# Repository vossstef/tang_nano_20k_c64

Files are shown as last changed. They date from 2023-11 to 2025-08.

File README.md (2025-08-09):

# C64Nano

The C64Nano is a port of some [MiST](https://github.com/mist-devel/mist-board/wiki) and
[MiSTer](https://mister-devel.github.io/MkDocs_MiSTer/) core components for the
[C64](https://en.wikipedia.org/wiki/Commodore_64):

| Board | FPGA | support |Note|
| --- | - | - |-|
| [Tang Nano 20k](https://wiki.sipeed.com/nano20k) | [GW2AR](https://www.gowinsemi.com/en/product/detail/38/)  | HDMI / LCD |Dualshock via MiSTeryShield20k spare header **or** Joy to DIP |
| [Tang Primer 25K](https://wiki.sipeed.com/hardware/en/tang/tang-primer-25k/primer-25k.html) | [GW5A-25](https://www.gowinsemi.com/en/product/detail/60/) | HDMI |no Dualshock, no Retro D9 Joystick, no MIDI |
| [Tang Mega 60k NEO](https://wiki.sipeed.com/hardware/en/tang/tang-mega-60k/mega-60k.html) | [GW5AT-60](https://www.gowinsemi.com/en/product/detail/60/) | HDMI / LCD | twin Dualshock |
| [Tang Mega 138k Pro](https://wiki.sipeed.com/hardware/en/tang/tang-mega-138k/mega-138k-pro.html)|[GW5AST-138](https://www.gowinsemi.com/en/product/detail/60/) | HDMI / LCD |twin Dualshock |
| [Tang Console 60K NEO](https://wiki.sipeed.com/hardware/en/tang/tang-console/mega-console.html)|[GW5AT-60](https://www.gowinsemi.com/en/product/detail/60/) | HDMI / LCD |twin Dualshock, no Retro D9 Joystick|

Be aware that the [VIC20](https://en.wikipedia.org/wiki/VIC-20) ([VIC20Nano](https://github.com/vossstef/VIC20Nano)),
[Atari 2600 VCS](https://en.wikipedia.org/wiki/Atari_2600) ([A2600Nano](https://github.com/vossstef/A2600Nano)), [Apple IIe](https://en.wikipedia.org/wiki/Apple_IIe) ([NanoApple2](https://github.com/vossstef/NanoApple2)) had been ported too in similar manner.  

This project relies on an external µC being connected to the Tang Nano 20K. You can use a [M0S Dock BL616](https://wiki.sipeed.com/hardware/en/maixzero/m0s/m0s.html), [Raspberry Pi Pico (W)](https://www.raspberrypi.com/documentation/microcontrollers/pico-series.html) or [esp32-s2](https://www.espressif.com/en/products/socs/esp32-s2)/[s3](https://www.espressif.com/en/products/socs/esp32-s3) and use the [FPGA companion firmware](http://github.com/harbaum/FPGA-Companion). Basically a µC acts as USB host for USB devices and as an OSD controller using a [SPI communication protocol](https://github.com/harbaum/MiSTeryNano/blob/main/SPI.md).

Onboard BL616 µC  
* If you don't need the WIFI modem on a TN20K then even the onboard BL616 µC (normally used for bitstream programming) can be used. A dedicated FPGA bitstream and FPGA companion firmware is needed in that configuration. The onboard BL616 µC is presently supported for TN20K and Console 60K boards. WIFI modem is supported on Console 60K too. There is an extern powered (see ->) [USB Hub](https://github.com/harbaum/FPGA-Companion/blob/main/console_usbhub_and_power_over_usb-a.png) + USB-A to USB-A cable + USB-A Power Supply Plug needed to supply the board and at the same time provide USB ports for USB Keyboard and e.g. USB Joystick or Mouse.

For the [M0S Dock](https://wiki.sipeed.com/hardware/en/maixzero/m0s/m0s.html) BL616 [µC](https://en.bouffalolab.com) there is a:

* [Optional custom carrier board MiSTeryShield20k](https://github.com/harbaum/MiSTeryNano/tree/main/board/misteryshield20k/README.md)
* [M0S PMOD Adapter](https://github.com/harbaum/MiSTeryNano/blob/main/board/m0s_pmod) for Primer / Mega / Console Boards
* [Optional case](https://github.com/harbaum/MiSTeryNano/blob/main/board/misteryshield20k/housing3D)
* [Dualshock Adapter / Cable](/board/misteryshield20k_ds2_adapter/misteryshield20k_ds2_adapter_cable.md)

and for the Raspberry PiPico (RP2040 µC) there is a:

* [Optional custom carrier board MiSTeryShield20k Raspberry PiPico](/board/misteryshield20k_rpipico/README.md)
* [Dualshock Adapter / Cable](/board/misteryshield20k_ds2_adapter/misteryshield20k_ds2_adapter_cable.md)
* [Optional custom PMOD RP2040-Zero](/board/pizero_pmod/README.md) for Primer / Mega / Console Boards
* [Optional custom PMOD PiPico W](/board/pipico_pmod/README.md) incl. WIFI-modem for Primer / Mega / Console Boards
  
Original C64 core by Peter Wendrich and c1541 by [darfpga](https://github.com/darfpga).  
All HID components and µC firmware by Till Harbaum

Features:

* PAL 800x576p@50Hz or NTSC 800x480p@60Hz HDMI Video and Audio Output
* TFT-LCD module 800x600 [SH500Q01Z](https://dl.sipeed.com/Accessories/LCD/500Q01Z-00%20spec.pdf) + Speaker support
* USB Keyboard
* [USB Joystick](https://en.wikipedia.org/wiki/Joystick) or [USB Gamepad](https://en.wikipedia.org/wiki/Gamepad)
* [USB Mouse](https://en.wikipedia.org/wiki/Computer_mouse) as [c1351](https://en.wikipedia.org/wiki/Commodore_1351) Mouse emulation
* [USB Gamepad](https://en.wikipedia.org/wiki/Gamepad) Stick as [Paddle](https://www.c64-wiki.com/wiki/Paddle) Emulation
* [USB XBOX 360 Controller](https://en.wikipedia.org/wiki/Xbox_360_controller) as Joystick or Paddle
* [legacy D9 Joystick](https://en.wikipedia.org/wiki/Atari_CX40_joystick) (Atari / Commodore digital type)
* Joystick emulation on Keyboard Numpad
* [Dualshock 2 Controller Gamepad](https://en.wikipedia.org/wiki/DualShock) for [MiSTeryShield20k](https://github.com/harbaum/MiSTeryNano/tree/main/board/misteryshield20k/README.md) via spare [pinheader](/board/misteryshield20k_ds2_adapter/misteryshield20k_ds2_adapter_cable.md). Adapter [venice1200](https://github.com/venice1200)
* [Dualshock 2 Gamepad](https://en.wikipedia.org/wiki/DualShock) DPad / left Stick as Joystick
* [Dualshock 2 Gamepad](https://en.wikipedia.org/wiki/DualShock) Sticks as [Paddle](https://www.c64-wiki.com/wiki/Paddle) Emulation (analog mode)
* Emulation of [C64GS Cheetah Annihilator](https://en.wikipedia.org/wiki/Commodore_64_Games_System) Joystick 2nd Trigger Button (Pot X/Y)
* emulated [1541 Diskdrive](https://en.wikipedia.org/wiki/Commodore_1541) on FAT/extFAT microSD card with parallel bus [Speedloader Dolphin DOS 2](https://rr.pokefinder.org/wiki/Dolphin_DOS). [GER manual](https://www.c64-wiki.de/wiki/Dolphin_DOS)
* c1541 DOS ROM selection
* Cartridge ROM (*.CRT) loader
* Direct BASIC program (*.PRG) injection loader
* Tape (*.TAP) image loader as [C1530 Datasette](https://en.wikipedia.org/wiki/Commodore_Datasette)
* Loadable 8K Kernal ROM (*.BIN)
* [VIC-II](https://en.wikipedia.org/wiki/MOS_Technology_VIC-II) revision and [6526](https://en.wikipedia.org/wiki/MOS_Technology_CIA) / 8521 selection
* [SID](https://en.wikipedia.org/wiki/MOS_Technology_6581) revision 6581 or 8580 selectable
* 2nd dual SID Option and loadable Filter curves
* emulated [RAM Expansion Unit (REU)](https://en.wikipedia.org/wiki/Commodore_REU) or [GeoRAM](https://en.wikipedia.org/wiki/GeoRAM)
* On Screen Display (OSD) for configuration and loadable image selection (D64/G64/CRT/PRG/BIN/TAP/FLT)
* Physical MIDI-IN and OUT
* RS232 Serial Interface [VIC-1011](http://www.zimmers.net/cbmpics/xother.html) or [UP9600](https://www.pagetable.com/?p=1656) mode to Tang onboard USB-C serial port or external hw pin.
* Swiftlink-232 [6551](https://en.wikipedia.org/wiki/MOS_Technology_6551) WIFI Modem Interface to FPGA-Companion up to 38400 Baud
* Freezer support (e.g. Action Replay)

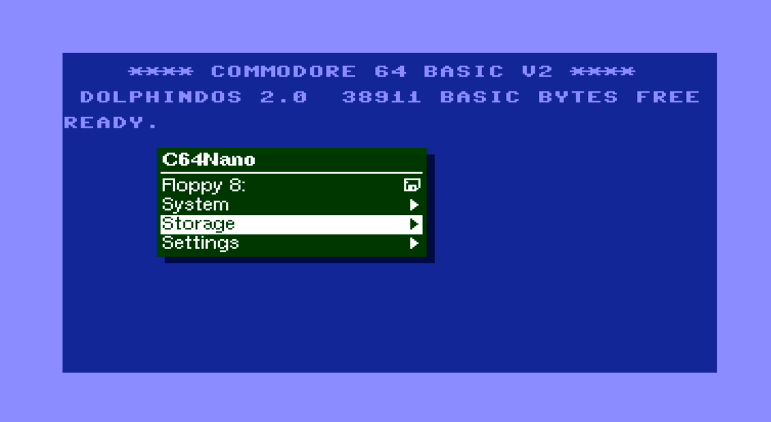
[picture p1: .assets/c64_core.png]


## Installation

The installation of C64 Nano on the Tang Nano 20k board can be done using a Linux PC or a Windows PC
[(Instruction)](INSTALLATION_WINDOWS.md).

## c64 Nano on Tang Primer 25K

See [Tang Primer 25K](TANG_PRIMER_25K.md). PMOD TF-CARD V2 is required !

## c64 Nano on Tang Mega 60k NEO

See [Tang Mega 60K NEO](TANG_MEGA_60K.md)

## c64 Nano on Tang Mega 138k Pro

See [Tang Mega 138K Pro](TANG_MEGA_138Kpro.md)

## c64 Nano on Tang Console 60k NEO

See [Tang Console 60K NEO](TANG_CONSOLE_60K.md)

## c64 Nano with LCD and Speaker

See [Tang Nano LCD](TANG_NANO_20k_LCD.md)

## emulated Diskdrive c1541

Emulated 1541 on a regular FAT/exFAT formatted microSD card including parallel bus Speedloader Dolphin DOS 2.0.
Copy a D64 Disk image to your sdcard and rename it to **disk8.d64** as default boot image.
Add further D64 or G64 images as you like and insert card in TN slot. LED 0 acts as Drive activity indicator.

> [!TIP]
> Disk directory listing: [(or F7 keypress)](https://project64.c64.org/hw/dolphindos.txt)  
> command:  
> LOAD"$",8  
> LIST  
> Load first program from Disk: (or just LOAD if Dolphin Kernal active)  
> LOAD"*",8  
> RUN  

c1541 DOS ROM can be selected from OSD (default Dolphin DOS 2.0, CBM DOS, SpeedDos Plus or JiffyDOS)
In case a program don't load correctly select via OSD the factory default CBM DOS an give it a try.

## Cartridge ROM Loader (.CRT)

Cartridge ROM can be loaded via OSD file selection.
Copy a *.CRT to your sdcard and rename it to **c64crt.crt** as default boot cartridge ROM.
Prevent the cartridge load at boot by OSD CRT selection **No Disk** , **Save settings** and System **Cold Boot**.
> [!TIP]
> **Detach Cartridge** by OSD:
> ```temporary``` **Cartridge unload & Reset** ```permanent``` **No Disk**, **Save settings** and System **Cold Boot**

> [!IMPORTANT]
> Be aware that some Freezer Card CRT might require to use the standard C64 Kernal and the standard C1541 CBM DOS.

## BASIC Program Loader (.PRG)

A BASIC Program *.PRG file can be loaded via OSD file selection.
Copy a .PRG to your sdcard and rename it to **c64prg.prg** as default boot basic program. Prevent the PRG load at boot by OSD PRG selection **No Disk** , **Save settings** and **Reset** or System **Cold Boot**.
> [!TIP]
> Check loaded file by command: **LIST**

> [!IMPORTANT]
> command: **RUN**

## Tape Image Loader (*.TAP)

A [Tape](https://en.wikipedia.org/wiki/Commodore_Datasette) *.TAP file can be loaded via OSD file selection
In order to start a tape download choose C64 CBM Kernal (mandatory as Dolphin DOS doesn't support Tape). Best to save Kernal OSD selection via **Save settings**.
> [!IMPORTANT]
> command: **LOAD**  
> ___ Only if you have [Exbasic Level II](https://www.c64-wiki.de/index.php?title=Exbasic_Level_II&oldid=261004). CRT Basic loaded then use command: 
> **LOAD***  
> Screen will blank!

The file is loaded automatically as soon as TAP file selected via OSD (no need to press PLAY TAPE button) in case ***no** TAP had been previously selected*.
As mentioned screen will blank for several seconds and then display briefly the filename of the to be loaded file. It will blank shortly afterwards again till load completed and take a lot of time...
Copy a *.TAP to your sdcard and rename it to **c64tap.tap** as default tape mountpoint.
For **Tape unload** use OSD TAP selection **No Disk** and **Reset** or System **Cold Boot**
> [!WARNING]
> After board power-up or coldboot a TAP file will **not autoloaded** even if TAP file selection had been saved or c64tap.tap mountpoint available !
> Unblock loader by OSD TAP selection **No Disk** or simply select again the desired TAP file to be loaded after you typed **LOAD**

> [!TIP]
> Check loaded file by command: **LIST**

> [!IMPORTANT]
> command: **RUN**

> [!NOTE]
> The available (muffled) Tape Sound audio can be disabled from OSD.

## Kernal Loader (.BIN)

The build-in Dolphin Kernal is the power-up default C64 Kernal with an excellent C1541 speedloader.
> [!TIP]
> If you are fine with that then there is no need to load another Kernal via OSD and just select OSD Kernal BIN selection **No Disk** and **Save settings**!

In general Kernal ROM files *.BIN can be loaded via OSD selection.
Copy a 8K C64 Kernal ROM .BIN to your sdcard and rename it to **c64kernal.bin** as default boot Kernal.
Prevent Kernal load by OSD Kernal BIN selection **No Disk** and **Save settings** and do a **power-cyle** of the board. In this case the build-in Dolphin Kernal will by default be used after next power cycle.

## SID Filter Curve (.FLT)

Custom Filters curves can optionally be loaded via OSD.
> [!TIP]https://www.telnetbbsguide.com/bbs/software/image-bbs/
> This is in most cases not needed and build-in filters curves are already an optimum.

> [!NOTE]
> Remember to select the 6581 chip, not the 8580.
> Select 'Custom 1' as the filter to activate it. When a custom filter is loaded, there's no difference between custom options Custom 1, 2, and 3. Selecting 'Default' switches back to the built-in filter curve.
https://www.telnetbbsguide.com/bbs/software/image-bbs/
Prevent Filter curve load by OSD Kernal **FLT** selection **No Disk** and **Save settings** and **power-cyle** of the board.

## Core Loader Sequencing

The core will after power cycle/ cold-boot start downloading the images on the sdcard in the following order:

> [!NOTE]
> (1) BIN Kernal, (2) CRT ROM, (3) PRG Basic and finally (4) FLT.

## emulated RAM Expansion Unit REU 1750

For those programs the require a [RAM Expansion Unit (REU)](https://en.wikipedia.org/wiki/Commodore_REU) it can be activated by OSD on demand.

Playing [Sonic the Hedgehog V1.2](https://csdb.dk/release/?id=212523)
Enable REU, and load the PRG.  
Playing around with [GEOS](https://en.wikipedia.org/wiki/GEOS_(8-bit_operating_system))
Enable REU, select c1541 CBM DOS ROM and load the PRG.

## Push Button / DIP Switch utilization

* S1 swap the Joystick Ports if OSD **Swap Joys** is set to Off mode.

* S2 open OSD

> [!CAUTION]
> A FLASH programm attempt without keeping the board in reset may lead to corruption of the C1541 DOS images stored in FLASH requiring re-programming.
> Nano 20k S2 keep pressed during power-up for FLASH programming of FPGA bitstream  

## OSD

invoke by F12 keypress

* Reset
* Cold Reset + memory scrubbing
* Audio Volume + / -
* Scanlines effect %
* Widescreen activation
* HID device selection for Joystick Port 1 and Port 2
* REU activation
* c1541 Drive disk image selection
* c1541 Disk write protetcion
* c1541 Reset
* c1541 DOS ROM selection
* MIDI configuration
* PAL / NTSC Video mode
* VIC-II revision, 6526 / 8521 and SID 6561/8580 selection
* SID Filter selection
* geoRAM activation
* Loader (CRT/PRG/BIN/TAP/FLT) file selection
* Joystick Port Swap
* Cartridge unload

## Gamecontrol support

<u>legacy single D9 Digital Joystick.</u>  
OSD: **Retro D9**
Atari ST type of Joystick 2nd button supported using a MiSTeryNano shield.  
Don't configure e.g. [ArcadeR](https://retroradionics.com) for C64 mode rather than normal digital 2nd button mode (2nd trigger button connect signal to ground)

<u>USB Joystick(s)</u>.  
OSD: **USB #1 Joy** or **USB #2 Joy**
Also [RII Mini Keyboard i8](http://www.riitek.com/product/220.html) left Multimedia Keys are active if **USB #1 Joy** selected.

<u>Dualshock 2 Gamepad Stick or Dpad as Joystick.</u>.  
OSD: **DS #1 Joy** or **DS #2 Joy**
At the moment Dpad only for original Pad. Some clone devices support at the same time Dpad and left stick simultaniously. ```circle and cross``` Buttons as Trigger:

> [!IMPORTANT]
> In a [MiSTeryShield20k](https://github.com/harbaum/MiSTeryNano/tree/main/board/misteryshield20k) configuration Dualshock is supported via the internal ``spare J8`` pinheader.
> See [MiSTeryShield20k DS2 Adapter / Cable](/board/misteryshield20k_ds2_adapter/misteryshield20k_ds2_adapter_cable.md) for further information. Thx [venice1200](https://github.com/venice1200) !

> [!NOTE]
> TN20k: You have to select OSD **DS2 #2 Joy** or **DS #2 Paddle** for a ``MiSTeryShield20k`` configuration.
> TN20k: You have to select OSD **DS2 #1 Joy** or **DS #1 Paddle** if you use the ``Sipeed Joy to DIP`` adapter.
> Single DS interface active at the same time!

<u>Keyboard Numpad.</u>  
OSD: **Numpad**

|Numpad| |Numpad|
|-|-|-|
|0  Trigger|8  Up|.  Trigger 2|
|4  Left|-|6  Right|
|-|2  Down|-|

<u>Mouse.</u>  
OSD: **Mouse**
USB Mouse as c1351 Mouse emulation.

<u>Dualshock 2 Gamepad</u> as Paddle  
OSD: **DS #1 Paddle** or **DS #2 Paddle**
Dualshock left Stick in analog mode as VC-1312 Paddle emulation.
ANALOG Paddle mode will be indicated by DS 2 red light indicator.
> [!NOTE]
> TN20k:
> single Dualshock support only
> 4 Paddles mapped to a single Gamepad (X/Y) and both Sticks.
> **square** , **cross**, **circle** and **triangle** used as 4 Trigger buttons
> ``Joyport 1:``  **DS2 #1 Paddle**
> ``Joyport 2:``  **DS2 #1 Paddle**
> or<br>
> ``Joyport 1:``  **DS2 #2 Paddle**
> ``Joyport 2:``  **DS2 #2 Paddle**

<u>USB Paddle</u>.  
OSD: **USB #1 Padd** or **USB #2 Padd**
Left Stick in X / Y analog mode as VC-1312 Paddle emulation.
Button **cross / square** as Trigger

## Keyboard

 ![Layout](\.assets/keymap.gif)
 PAGE UP (Tape Play) Key or the Tang S1 Button swap the Joystick Ports if OSD **Swap Joys** is set to Off mode.

 F2,F4,F6,F8,Left/Up keys automatically activate Shift key.  
 F9 - arrow-up key.  
 F10 - = key.  
 F11 (RESTORE) Key as ``FREEZE``. Typically used by Freezer Cards like Action Replay, Snappy Rom etc.  
 F12 OSD  
 Alt,Tab - C= key.  

## LED UI

| LED | function    | TN20K | TP25K |TM60K|TM138K Pro|Console60K|
| --- |           - | -     | -     | -    |-  |-|
| 0 | c1541 activity| x     | x     | x    |x  |x|
| 1 | D64 selected  | x     | x     | x    |x  |-|
| 2 | CRT seleced   | x     | -     |   -  |x  |-|
| 3 | PRG selected  | x     | -     |   -  |x  |-|
| 4 |Kernal selected| x     | -     |   -  |x  |-|
| 5 | TAP selected  | x     | -     |   -  |x  |-|

Solid **<font color="red">red</font>** of the c1541 led after power-up indicates a missing DOS in Flash

## Multicolor RGB LED

* **<font color="green">green</font>**&ensp;&thinsp;&ensp;&thinsp;&ensp;&thinsp;all fine and ready to go
* **<font color="red">red</font>**&ensp;&thinsp;&ensp;&thinsp;&ensp;&thinsp;&ensp;&thinsp;&ensp;&thinsp;something wrong with SDcard / default boot image
* **<font color="blue">blue</font>**&ensp;&thinsp;&ensp;&thinsp;&ensp;&thinsp;&ensp;&thinsp;µC firmware detected valid FPGA core
* **<font color="yellow">yellow</font>**&ensp;&thinsp;&ensp;&thinsp;&ensp;&thinsp;FPGA core can't detect valid firmware
* **white**&ensp;&thinsp;&ensp;&thinsp;&ensp;&thinsp;-

## MIDI-IN and OUT

<s>Type of MIDI interface can be selected from OSD. There is support for Sequential Inc., Passport/Sentech, DATEL/SIEL/JMS/C-LAB and Namesoft. You can use a [MiSTeryNano shield](https://github.com/harbaum/MiSTeryNano/tree/main/board/misteryshield20k/README.md) to interface to a Keyboard.</s>

## RS232 Serial Interface Swiftlink-232 <-> WIFI Modem

Have a look: [Wiki WIFI Modem](https://github.com/harbaum/FPGA-Companion/wiki/AT-Wi%E2%80%90Fi-modem)  

Most Terminal programs need the Kernal serial routines therefore select via OSD the CBM Kernal rather than default DolphinDOS.  
In addition select OSD System RS232 mode ``Swiftlink DE``. Also possible ACIA [6551](https://en.wikipedia.org/wiki/MOS_Technology_6551) addresses are: $DE00 (default), $DF00 or $D700.  

> [!NOTE]
> Don't forget to active the ``PETSCII`` character input mode if you are sending commands to the modem !

For a PETSCII or ASCII/ANSI BBS you can use [ccgms](https://github.com/mist64/ccgmsterm).  
Press ``F8`` and select modem ``Swiftlink DE`` and Baudrate of ``38400``.  
You can press ``Shift F8`` to toggle in between the different character [modes](https://github.com/mist64/ccgmsterm/blob/main/Documentation.md).  
Connect to you WIFI AP and have a try: ``ATD`` [bbs.retrocampus.com:6510](https://bbs.retrocampus.com) or just have a look at [telnetbbsguide](https://www.telnetbbsguide.com/bbs/software/image-bbs) and choose as you like.  

For a more exotic Turbo56k protocol BBS use [retroterm](https://github.com/retrocomputacion/retroterm).  

Note: Enabling persitent the Swiftlink-232 ACIA 6551 component at $FE00 will block other things like Multicard CRT ROMS. Adress $D700 doesn't block other HW.

## RS232 Serial Interface VIC-1011/UP9600 <-> USB-C / external HW pins

The Tang onboard USB-C serial port can be used for communication with the C64 Userport Serial port in [VIC-1011](http://www.zimmers.net/cbmpics/xother.html) or [UP9600](https://www.pagetable.com/?p=1656) mode. Terminal programs need the Kernal serial routines therefore select via OSD the CBM Kernal rather than default DolphinDOS. For a first start use UP9600 mode and a Terminal program like [ccgms](https://github.com/mist64/ccgmsterm) and on the PC side [Putty](https://www.putty.org) with 2400 Baud.

OSD selection allows to change in between TANG USB-C port or external HW pin interface.

| Board      |RX (I) FPGA |TX (O) FPGA|Note|
|  -         |   -    |   -  | -   |
| TN20k      |75      | 76   | |
| TP25k      |K5      | L5   | J4-6  J4-5, share M0S Dock PMOD|
| TM60k NEO  |AB20    | AA19 | J24-6 J24-5, share M0S Dock PMOD |
| TM138k Pro |H15     | H14  | J24-6 J24-5, share M0S Dock PMOD |

Remember that in + out to be crossed to connect to external device. Level are 3V3 tolerant.

## Powering

Prototype circuit with Keyboard can be powered by Tang USB-C connector from PC or a Power Supply Adapter.

## Synthesis

Source code can be synthesized, fitted and programmed with GOWIN IDE Windows or Linux.

Alternatively use the command line build script **gw_sh.exe / gw_sh.sh** [build_tn20k.tcl](build_tn20k.tcl) , [build_tp25k.tcl](build_tp25k.tcl) or [build_tm138k.tcl](build_tm138k.tcl)

## HW circuit considerations

**Pinmap TN20k Interfaces**
 Sipeed M0S Dock, digital Joystick D9 and DualShock Gamepad connection.
 ![wiring](\.assets/wiring_spi_irq.png)

## Pinmap D-SUB 9 Joystick Interface

* Joystick interface is 3.3V tolerant. Joystick 5V supply pin has to be left floating !

![pinmap](\.assets/vic20-Joystick.png)

|Joystick pin|IO   |Tang Nano pin| FPGA pin |Joystick Function|
|----------- |-----| ---         | -------- |-----            |
| 1          |2    | J6 10       | 25       | UP              |
| 2          |1    | J6 9        | 28       | DOWN            |
| 3          |4    | J6 12       | 29       | LEFT            |
| 4          |3    | J5 11       | 26       | RIGHT           |
| 5          |-    | -           | -        | POT Y/ TRIGGER 3|
| 6          |0    | J5 8        | 27       | TRIGGER         |
| 7          |-    | n.c         | n.c      | 5V              |
| 8          |-    | J5 20       | -        | GND             |
| 9          |-    | -           | 30       | TRIGGER 2       |

## Pinmap Dualshock 2 Controller Interface

<img src="./.assets/controller-pinout.jpg" alt="image" width="30%" height="auto">

| DS pin | Tang Nano pin | FPGA pin | DS Function |
| ----------- | ---   | --------  | ----- |
| 1 | J5 18 | 71 MISO | JOYDAT  |
| 2 | J5 19 | 53 MOSI  | JOYCMD |
| 3 | n.c. | - | 7V5 |
| 4 | J5 15 | - | GND |
| 5 | J5 16| - | 3V3 |
| 6 | J5 17 | 72 CS | JOYATN|
| 7 | J5 20 | 52 MCLK | JOYCLK |
| 8 | n.c. | - | JOYIRQ |
| 9 | n.c. | - | JOYACK |

## Getting started

In order to use this Design the following things are needed:

[Sipeed M0S Dock](https://wiki.sipeed.com/hardware/en/maixzero/m0s/m0s.html) or Raspberry Pi Pico RP2040 or ESP32-S2/S3  
[Sipeed Tang Nano 20k](https://wiki.sipeed.com/nano20k)  
or [Sipeed Tang Primer 25k](https://wiki.sipeed.com/hardware/en/tang/tang-primer-25k/primer-25k.html)  
and [PMOD DVI](https://wiki.sipeed.com/hardware/en/tang/tang-PMOD/FPGA_PMOD.html#PMOD_DVI)  
and [PMOD TF-CARD V2](https://wiki.sipeed.com/hardware/en/tang/tang-PMOD/FPGA_PMOD.html#PMOD_TF-CARD)  
and [PMOD SDRAM](https://wiki.sipeed.com/hardware/en/tang/tang-PMOD/FPGA_PMOD.html#TANG_SDRAM)  
and [M0S PMOD adapter](https://github.com/harbaum/MiSTeryNano/tree/main/board/m0s_pmod/README.md)  
or ad hoc wiring + soldering.
or [Sipeed Tang Mega 138k Pro](https://wiki.sipeed.com/hardware/en/tang/tang-mega-138k/mega-138k-pro.html)  
and [PMOD SDRAM](https://wiki.sipeed.com/hardware/en/tang/tang-PMOD/FPGA_PMOD.html#TANG_SDRAM)  
and [PMOD DS2x2](https://wiki.sipeed.com/hardware/en/tang/tang-PMOD/FPGA_PMOD.html#PMOD_DS2x2)  
and [M0S PMOD adapter](https://github.com/harbaum/MiSTeryNano/tree/main/board/m0s_pmod/README.md)  
or [Tang Mega 60K NEO](https://wiki.sipeed.com/hardware/en/tang/tang-mega-60k/mega-60k.html)  
and [PMOD SDRAM](https://wiki.sipeed.com/hardware/en/tang/tang-PMOD/FPGA_PMOD.html#TANG_SDRAM)  
and [PMOD DS2x2](https://wiki.sipeed.com/hardware/en/tang/tang-PMOD/FPGA_PMOD.html#PMOD_DS2x2)  
and [M0S PMOD adapter](https://github.com/harbaum/MiSTeryNano/tree/main/board/m0s_pmod/README.md)  
or [Tang Console 60K NEO](https://wiki.sipeed.com/hardware/en/tang/tang-console/mega-console.html)  
and [PMOD DS2x2](https://wiki.sipeed.com/hardware/en/tang/tang-PMOD/FPGA_PMOD.html#PMOD_DS2x2)  
and [Sipeed M0S Dock](https://wiki.sipeed.com/hardware/en/maixzero/m0s/m0s.html)
and [M0S PMOD adapter](https://github.com/harbaum/MiSTeryNano/tree/main/board/m0s_pmod/README.md)  
or a [PMOD RP2040-Zero](/board/pizero_pmod/README.md)  

microSD or microSDHC card FAT32 formatted  
TFT Monitor with HDMI Input and Speaker

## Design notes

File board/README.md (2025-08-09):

# MiSTeryShield20k boards

The MiSTeryNano can be used with off-the-shelf components and
some breadboard setup.

To simplify this this project provides additional
hardware:

Standalone Dock Solution for a BL616 µC M0S DOCK (WIFI):  
[MiSTeryShield20k](https://github.com/harbaum/MiSTeryNano/tree/main/board/misteryshield20k/README.md)

Standalone Dock Solution for a RP2040 µC Raspberry PiPico (WIFI):  
[MiSTeryShield20k RPiPico](/board/misteryshield20k_rpipico/README.md)

Dualshock DS2 Adapter / Cable  
To be to be used with any Dock  
[MiSTeryShield20k DS2 Adapter / Cable](misteryshield20k_ds2_adapter\misteryshield20k_ds2_adapter_cable.md)

[PIZero_PMOD](/board/pizero_pmod/README.md)  
PMOD based on a [RP2040-Zero](https://www.waveshare.com/wiki/RP2040-Zero)  
To be used in conjuction with Primer20k, Primer25k, Mega60k NEO, Mega138k NEO, Mega138kPro

[PIPico_PMOD](/board/pipico_pmod/README.md)  
PMOD based on a [Raspberry Pi Pico W](https://www.raspberrypi.com/documentation/microcontrollers/pico-series.html)  
To be used in conjuction with Primer20k, Primer25k, Mega60k NEO, Mega138k NEO, Mega138kPro

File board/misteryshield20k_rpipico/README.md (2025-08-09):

# MiSTeryShield20k RPiPico USB board

Features:

* Headers to plug the Tang Nano 20K
* Headers to plug the [Raspberry Pi Pico (W)](https://www.raspberrypi.com/products/raspberry-pi-pico)
* Atari / Commodore style joystick interface
  * Supports up to two buttons
  * Including 5V supply and 5V level shifters
  * Works with DB9 joystcks and mice
  * MIDI
    * MIDI OUT with driver chip to protect Tang Nano 20K
    * MIDI IN with optocoupler to protect Tang Nano 20K
* 4 x USB-A Interface
* Spare header for FPGA IO / [Dualshock 2 Adapter cable](/board/misteryshield20k_ds2_adapter/misteryshield20k_ds2_adapter_cable.md) (**no DS2 connector onboard**)
* Debug header for Pico UART and e.g. FPGA UART
* 3 x PiPico Status LED
* 3D STEP model to ease case development
* [CERN-OHL-S](https://cern-ohl.web.cern.ch/home) license

PCBA production files for [JLCPCB](https://jlcpcb.com) are availble [here](Output/production)  
(Fully assembled boards can orderd based on BOM partlist, excluding the TN20k and PiPico connector)  

The great PCB Layout work using [KiCad](https://www.kicad.org) had been done by [cantclosevi](https://github.com/cantclosevi). Thx Michal !

**Version history**
| Version  | Issue|  Change to earlier version|rework|
|---|-|---|-|
|0|engineering sample|DS2 connector rotated|mount DS2 bottom|
|1|DS2 rotation fixed|mechanical positioning|-|
|2|DS2 removed and positioning fixed|MIDI IN pin 4+5 reversed|[Instruction](rework/REWORK_HW2.MD)|
|3| none known |MIDI IN fix|-|

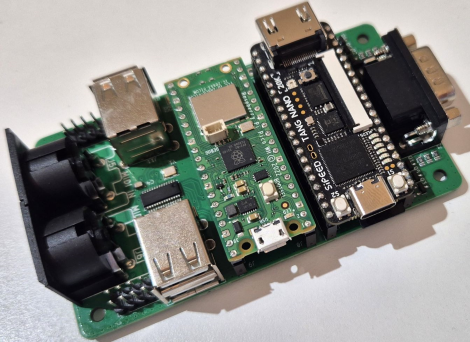
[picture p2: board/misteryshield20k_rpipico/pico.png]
RRPiPico
  
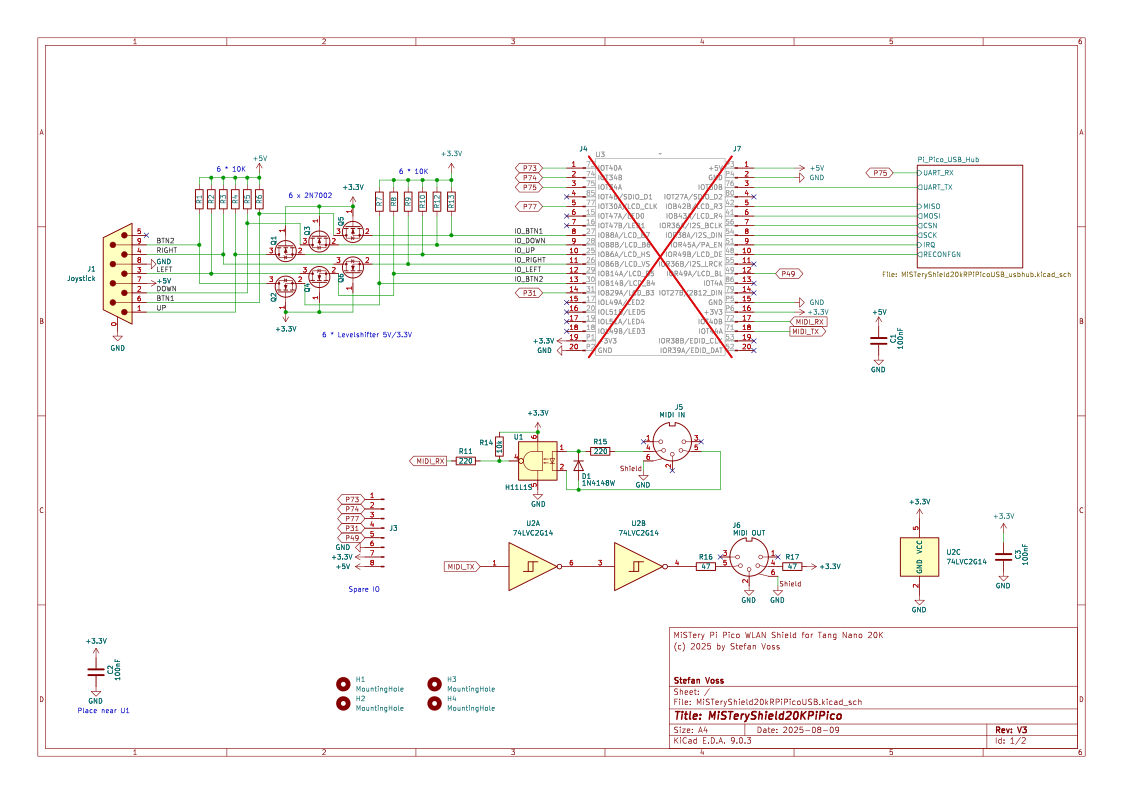
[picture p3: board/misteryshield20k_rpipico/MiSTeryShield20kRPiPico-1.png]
  
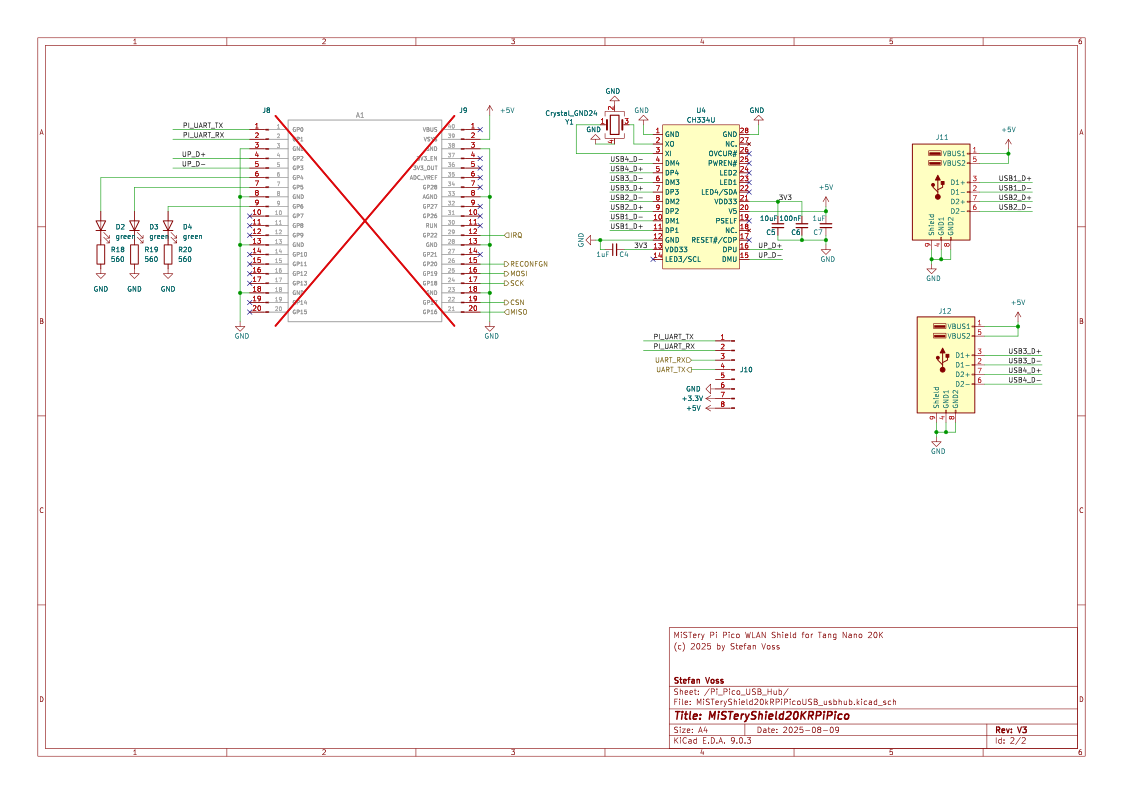
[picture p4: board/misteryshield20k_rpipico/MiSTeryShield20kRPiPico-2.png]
  
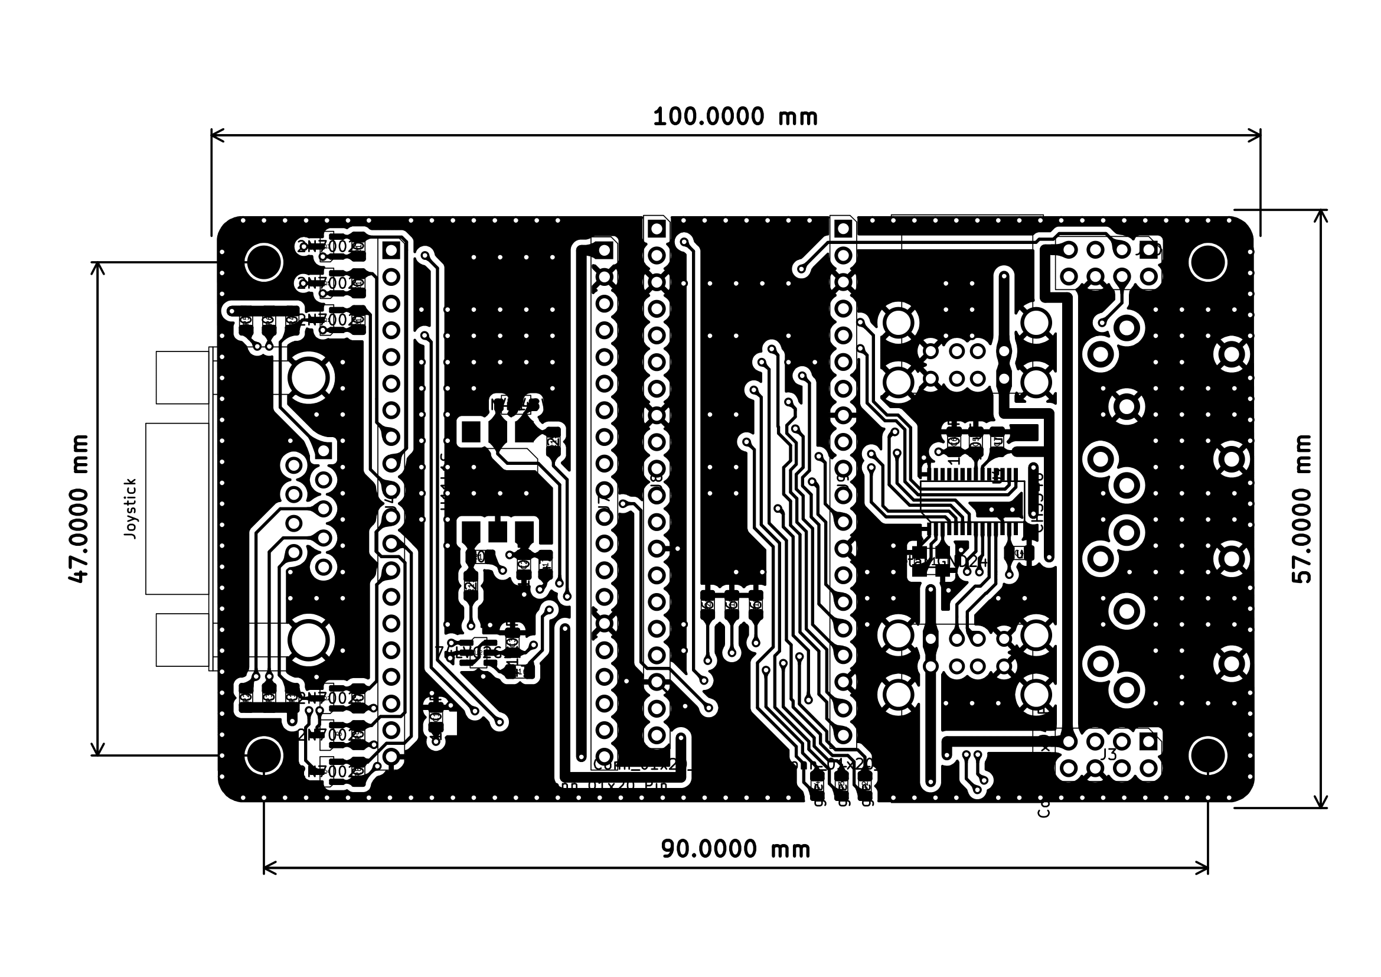
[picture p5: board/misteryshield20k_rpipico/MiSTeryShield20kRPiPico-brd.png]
  

# Pin usage

| Pin  | Signal | Description |
|---|---|---|
| GP0  | UART_TX| Serial debug output |
| GP1  | UART_RX| Serial debug input |
| GP2  | USB D+ | USB PIO host D+ |
| GP3  | USB D- | USB PIO host D- |
| GP4  | LED 1  | indicator mice |
| GP5  | LED 2  | indicator keyboard |
| GP6  | LED 3  | indicator joystick |
| GP16 | MISO | SPI data from FPGA |
| GP17 | CSn | SPI chip select to FPGA|
| GP18 | SCK | SPI clock to FPGA |
| GP19 | MOSI | SPI data to FPGA |
| GP20 |spare | spare |
| GP22 | IRQn | SPI interrupt from FPGA|

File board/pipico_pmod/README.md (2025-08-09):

# PMOD PiPico W

Features:
* PMOD carrier for a [Raspberry Pi Pico W](https://www.raspberrypi.com/documentation/microcontrollers/pico-series.html)
* USB-C to e.g. USB-C HUB or HID
* Debug header for Pico UART
* PMOD spare signals on Testpoints
* Status LED's
* [CERN-OHL-S](https://cern-ohl.web.cern.ch/home) license

PCBA production files for [JLCPCB](https://jlcpcb.com) are availble [here](production).  
(Fully assembled boards can orderd based on BOM partlist, excluding the RP2040)  

> [!IMPORTANT]
> Pin headers are already assembled  
> Take the RP2040 variant without pin headers !

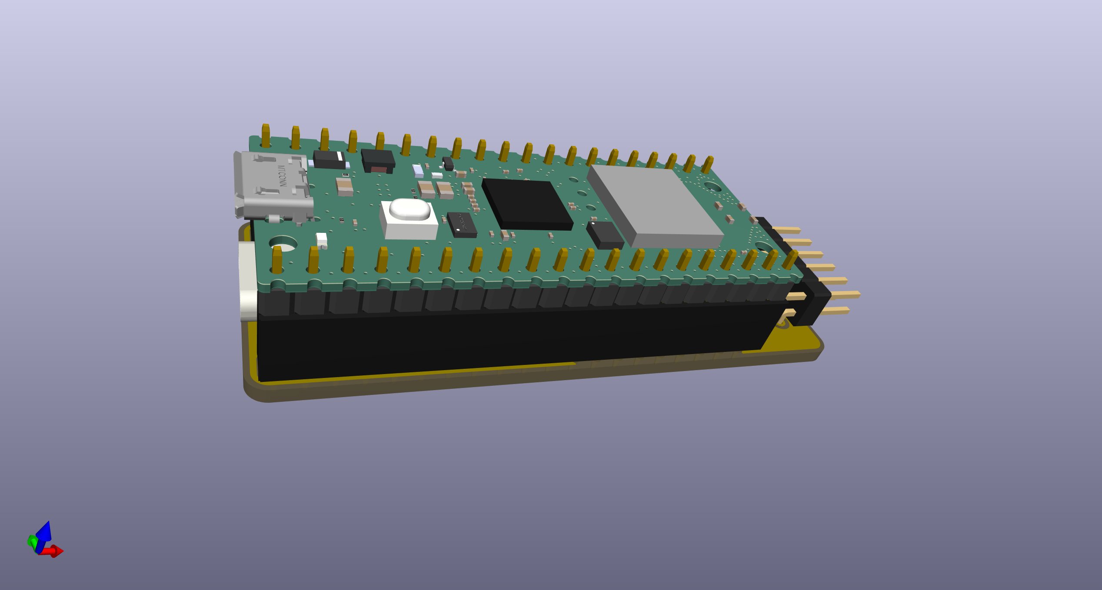
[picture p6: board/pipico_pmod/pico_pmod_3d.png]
  
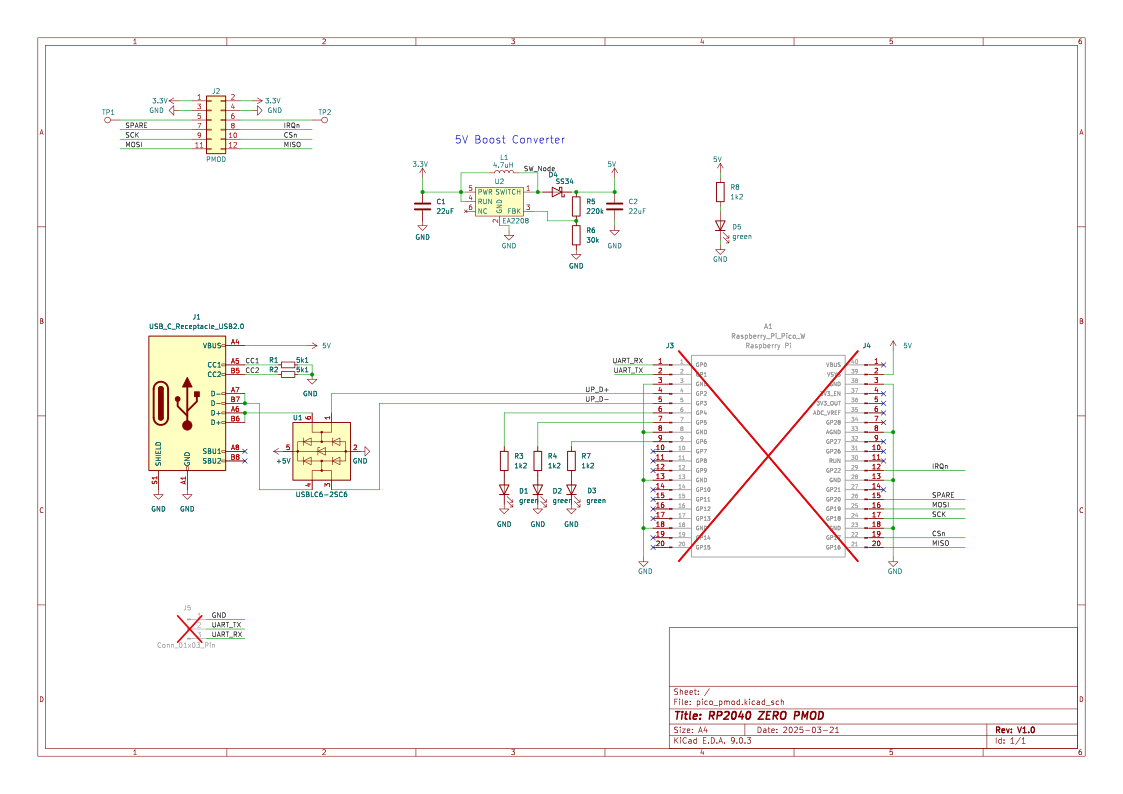
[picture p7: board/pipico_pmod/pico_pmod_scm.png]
  
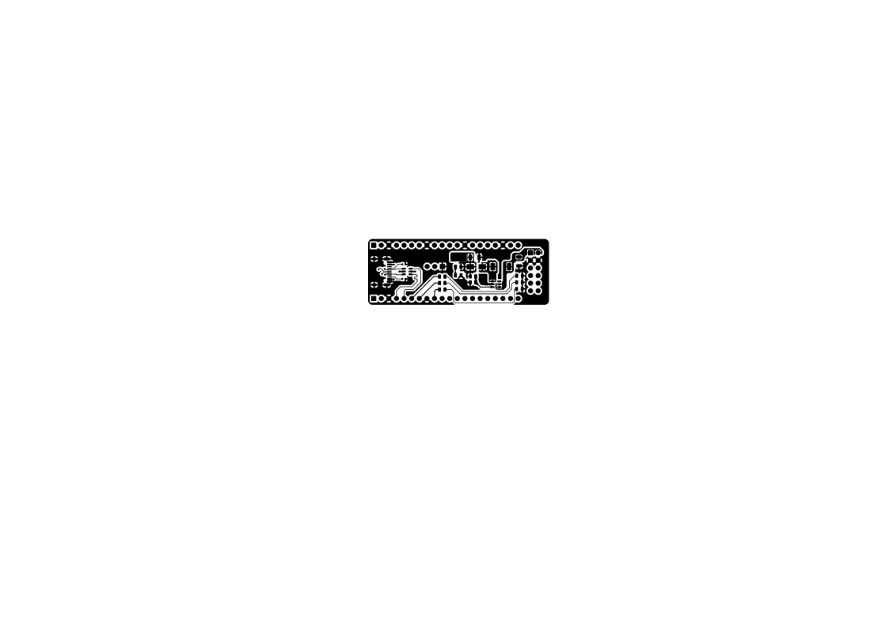
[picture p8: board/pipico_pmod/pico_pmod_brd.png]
  

| Pin | Signal | Description |
|---|---|---|
| GP0  | UART_TX  | Serial debug output |
| GP1  | UART_RX  | Serial debug input |
| GP2  | USB D+ | USB PIO host D+ |
| GP3  | USB D- | USB PIO host D- |
| GP4  | LED 1 | indicator mouse |
| GP5  | LED 2 | indicator keyboard |
| GP6  | LED 3 | indicator joystick |
| GP16 | MISO | SPI data from FPGA |
| GP17 | CSn | SPI chip select to FPGA |
| GP18 | SCK | SPI clock to FPGA |
| GP19 | MOSI | SPI data to FPGA |
| GP22 | IRQn | SPI interrupt from FPGA |

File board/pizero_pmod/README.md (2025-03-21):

# PMOD PI-Zero

Features:
* PMOD carrier for a [RP2040-ZERO](https://www.waveshare.com/wiki/RP2040-Zero)
* USB-C to a USB-C HUB
* Debug header for Pico UART
* PMOD spare signals on Testpoints
* [CERN-OHL-S](https://cern-ohl.web.cern.ch/home) license

PCBA production files for [JLCPCB](https://jlcpcb.com) are availble [here](production).  
(Fully assembled boards can orderd based on BOM partlist, excluding the RP2040-Zero)  

> [!IMPORTANT]
> Pin headers are already assembled  
> Take the RP2040-Zero variant without pin headers !

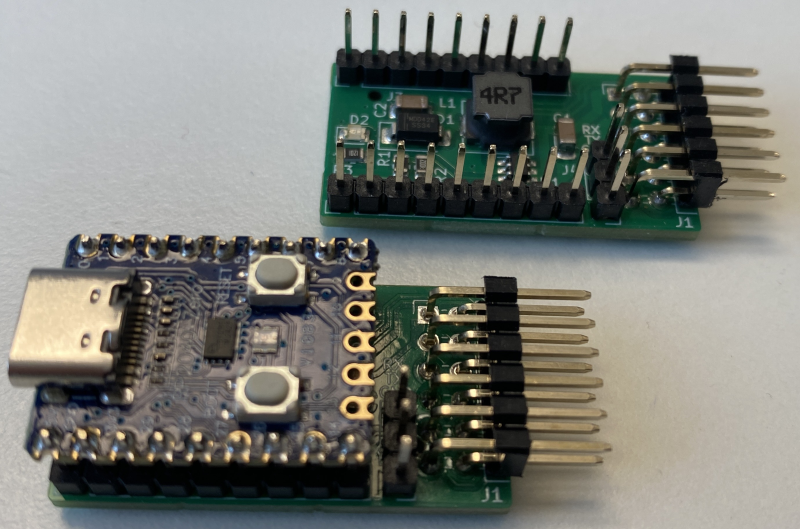
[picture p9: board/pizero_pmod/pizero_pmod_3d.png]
  
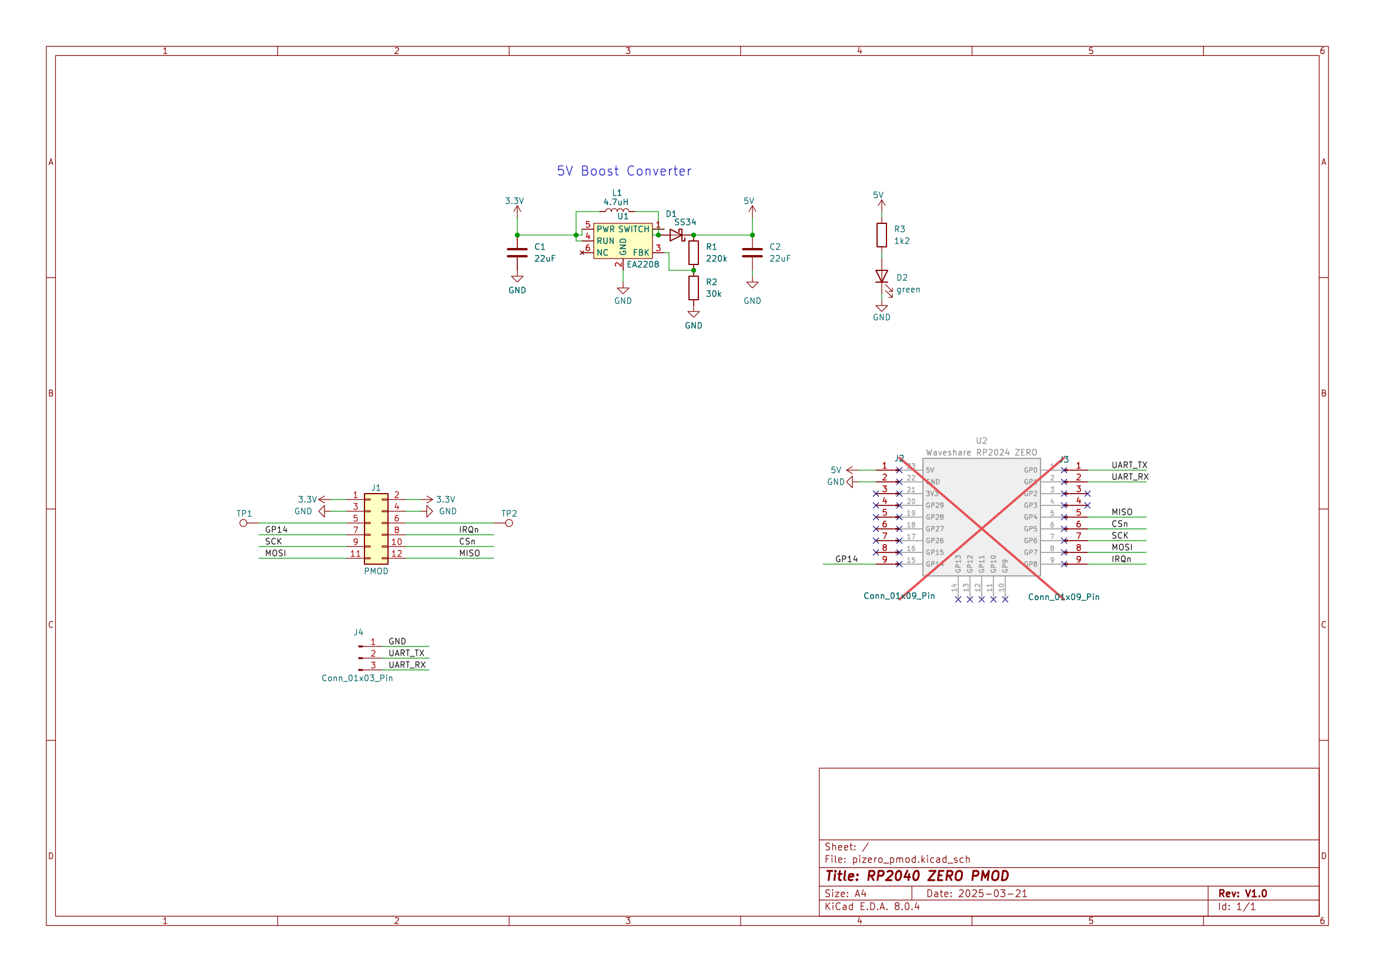
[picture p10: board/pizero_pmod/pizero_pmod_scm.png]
  
PNG  

| Pin | Signal | Description |
|-----|---|---|
| GP0 | UART_TX  | Serial debug output |
| GP1 | UART_RX  | Serial debug input  |
| GP4 | MISO | SPI data from FPGA  |
| GP5 | CSn | SPI chip select to FPGA |
| GP6 | SCK | SPI clock to FPGA |
| GP7 | MOSI | SPI data to FPGA |
| GP8 | IRQn | SPI interrupt from FPGA |
| GP14| spare | spare |

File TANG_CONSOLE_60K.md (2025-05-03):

# C64 Nano on Tang Console 60K NEO

C64 Nano can be used in the [Tang Console 60K NEO](https://wiki.sipeed.com/hardware/en/tang/tang-console/mega-console.html).

Besides the significantly bigger FPGA over the Tang Nano 20K, the Tang Mega 60K adds several more features of
which some can be used in the area of retro computing as well. 

The Tang Console comes with DDR3-SDRAM as well as a slot for the [Tang
SDRAM](https://wiki.sipeed.com/hardware/en/tang/tang-PMOD/FPGA_PMOD.html#TANG_SDRAM). Using
this board allows to use the same SDR-SDRAM memory access
methods.  

The [M0S Dock BL616](https://wiki.sipeed.com/hardware/en/maixzero/m0s/m0s.html) required to control the C64 Nano is to be mounted in the
**lower right PMOD** connector with the help of the [M0S PMOD Adapter](https://github.com/harbaum/MiSTeryNano/blob/main/board/m0s_pmod).

Alternatively a [PMOD RP2040-Zero](/board/pizero_pmod/README.md) can be plugged right away into the **lower right PMOD** connector.

An optional Plastation Dualshock 2 PMOD may by inserted in the second PMOD
closer to the HDMI connector. 

Both Audio Amplifier and the LCD Interface for a 5" TFT-LCD module 800x480 Type [SH500Q01Z](https://dl.sipeed.com/Accessories/LCD/500Q01Z-00%20spec.pdf) (Ilitek ILI6122)
is in additionto HDMI actiavted.  

The firmware for the M0S Dock / PiPico is the [same version as for the Tang
Nano 20K and all other boards](https://github.com/harbaum/FPGA-Companion).

The whole setup will look like this:

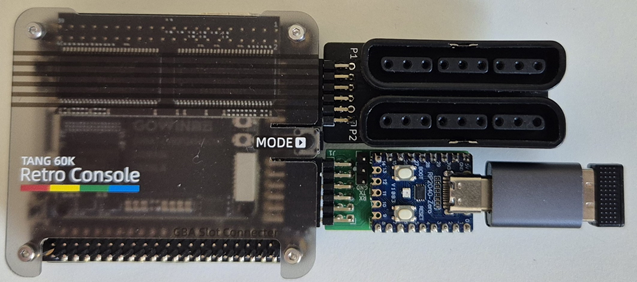
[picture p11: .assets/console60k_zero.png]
C64Nano on Console 60K NEO RP2040-Zero


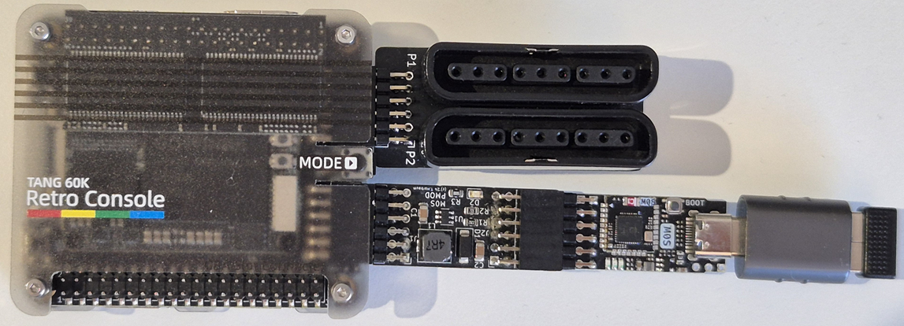
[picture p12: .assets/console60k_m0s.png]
C64Nano on Console 60K NEO M0S Dock


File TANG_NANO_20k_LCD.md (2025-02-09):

# C64Nano with LCD Output

Video output is adapted for a 5" TFT-LCD module 800x480 Type [SH500Q01Z](https://dl.sipeed.com/Accessories/LCD/500Q01Z-00%20spec.pdf) (Ilitek ILI6122)

Sipeed sells a 5 inch LCD for the Tang Nano 20k. This LCD has a resultion
of 800x480 pixels and attaches directly to the Tang Nano 20k without using the
HDMI connector. This is supported by all cores. The Tang 20k, 60k and 138k Pro additionally comes with a built-in I2S DAC and audio amplifier which comes
in handy in this setup to add sound output.

> [!NOTE]
> TN20k: No Dualshock, no D9 retro Joystick, no external RS232 support

For actual board setup also have a look at the [VIC20][def] pages.

## Adhoc setup of a TN20k, LCD, Speaker and M0S

**Pinmap TN20k Interfaces LCD Output**
M0S Dock, LCD, Speaker

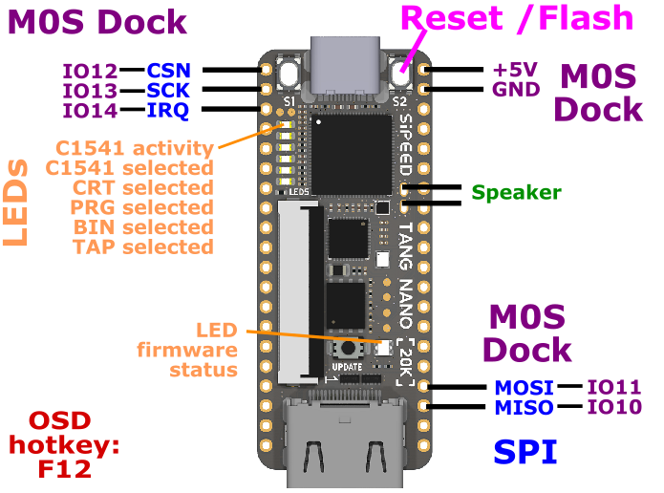
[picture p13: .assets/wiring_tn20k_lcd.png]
wiring


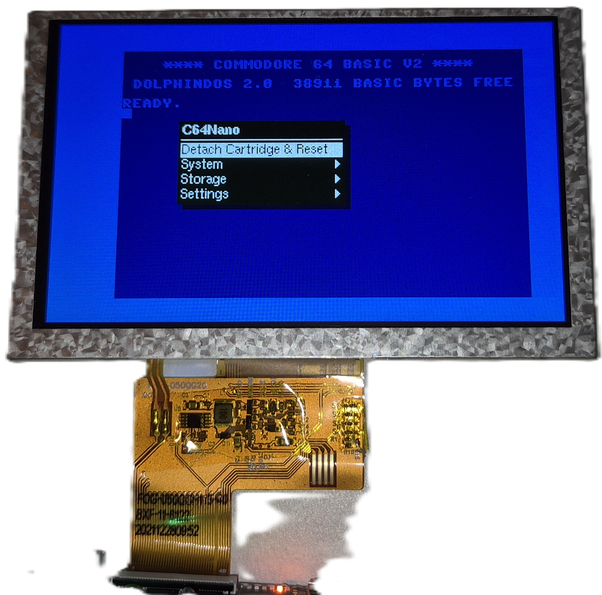
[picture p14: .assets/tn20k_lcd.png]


## Adhoc setup of a TM60k, LCD, Speaker and M0S

> [!IMPORTANT]
> To enable the LCD Interface the tiny jumper J17 (near Button Key1 ) need to be plugged to position 1 + 2.

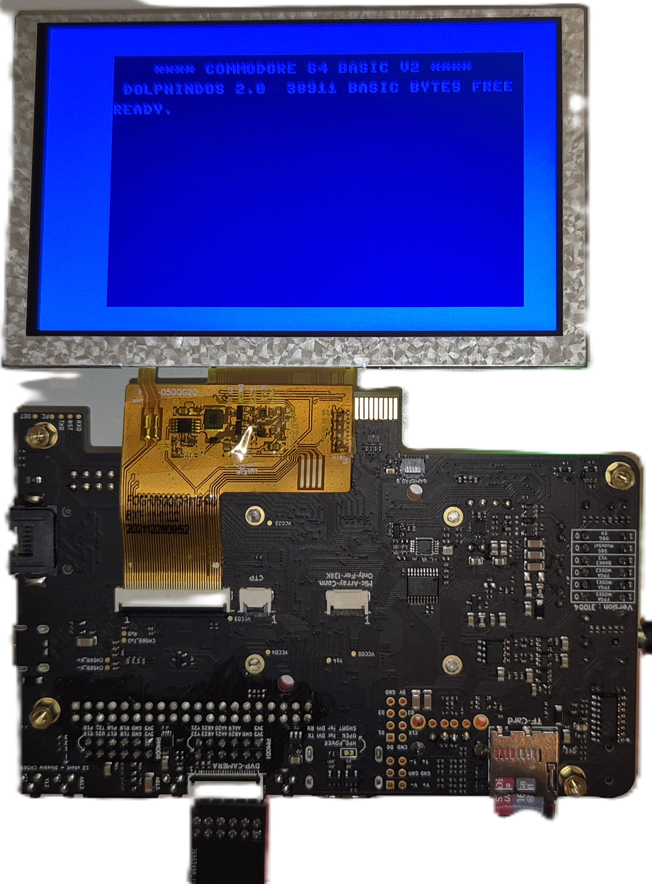
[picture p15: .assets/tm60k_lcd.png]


[def]: https://github.com/vossstef/VIC20Nano/blob/main/TANG_LCD.md

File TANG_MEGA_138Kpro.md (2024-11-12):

# C64 Nano on Tang Mega 138K Pro

C64 Nano can be used in the [Tang Mega 138K Pro](https://wiki.sipeed.com/hardware/en/tang/tang-mega-138k/mega-138k-pro.html).

The Tang Mega 138K Pro is bigger than the other bords supported my
MiSTeryNano. Unlike the Tang Nano 20K which is actually slightly
inferior to the original [MiST](https://github.com/mist-devel/mist-board/wiki), the Tang Mega 138K is even slightly
more powerful than the MiST's successor [MiSTer](https://mister-devel.github.io/MkDocs_MiSTer/). So while the
MiSTeryNano core does run on the Tang Mega 138K it only utilizes its
FPGA to 14%.

Besides the significantly bigger FPGA over the Tang Nano 20K and also
the Tang Primer 25K, the Tang Mega 138K adds several more features of
which some can be used in the area of retro computing as well. 

Although the Tang Mega 138K Pro comes with a significant ammount of
DDR3-SDRAM, it also comes with a slot for the [Tang
SDRAM](https://wiki.sipeed.com/hardware/en/tang/tang-PMOD/FPGA_PMOD.html#TANG_SDRAM). Using this board allows to use the same SDR-SDRAM memory access
methods. DDR3 on the other hand is not supported by regular retro
implementations like the MiSTeryNano.

Plug the optional Dualshock [DS2x2](https://wiki.sipeed.com/hardware/en/tang/tang-PMOD/FPGA_PMOD.html#PMOD_DS2x2) Interface into the **left PMOD** slot.<br>

The M0S required to control the C64 Nano is to be mounted in the
**middle PMOD** with the help of the [M0S PMOD adapter](board/m0s_pmod).

The **right PMOD** slot is allocated for a digital retro Joystick interface.
There is no D9 digital Joystick interface PMOD Adapter known and adhoc wiring needed.
> [!WARNING]
> Joystick interface is 3.3V tolerant and therefore the Joystick 5V supply pin has to be left floating when no level shifters are in use!<br>

|Bus|D9 Signal |D9 pin|PMOD  |FPGA pin |
| - |--- |---| ---- | --- |
| 0 | Button 0 | 6 |  12  | B21 |
| 1 | Down | 2 |  11  | C21 |
| 2 | Up | 1 |  10  | A20 |
| 3 | Right | 4 | 9  | B20 |
| 4 | Left | 3 | 8  | A19 |
| 5 |Button 1 X| 9 | 7  | B19 |
| - |POT Y | 5 | 6  | n.c. |
| - | GND | - | 3  | GND |
| - | +5V |!!! n.c.| | n.c. |

The whole setup will look like this:

MiSTeryNano on TM138K Pro

The firmware for the M0S Dock is the [same version as for the Tang
Nano 20K](firmware/misterynano_fw/).

On the software side the setup is very simuilar to the original Tang Nano 20K based solution. The core needs to be built specifically
for the different FPGA of the Tang Primer using either the [TCL script with the GoWin command line interface](build_tm138kpro.tcl) or the
[project file for the graphical GoWin IDE](tang_mega_138kpro_c64.gprj). The resulting bitstream is flashed to the TM138K as usual.

Since the Tang Mega 138K Pro needs a bigger portion of the available flash
memory space, the DOS ROMs need to be flashed to a different memory location
on the TM.

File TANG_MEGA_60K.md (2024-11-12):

# C64 Nano on Tang Mega 60K NEO

C64 Nano can be used in the [Tang Mega 60K NEO](https://wiki.sipeed.com/hardware/en/tang/tang-mega-60k/mega-60k.html).

Besides the significantly bigger FPGA over the Tang Nano 20K, the Tang Mega 60K adds several more features of
which some can be used in the area of retro computing as well. 

Although the Tang Mega 60K comes with a significant ammount of
DDR3-SDRAM, it also comes with a slot for the [Tang
SDRAM](https://wiki.sipeed.com/hardware/en/tang/tang-PMOD/FPGA_PMOD.html#TANG_SDRAM). Using this board allows to use the same SDR-SDRAM memory access methods.<br> 

The M0S required to control the C64 Nano is to be mounted in the
**right PMOD** close to the HDMI connector with the help of the [M0S PMOD adapter](board/m0s_pmod).

Plug the optional Dualshock [DS2x2](https://wiki.sipeed.com/hardware/en/tang/tang-PMOD/FPGA_PMOD.html#PMOD_DS2x2) Interface into the **edge PMOD** slot.<br>

The **SDRAM 1** slot is allocated for a digital retro Joystick interface.  
A 40 pole 2.54mm pinheader need to be soldered into the Meag 60k NEO.
An 40 pole receptable to be used connecting the 7 signals to the D9 connector.
> [!WARNING]
> Joystick interface is 3.3V tolerant and therefore the Joystick 5V supply pin has to be left floating when no level shifters are in use!<br>

|Bus|Signal | D9 |40-pol| Name |FPGA pin |
| - |--- |---| ---- |---| --- |
| 0 | Button 0 | 6 |  36  |SDRAM1_A10|  U17 |
| 1 | Down | 2 |  35  |SDRAM1_BA1|  U18 |
| 2 | Up | 1 |  10  |SDRAM1_D14|  V17 |
| 3 | Right | 4 | 9  |SDRAM1_D15|  W17 |
| 4 | Left | 3 |  32  |SDRAM1_RAS|  Y18 |
| 5 |Button 1 X| 9 |  31  |SDRAM1_CAS|  Y19 |
| - |POT Y | 5 |  - | |  n.c. |
| - | GND | - |  12  |GND |  GND |
| - | +5V |!!! n.c.|11  | |  n.c. |

The whole setup will look like this:

MiSTeryNano on TM60K NEO

The firmware for the M0S Dock is the [same version as for the Tang
Nano 20K](firmware/misterynano_fw/).

On the software side the setup is very simuilar to the original Tang Nano 20K based solution. The core needs to be built specifically
for the different FPGA of the Tang Primer using either the [TCL script with the GoWin command line interface](build_tm60k.tcl) or the
[project file for the graphical GoWin IDE](tang_mega_60k_c64.gprj). The resulting bitstream is flashed to the TM60K as usual needing latest Gowin Programmer GUI 1.9.10.03 or newer.

**HW modification**  
[Tang SDRAM Module](https://wiki.sipeed.com/hardware/en/tang/tang-PMOD/FPGA_PMOD.html#TANG_SDRAM) V1.2 modification to fit on the TM60k NEO dock.<br>
The capacitors are a bit too lange and touching the 60k FPGA plug-module.  
Use duct tape to cover the capacitors avoiding shortcuts or unsolder three that are blocking.  
There is a also newer Version 1.3 of the TANG_SDRAM available (90° angle) that likely fit. 
parts

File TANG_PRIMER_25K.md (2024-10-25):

# C64 Nano on Tang Primer 25K

C64 Nano can be used in the [Tang Primer 25K](https://wiki.sipeed.com/hardware/en/tang/tang-primer-25k/primer-25k.html).<br> This offers a 10%
bigger FPGA than the [Tang Nano 20K](https://wiki.sipeed.com/hardware/en/tang/tang-nano-20k/nano-20k.html)
the MiSTeryNano was initially developed for.<br> Unlike the TN20K, the
TP25k's FPGA does not come with an internal SDRAM. Nor does the board
come with HDMI or an SD card slot.

Some SDRAM can be added in the form of the [Tang SDRAM](https://wiki.sipeed.com/hardware/en/tang/tang-PMOD/FPGA_PMOD.html#TANG_SDRAM), HDMI can be added via the [PMOD DVI](https://wiki.sipeed.com/hardware/en/tang/tang-PMOD/FPGA_PMOD.html#PMOD_DVI) and the SD card is installed using the [PMOD TF-CARD V2](https://wiki.sipeed.com/hardware/en/tang/tang-PMOD/FPGA_PMOD.html#PMOD_TF-CARD).<br> All three add-ons need to carefully be mounted with the SDRAM's "THIS SIDE FACES OUTWARD" pointing to the boards edge. The HDMI needs to be mounted to the leftmost PMOD slot andf the SD card to the rightmost.

The M0S required to control the MiSTeryNano is to be mounted in the middle PMOD with the help of the [M0S PMOD adapter](https://github.com/harbaum/MiSTeryNano/tree/main/board/m0s_pmod/README.md).

The whole setup will look like this:<br>
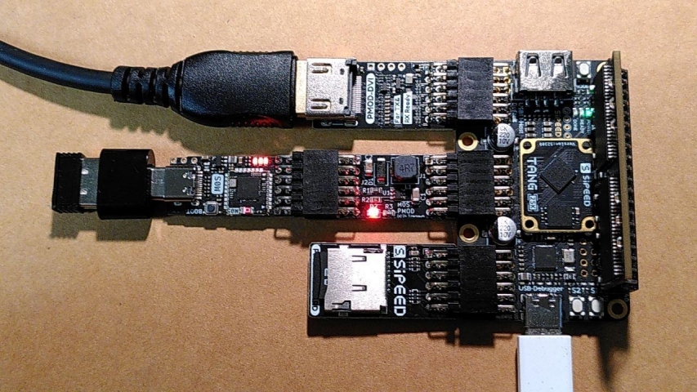
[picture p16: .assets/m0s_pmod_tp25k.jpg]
m0s pmod on TP25K


If you don't have a **M0S PMOD adapter** at hand then adhoc wiring is feasible needing a soldering iron.<br>
The needed +5V for the M0S Dock can be taken from Pin 1 of the USB-A connector by a short soldered wire<br> 8 single pins are needed to plug into the PMOD apart from the cable that comes along with the M0S Dock package.<br>

| | M0S Dock | Primer-25k / PMOD | |
|---|---|---|---|
| GND  | GND | GND -> 3 | GND |
| GND  | GND | GND -> 4 | GND |
| PWR  | +5V | USB-A pin 1 !!! | +5V Supply for M0S |
| - | +3V3 | n.c | don't connect ! |
| CSN  | GPIO12 | E11 -> 9 | SPI select, active low |
| SCK  | GPIO13 | E10 -> 10 | SPI clock, idle low |
| MOSI | GPIO11 | A11 -> 11 | SPI data from MCU to FPGA |
| MISO | GPIO10 | A10 <- 12 | SPI data from FPGA to MCU |
| IRQ  | GPIO14 | L11 <- 8 | Interrupt from FPGA to MCU, active low |

c64 Nano on TP25K

On the software side the setup is very simuilar to the original Tang Nano 20K based solution. The core needs to be built specifically
for the different FPGA of the Tang Primer using either the [TCL script with the GoWin command line interface](build_tp25k.tcl) or the
[project file for the graphical GoWin IDE](tang_primer_25k_c64.gprj). The resulting bitstream is flashed to the TP25K as usual. So are the c1541 DOS ROMs which are flashed exactly like they are on the Tang Nano 20K. And also the firmware for the M0S Dock is the [same version as for
the Tang Nano 20K](https://github.com/harbaum/MiSTeryNano/tree/main/firmware/misterynano_fw/). Latest binary can be found in the [release](https://github.com/harbaum/MiSTeryNano/releases) section.

The resulting setup has no spare connectors and thus no MIDI, DB9 retro joystick port, DualShock, Paddle is available.

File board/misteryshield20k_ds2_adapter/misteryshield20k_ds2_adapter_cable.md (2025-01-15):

# MisteryShield20k DS2 Adapter / Cable

This site shows how to build and connect an Adapter or an Adapter cable to the **Spare Pin Header J8**  
of the [MiSTery Nano Midi Shield by Till Harbaum](https://github.com/harbaum/MiSTeryNano/blob/main/board/misteryshield20k/README.md) to use a Playstation Dualshock 2 (DS2) Controller.

## Building your own Adapter
Use the [Gerber](.assets/mistery_ds2_breakout_gerber.zip) Files from the [KiCad](.assets/mistery_ds2_breakout_kicad.zip) MiSTery Shield DS2 Adapter Project 
and get some PCBs.  
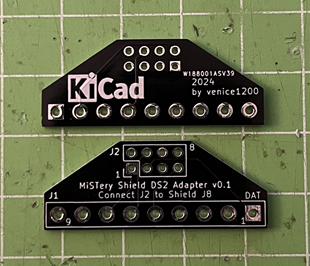
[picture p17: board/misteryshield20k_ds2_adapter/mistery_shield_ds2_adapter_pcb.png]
MiStery Shield DS2 PCB
  

You need a PS2 Connector and a 4x2 Pin Connector for the PCB.  
The final result could end up looking like this:  
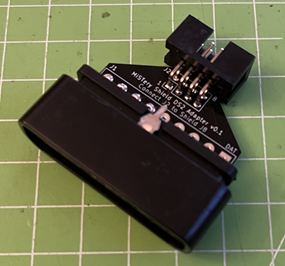
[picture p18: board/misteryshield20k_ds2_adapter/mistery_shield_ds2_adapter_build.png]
MiStery Shield DS2 build
  
  
**OR**
  
Use the **female** end of an DS2 Controller extension cable and cut it 25-30 centimeters behind the connector.  
Remove **carefully** the main isolation and **more carefully** the isolation of the cables.  
Be **very carefully** not to break/cut the thin wires.  

Here https://store.curiousinventor.com/guides/PS2/ you can see a variant of the cable colors from an open DS2 Controller cable.  
**Attention, you colours can be different.** Use a Multimeter for measure or beep the correct wires.  

If you have some spare female DS2 connectors you can solder direcly some small wires to the pins.

Crimp and/or solder some female dupont terminals to the needed wires.  
Use the provided pinouts and the connection table (see below) for correct position of the terminals within the terminal housing.  

See here https://www.instructables.com/Fitting-Dupont-Connectors/  
or here https://www.youtube.com/watch?v=fcP0P6OLJqA for instructions  
how to use Dupont terminals.

Finally double check your Adapter wires to make sure all pins, ***especially the voltage pins***, are at the correct position.

Your adapter could end up looking like this:  
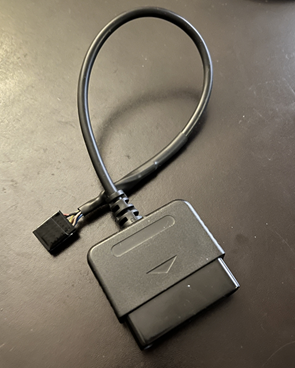
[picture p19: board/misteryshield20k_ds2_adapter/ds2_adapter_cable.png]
ds2_adaptercable


If your Adapter cable is finished, make sure you connect it in the correct orientation.  
See the MiSTery Shield Board Layout (see below) for the correct position of **J8-Pin 1**, which should match **Pin 1** of your cable.  

Activate the DS2 Controller using **DS2 #1 Joy or DS2 #2 Joy** in the Menu and have fun 😃 

## Pinouts and Connection Table
### Pinout of the Playstation Pad Connector
ds2_pinmap
  
### Pinout of the MiSTery Shield Pin Header J8
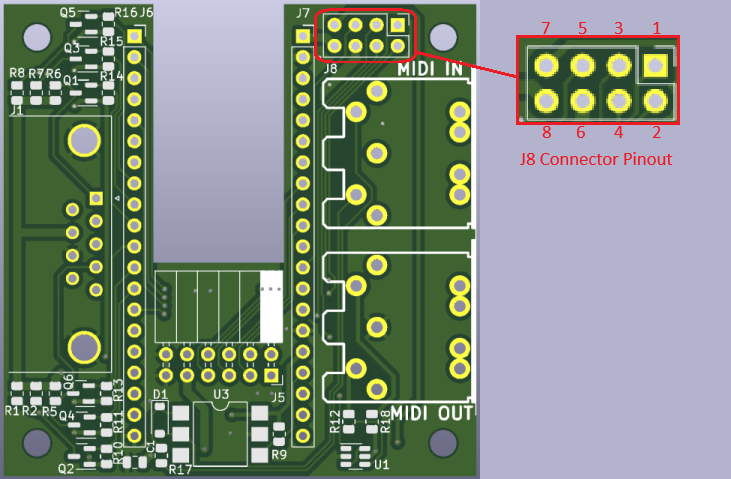
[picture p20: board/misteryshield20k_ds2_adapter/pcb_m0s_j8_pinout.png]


### Connection Table
|DS2 Connector Pin|DS2 Signal Name|DS2 Function|MiSTery Shield J8 Pin|
|:---:|:---:|:---:|:---:|
|1|DAT|Pad Data|3|
|2|CMD|Pad Command|2|
|3|7.6v|Rumble Voltage|nc|
|4|GND|Ground|6|
|5|VCC|3.3v|7|
|6|ATN|Attention|4|
|7|CLK|Clock|1|
|8|IRQ|not in use|nc|
|9|ACK|Acknowledge|nc|

nc = not connected

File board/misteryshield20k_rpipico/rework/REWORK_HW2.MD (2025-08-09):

# Rework Instructions to fix Version 2 boards

Scratch and cut on the PCBs bottom side under **J5**  
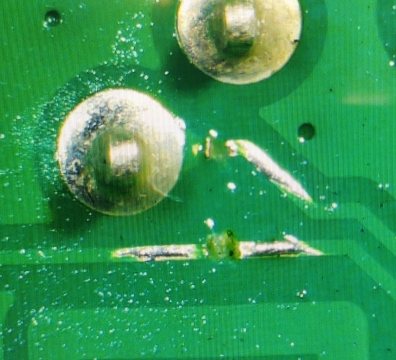
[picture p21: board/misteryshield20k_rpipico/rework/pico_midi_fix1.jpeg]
  

Cross connect using enameled wire  
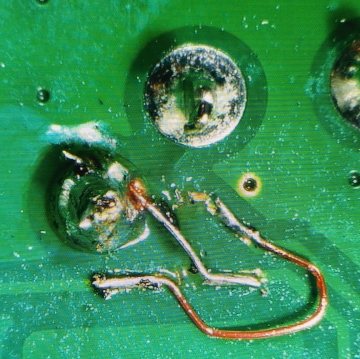
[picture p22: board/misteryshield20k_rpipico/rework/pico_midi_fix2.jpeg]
  

Optional add some protective layer  
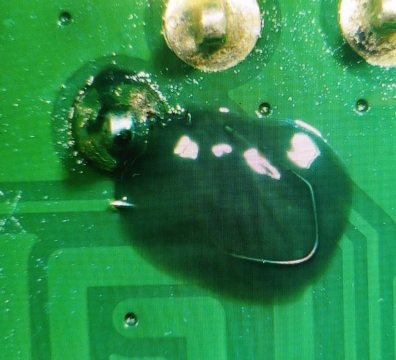
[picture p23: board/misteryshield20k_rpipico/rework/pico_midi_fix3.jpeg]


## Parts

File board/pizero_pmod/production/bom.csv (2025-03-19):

Reference | Value | Comment | LCSC Part # | Qty
C1,C2 | 22uF | 1206 | C12891 | 2
D1 | SS34 | SMA | C8678 | 1
D2 | green | 0805 | C2297 | 1
J1 | PMOD | 2x06, P2.54mm | C60565 | 1
J2,J3 | Conn_01x09_Pin | 1x09, P2.54mm | C2932701 | 2
J4 | Conn_01x03_Pin | 1x03, P2.54mm | C2932698 | 1
L1 | 4.7uH | SMD 6.3x6.3 mm | C142106 | 1
R1 | 220k | 0805 | C17556 | 1
R2 | 30k | 0805 | C17621 | 1
R3 | 1k2 | 0805 | C17379 | 1
U1 | EA2208 | SOT-23-6 | C22462489 | 1

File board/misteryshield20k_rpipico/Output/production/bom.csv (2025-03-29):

Designator | Footprint | Quantity | Value | LCSC Part #
C1, C2, C3, C6 | 0805 | 4 | 100nF | C49678
C4, C7 | 0805 | 2 | 1uF | C28323
C5 | 0805 | 1 | 10uF | C15850
D1 | D_SOD-123 | 1 | 1N4148W | C81598
D2, D3, D4 | 0805 | 3 | green | C2297
J1 | DSUB-9_Male_Horizontal_P2.77x2.84mm_EdgePinOffset7.70mm_Housed_MountingHolesOffset9.12mm | 1 | Joystick | C141880
J10, J3 | PinHeader_2x04_P2.54mm_Vertical | 2 | Conn_02x04_Pin | C7501275
J11, J12 | USB_A_Wuerth_61400826021_Horizontal_Stacked | 2 | USB_A_Stacked | C456021
J4, J7, J8, J9 | PinSocket_1x20_P2.54mm_Vertical | 4 | Conn_01x20_Pin | C18078139
J5 | DIN-5_180degree | 1 | MIDI IN | C2939346
J6 | DIN-5_180degree | 1 | MIDI OUT | C2939346
Q1, Q2, Q3, Q4, Q5, Q6 | SOT-23 | 6 | 2N7002 | C8545
R1, R10, R12, R13, R14, R2, R3, R4, R5, R6, R7, R8, R9 | 0805 | 13 | 10k | C17414
R11, R15 | 0805 | 2 | 220 | C17557
R16, R17 | 0805 | 2 | 47 | C17714
R18, R19, R20 | 0805 | 3 | 560 | C28636
U1 | SMDIP-6_W9.53mm | 1 | H11L1S | C78589
U2 | SOT-23-6 | 1 | 74LVC2G14 | C5375976
U4 | SSOP-28_3.9x9.9mm_P0.635mm | 1 | CH334U | C5187524
Y1 | Crystal_SMD_3225-4Pin_3.2x2.5mm | 1 | Crystal_GND24 | C9002

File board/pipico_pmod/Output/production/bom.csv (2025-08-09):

Designator | Footprint | Quantity | Value | LCSC Part #
C1, C2 | 1206 | 2 | 22uF | C12891
D1, D2, D3, D5 | 0805 | 4 | green | C2297
D4 | D_SMA | 1 | SS34 | C8678
J1 | USB_C_Receptacle_HRO_TYPE-C-31-M-12 | 1 | USB_C_Receptacle_USB2.0 | C165948
J2 | PinHeader_2x06_P2.54mm_Horizontal | 1 | PMOD | C60565
J3, J4 | PinSocket_1x20_P2.54mm_Vertical | 2 | Conn_01x20_Pin | C18078139
L1 | L_6.3x6.3_H3 | 1 | 4.7uH | C142106
R1, R2 | 0402 | 2 | 5k1 | C25905
R3, R4, R7, R8 | 0805 | 4 | 1k2 | C17379
R5 | 0805 | 1 | 220k | C17556
R6 | 0805 | 1 | 30k | C17621
U1 | SOT-23-6 | 1 | USBLC6-2SC6 | C2827654
U2 | SOT-23-6 | 1 | EA2208 | C22462489

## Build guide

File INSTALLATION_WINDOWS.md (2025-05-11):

# Installation using a Windows PC

This document explains how to install all the necessary files on the
Tang Nano 20K and the M0S Dock in order to use it as a C64 Nano
device.

This has been tested on Windows 11. It should work on older versions too.

Software needed:

  - [Gowin V1.9.11.01](https://www.gowinsemi.com/en/support/home/) **to synthesize the core**
  - [Gowin V1.9.11.02](https://www.gowinsemi.com/en/support/home/) **to program the flash of the TANG FPGA**
  - [BouffaloLabDevCube](https://dev.bouffalolab.com/download) **to flash the BL616**
  - [Latest release](https://github.com/vossstef/tang_nano_20k_c64/releases/latest) of C64Nano **FPGA** bitstream
  - [Latest release](http://github.com/harbaum/FPGA-Companion) of FPGA-Companion **BL616 µC firmware** (if not otherwise stated in the release note)
  - [Latest release](https://dl.sipeed.com/shareURL/TANG/Debugger/onboard/BL616) of the TANG onboard µC bl616 programmer firmware

In order to use the SD card for disks:

  - C64 disk images in .D64 or .G64 format
  - Cartridge images in .CRT format
  - BASIC Program files in .PRG format
  - Tape images in .TAP format
  - C64 Kernal files (8K) in .BIN format
  - SID Filter curve in .FLT format

# Flashing the Tang Nano 20k

First download the Gowin IDE. The Education version is sufficient and
won't need a licence.

Install the IDE on your system (follow the installation instructions
from Gowin).  After the Installation you should have it as an shortcut
on your desktop or in your start menu.

 - Press the ```S2``` button on the Tang Nano 20K and keep it pressed
 - Connect the Tang Nano 20k to the USB on your computer. You should hear the connecting sound of Windows.
 - Release the ```S2``` button

> [!CAUTION]
A FLASH programm attempt without keeping the board in reset may lead to corruption of the C1541 DOS images stored in FLASH requiring re-programming.

 - Start Gowin. **You should see the following screen**

Explanation: The C64Nano core makes use of the flash memory of the
Tang Nano 20k to store c1541 DOS ROMs. This may interfere with the FPGA
flash process. Pressing the ```S2``` during power up will prevent the
Tang Nano 20k from booting into the C64Nano core and will make sure
the flash ROM can be updated.

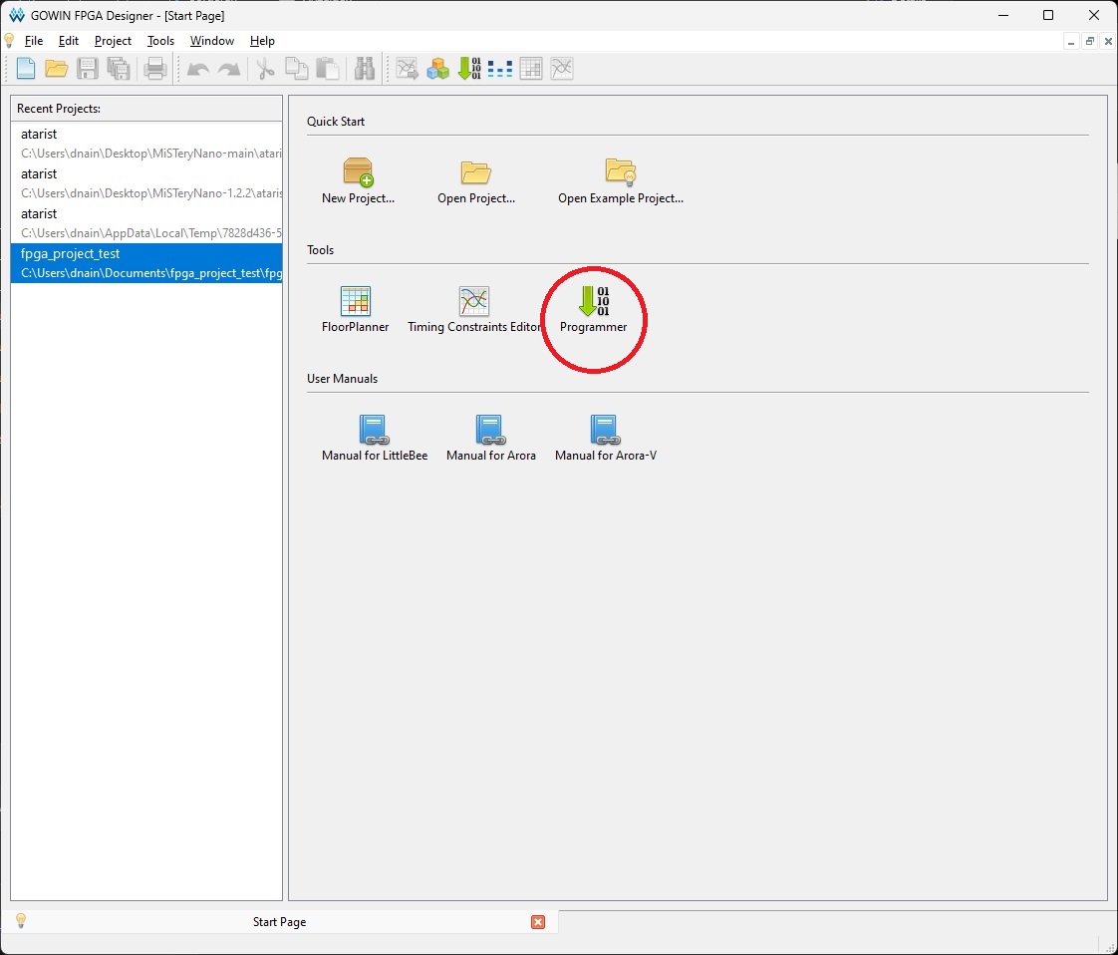
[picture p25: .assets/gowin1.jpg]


Now press on the “programmer” marked red on the picture above. **You
should see following screen:**



-   Press save on the dialog
-   From there you can add a device for programming by pressing on the little
    icon with the green plus
-   At least three files have to be flashed:
    - The core itself: ```tang_nano_20k_c64.fs```
    - Two c1541 DOS ROMs
-   Than you can choose from the drop downs the parameter you see on the
    pictures.

**Important**:

  - ```tang_nano_20k_c64.fs``` is written to address 0x000000
  - ```reserved for Atari ST ROM``` address 0x100000
  - ```c1541 DOS Dolphin 2``` is written to address 0x200000
  - ```c1541 DOS CBM``` is written to address 0x20C000

Optionally two additional DOS ROMs may be flashed to the alternate
addresses:

  - ```c1541 DOS Speeddos Plus``` is written to address 0x214000
  - ```c1541 DOS Jiffy``` is written to address 0x21C000

These DOS for the c1541 emulation can later be selected from the on-screen-display (OSD).
  - For the FS file please choose the ```tang_nano_20k_c64.fs``` you just downloaded
  - User Code and IDCODE can be ignored
  - Mark each of your configs and press the little icon with the green play
    button. You should see a progress bar and then:

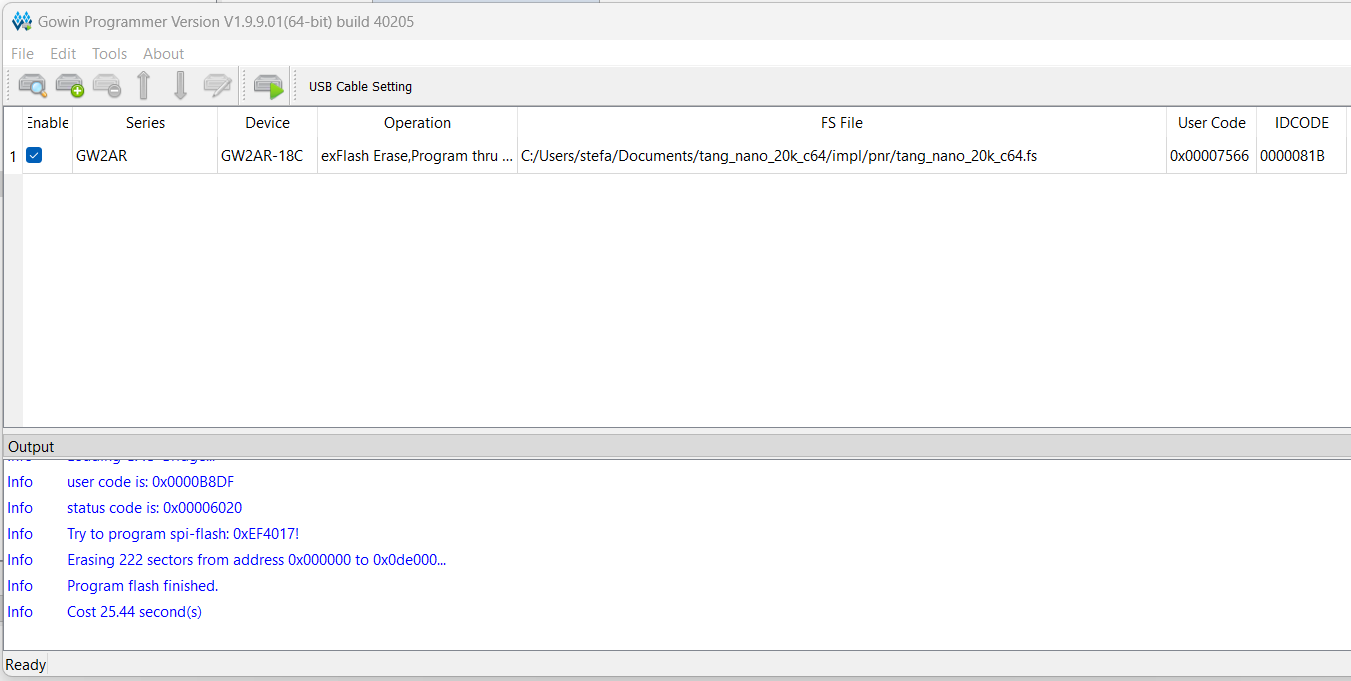
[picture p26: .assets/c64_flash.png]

**At a glance the memory layout of the SPI Flash:**

| | | | | | | |
| -| -| -| -| -| -|-|
| Type | TN20k | TP25k | TM60k |TM138k |Console60k| |
| FPGA bitstream | 0x000000 | 0x000000 | 0x000000 | 0x000000 |0x000000 |ROM size|
| reserved for Atari ST ROM | 0x100000 | 0x100000 | 0x500000 | 0x900000 |0x500000 | - |
| c1541 Dolphin DOS 2 | 0x200000 | 0x200000 | 0x700000 | 0xA00000 |0x700000 |32k|
| c1541 CBM DOS 2.6 | 0x20C000 | 0x20C000 | 0x70C000 | 0xA0C000 |0x70C000 |16k|
| c1541 Speed DOS Plus | 0x214000 | 0x214000 | 0x714000 | 0xA14000 |0x714000 |16k|
| c1541 Jiffy DOS | 0x21C000 | 0x21C000 | 0x71C000 | 0xA1C000 |0x71C000 |16k|

**shell / command line Programming alternative**

Windows shell and Gowin Programmer<br>
```programmer_cli  -r 36 --fsFile tang_nano_20k_c64.fs --spiaddr 0x000000 --cable-index 1 --d GW2AR-18C```<br>
```programmer_cli  -r 36 --fsFile tang_nano_20k_c64_25k.fs --spiaddr 0x000000 --cable-index 1 --d GW5A-25A```<br>
```programmer_cli  -r 36 --fsFile tang_nano_20k_c64_60k.fs --spiaddr 0x000000 --cable-index 1 --d GW5AT-60B```<br>
```programmer_cli  -r 36 --fsFile tang_nano_20k_c64_138k.fs --spiaddr 0x000000 --cable-index 1 --d GW5AST-138B```<br>

```programmer_cli -r 38 --mcuFile 2dosa_c.bin --spiaddr 0x200000 --cable-index 1 --d GW2AR-18C```<br>
```programmer_cli -r 38 --mcuFile 2dosa_c.bin --spiaddr 0x200000 --cable-index 1 --d GW5A-25A```<br>
```programmer_cli -r 38 --mcuFile 2dosa_c.bin --spiaddr 0x700000 --cable-index 1 --d GW5AT-60B```<br>
```programmer_cli -r 38 --mcuFile 2dosa_c.bin --spiaddr 0xA00000 --cable-index 1 --d GW5AST-138B```<br><br>
Linux shell and [openFPGAloader](https://github.com/trabucayre/openFPGALoader).<br>
[Please read here if you run into trouble when using openFPGAloader under Linux](https://wiki.sipeed.com/hardware/en/tang/Tang-Nano-Doc/flash-in-linux.html).<br>
```openFPGALoader -b tangnano20k --external-flash -o 0x200000  2dosa_c.bin```<br>
```openFPGALoader -b tangnano20k -f tang_nano_20k_c64.fs```<br>
<br>
```openFPGALoader -b tangprimer25k --external-flash -o 0x200000  2dosa_c.bin```<br>
```openFPGALoader -b tangmega138k --external-flash -o 0xA00000  2dosa_c.bin```<br>

**c1541 DOS ROM binaries** <br>
The needed DOS files you will find on the Internet.<br>
```Dolphin DOS 2```<br>
You will [find](https://e4aws.silverdr.com/projects/dolphindos2/) 2dosa_c.bin<br>
Program at offset 0x200000<br>
![](https://github.com/vossstef/tang_nano_20k_c64/blob/main/.assets/dolphin.png)

```CBM DOS```<br>
You will [find](https://sourceforge.net/p/vice-emu/code/HEAD/tree/trunk/vice/data/DRIVES/dos1541-325302-01%2B901229-05.bin) dos1541-325302-01+901229-05.bin<br>
Program at offset 0x20C000<br>

```Speed DOS Plus```<br>
You will [find](https://rr.pokefinder.org/wiki/Speed_DOS#Binaries) or [here](https://csdb.dk/release/?id=21767&show=summary) C1541.ROM<br>
Program at offset 0x214000<br>

```Jiffy DOS```<br>
You will get a 16k [JiffyDos](https://www.go4retro.com/products/jiffydos/) JiffyDOS_C1541.bin file.<br>
Program at offset 0x21C000<br>

**That´s it for the Tang Nano 20k**

## Flashing the BL616 µC

For the BL616 you have to extract and start the BuffaloLabDevCube. 

**If you use the internal BL616 present on the Tang Nano 20K you loose
your possibility to flash the Tang over the USB connection.** It is thus
strongly recommended to use an external BL616 (e.g. a M0S Dock).

However, when using the internal BL616 you will be able to flash the
[original firmware](https://github.com/harbaum/MiSTeryNano/blob/main/bl616/friend_20k)
to the internal BL616 again to restore the flasher functionality of
the Tang Nano 20K. Using an external M0S is nevertheless recommended.

-   Press the ```BOOT``` button on your M0S Dock before you plug the USB connection
    on your PC. You should hear the hardware detecting sound.
-   Start the BuffaloLabDevCube from the directory where you decompressed it it
    ask you what chip should be used. Select BL616/BL618 and press “finish”

![](https://github.com/vossstef/tang_nano_20k_c64/blob/main/.assets/buffstart.png)

- You'll now see the program screen. On the right it should auto detect your
  device with a COM port. If not take a look in the device manager to check for
  the correct device detection.
- On the top click on MCU and browse to the firmware image file named
  ```misterynano_fw_bl616.bin``` (contains a unified firmware both for all cores)
- Choose “Open Uart” and than press “Create & Download”. The firmware should now be
  flashed

![](https://github.com/vossstef/tang_nano_20k_c64/blob/main/.assets/bufffinish.png)

## Prepare the SD card

Format the SD card in FAT32. Copy your D64 / G64 / CRT / PRG / BIN / FLT files files on
it. You can organize your files in subdirectories. These files can later
be selected using the on-screen-display (OSD).
Default Mountpoints:  
Copy a *.D64 Disk image to your sdcard and rename it to disk8.d64 as default c1541 boot image.  
Copy a *.CRT ROM image to your sdcard and rename it to c64crt.crt as default Cartridge boot image.  
Copy a *.PRG BASIC file to your sdcard and rename it to c64prg.prg as default Program boot image.  
Copy a *.TAP Type image to your sdcard and rename it to c64tap.tap as default tape boot image. 
Copy a 8k Byte C64 Kernal ROM file *.BIN to your sdcard and rename it to c64kernal.bin as default Kernal boot image.<br>
Copy a *.FLT sid filter curve to your sdcard and rename it to c64flt.flt as default filter boot image.<br>

That´s it for now. Have fun using the C64Nano

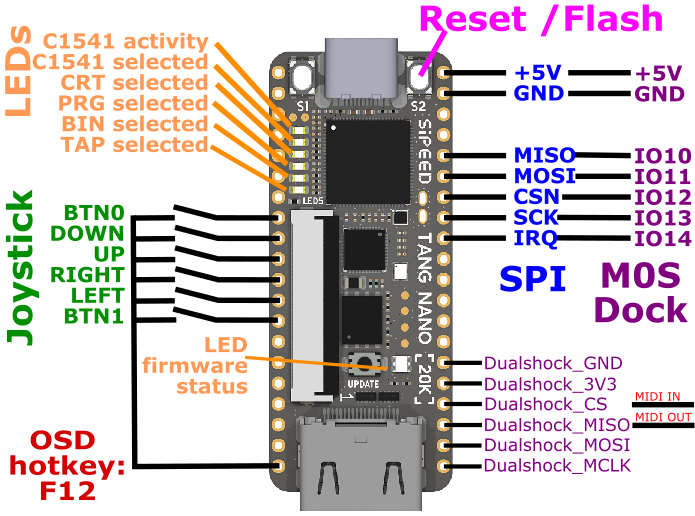
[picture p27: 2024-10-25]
.assets/wiring_spi_irq.png

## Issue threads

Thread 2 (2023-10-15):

GPIO normalization

misterjbam, 2023-10-15:
Good morning

Would it be possible to standardize the GPIO port?
For the joystick port of this core, is it possible to replace it to use the same location and controller as the NESTANG, PACMAN, GALAGA, ... cores?
And for the keyboard, would it be possible to standardize it with the core developer Atari ST?
If all cores are standardized at the GPIO level, it will be simpler for users.

Thanks to all the developers

misterjbam, 2023-10-15:
the developer of the core atai ST wants to do without GPIO and run everything via USB (keyboard, mouse, controller)
Do you think it would be possible to implement on the C64 core?

vossstef, 2023-10-15:
Hi, if i am not totally mistaken there are already serveral projects that are using FPGA IO pins with low speed USB 1.1 devices (keyboard, mouse, joystick) even without the dedicated USB tranceivers like USB3317 or MAX3421E. Interfacing needs would collapse just into USB connector, resistors and maybe fpga input protection. See e.g. github.com/nand2mario/usb_hid_host/tree/main
At the moment i am concentrating more on burning tasks like proper HDMI output and porting memory from bram to dram rather thoughts of moving away from good old PS2 KB and beloved legendary competition pro digital joystick... but time will come also for that. However if such GPIO 'normalization' would become available would be of course interested to utilize it.

vossstef, 2023-10-18:
> As an intermediate step I am currently programming a M0S Dock (also made by Sipeed) to act as a USB/PS2 bridge to give the MiSTeryNano access to a USB keyboard and a USB mouse. The same solution should work for your C64 core as well.
>
> In the long term I am planning to do this with the BL616 already present on the Tang Nano 20k.

I see and thanks for notification.
Guess we would we need something like a 4 port USB2.0 hub to connect keyboard, mouse and two gamepads or alternately  two joysticks isn't it ? Looks to me like excellent scalable and flexible soluation rather than growing amount of diff pair needs per HMI input device at FPGA.

harbaum, 2023-10-19:
These mini USB hubs fit nicely: https://a.aliexpress.com/_EIidgjH

Also my primary interest for this are small cheap wireless keyboard and touchpad combos to give the Atari ST a keyboard and a mouse. These integrate both devices and thus only one small USB dongle is needed. Together with the necessary USB-C/USB-A adapter this is still very small.

harbaum, 2023-11-08:
Did you try one of those 5 inch 800*480 LCDs they sell for the TN20k? These cope nicely with 50hz and 31.5kHz signals and can e.g. display all the Atari ST video modes.

I am sure they'd work with your core as well. But as the lcd uses many of the IOs only few are left for peripherals and allowing for at least spi or PS2 together with the lcd would probably require yet another relocation of pins.

Btw: these devices: https://www.notjust4nerds.de/Riitek-Rii-i8-Mini-DE-Funk-USB-Dongle-Tastatur-QWERTZ-Maus-Kombo-beleuchtet-kabellos

work nicely with the Tang Nano. They work as mouse and keyboard and I consider mapping those top left buttons to joystick.

vossstef, 2023-11-09:
I did make use of the Sipeed SH500Q01Z LCD-TFT with CoG TCON Ilitek ILI6122  https://api.dl.sipeed.com/shareURL/Accessories/LCD in the VC20 project https://github.com/vossstef/tang_nano_9k_vic20_lcd  and it is working rather fine.  Just a bit scared to break the flexfoil when plugging and unplugg it from TN too often.  This Sipeed LCD does not have any touch sensor. TN20k seem to be rather limited in available IO when it comes to parallel LCD (or old VGA) interfacing. Maybe the Tang Primer 20k + full blown Dock would be a better choice as far more IO's available.

Closed 2023-11-04.

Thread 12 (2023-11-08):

Use flash ROM for ROM and cartridges

harbaum, 2023-11-08:
The Tang Nano 20k comes with a 64MBit/8Mbytes SPI flash. The first 700+ kBytes are used to store the FPGA bitstream. But the remaining 7MB are unused and can be accessed by the FPGA at runtime.

This can either be used directly and with DSPI mode at 100MHz a random read speed of <250ns can be achieved. This should be sufficient for the C64. Especially multiple ROM carts could be stored there. The flash may also be used to initialize some of the SDRAM at startup such that the SDRAM can also be used to store Rom data but with a shorter access time.

vossstef, 2023-11-08:
thanks for the very good idea and will remember when i managed a bigger refactoring to be more compatible to Mister and the more urgent missing OSD function.

harbaum, 2023-11-11:
The MISTer osd is somewhat outdated. I am currently implementing a slightly more modern osd for misterynano. Perhaps you'd like to cooperate ....

harbaum, 2023-11-11:
First tests with the new OSD:

https://m.youtube.com/shorts/zsHYcolqtpc

Next will be the floppy disk image selector for that. The idea is that the BL616 deals with the SD cards file system and let's you select a disk image file. And whenever the core wants to read a sector from floppy then the BL616 translates the original sector address into a sector address within the SD cards own file system. So the FPGA would still read sectors from the floppy disk image by itself, but the sector numbers would be translated by the BL616 which has plenty of ram and plenty of CPU power to deal with the SD cards file system.

vossstef, 2023-11-20:
> The MISTer osd is somewhat outdated. I am currently implementing a slightly more modern osd for misterynano. Perhaps you'd like to cooperate ...
>
> Is there a way to send a PM through GitHub?

github PM had been some while ago removed. I send today a PM.

Closed 2024-02-12.

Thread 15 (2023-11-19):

Cooperation on retro core infrastructure

harbaum, 2023-11-19:
I'd like to suggest that we cooperate a little bit on the infrastructure side. With infrastructure, I relate to everything but the (retro) core itself. IMHO a unified nice framework using the hardware present on the Tang Nano 20k to provide various generic services to the core would be nice.

My suggestion would be to add common services like USB mouse, keyboard, the various joystick interfaces, HDMI, the SDRAM, the flash ROM etc etc and to make sure that the next core developer can also simply re-use these. Somewhat like the MiST and MiSTer frameworks do, but for now more Tang Nano specific.

The difference to MiSTer is, that there is not full Linux in the background and the difference to the MiST is that the MCU on the TN20k is way more powerful. The minor differences are that the e.g. the SD card is connected to the FPGA and not to the MCU which makes interaction between SD card, MCU and core a little different.

rog77, 2023-11-19:
@nand2mario has done good work with the TN20k, and also seems to.have contacts with sipeed - if the three of you had a unified project, sipeed it a lot more likely to release the firmware for modification, or maybe even offer and updated version by default if it didn't interfere with ordinary operations.

zf3, 2023-11-19:
It would be great to collaborate. I haven’t actually asked sipeed about their stance on sharing the firmware. They do have an open source firmware for their bl702-based debugger dongle.

nand2mario, 2023-11-20:
Sounds good. One thing is they mentioned they plan to add the ability to switch among multiple .fs images to the firmware, stored in the flash of BL616. That may be useful to core developers. Presumably they should be open to concrete proposals on how things should work technically.

nand2mario, 2023-11-20:
Also I'm wondering if usb_hid_host would be useful to this project.

https://github.com/nand2mario/usb_hid_host

vossstef, 2023-11-20:
sorry didn't found time yet to reply yet to Till's original note. I think indeed a very good idea to define a Tang specific infrastructure with OSD and the usual needed stuff as outlined above what all teh different cores need.

harbaum, 2023-11-20:
The usb_hid_host is really cool and makes much sense if one needs a simple USB HID interface. IMHO it comes with a few disadvantages like the fact that it uses up FPGA resources while the same functionality can be had in the BL616 bascially for free (at least with respect to FPGA resources). But having it as some kind of option selectable by a core developer sure makes sense.

With the MiSteryNano/Atari ST core I am pretty close to the capabilities of the FPGA and it's currently over 90% used. At the same time there's still stuff i'd like to add (harddisk support, MIDI support and if possible a 16MHz 68000 with caches for Mega-STE compatibility). So I'd like to keep the FPGA side as simple as possible and move as much of the infrastructure into the BL616 MCU as possible. Also one day someone will hopefully port the Amiga/Minimig core which will likely also be a very tight fit especially if AGA support is included.

On the other hand the BL616 side isn't very convenient to develop for. The bouffalo SDK still has a bunch of quirks, especially in the USB part and the initial reaction to some of my bug reports bascally was "we don't support open source projects and we don't support sipeed boards". But this seem to have gotten a little better lately.

I wonder how they want to allow the BL616 to choose between different cores. Is there a way to tell the FPGA from which part of the SPI flash to load its bitstream? Or where do they want the different cores to be stored?

I will document what I've done with the BL616 so far. I am basically re-doing many of the things I did for the MiST over ten years ago. But as the BL616 is way faster and has more ram and flash, things can be implemented significantly neater.

vossstef, 2023-11-20:
I full agree with Till.
Recentry tried and old OSD with ZCPU and figured out that FPGA entirely filled up as i plugged it it and found out 'no way'... As anyway µC there it should be somhow used to allow many more retro core types. I am only worried that there is presently no way back due to lack of sipeed original µC firmware. The Litex project makes use (for to me unknown reasons) of the extra onboard PLL via special UART (SPI) configuration mode and by replacing with own firmware this feature would be gone...

harbaum, 2023-11-20:
I hope the firmware availability issue will be resolved. And for now it's more convenient to work with the external BL616/M0S Dock, anyway.

I am not sure it's possible to switch between USB host and USB target in the same firmware on the fly. So it may not be possible to directly integrate both firmware types. A simple solution would be to poll the "UPDATE" button in a custom firmware and once its pressed, the BL616 resets itself and goes into the FPGA download mode.

This would mean that both firmware's are compiled into one binary and some magic marker early in the boot stage determines whether the uploader code is run or whether the retro firmware code is being run. But I have not managed to leave any message over a device reset. It seems the bootloader e.g. erases all memory. Maybe there's some hw register which can be used to leave a message that'll survive reset.

It would be cool if it was possible to detect whether the board is powered from USB as that means it's plugged into a PC and thus is supposed to run the uploader firmware. But IMHO that's not possible with the hardware as it is.

Actually, I don't understand the purpose of the seperate PLL at all. At least while it's controlled by the BL616 it doesn't allow the FPGA core to trigger any PLL configuration by itself.

harbaum, 2023-11-20:
I just moved a very rudimentary SD card/FAT/disk image handling out of the core into the MCU which caused FPGA utilization to drop from >90% to 78%. And this was just very basic stuff. Now in the MCU I have full FAT/exFAT sd card handling with long filenames, subdirectory support and various other goodies.

This is the same with USB. You can do simple things like single HID targets inside the FPGA. But doing this in the MCU will save FPGA space and will give you more features. E.g. USB joysticks typically need a hid descriptor parser, otherwise only very few joysticks will work properly. This cannot be done inside the FPGA.

rog77, 2023-11-20:
> I have full FAT/exFAT sd card handling with long filenames, subdirectory support and various other goodies.
>
> This is the same with USB.

Is there any way to present a USB storage device to the FPGA, say, as an spi device with the MCU selecting a particular partition via OSD menu, or presenting a subdirectory as a partition to the emulated device? As you say, bitstreams could be on USB storage, but so could ROMs/disk images/user files.

harbaum, 2023-11-21:
> Is there any way to present a USB storage device to the FPGA
Sure. That way files stored on USB media could be used by the core just like it currently does with the SD card. Since the USB is available to the MCU without the help of the FPGA it could even reconfigure the FPGAs from a bitstream stored in USB media.

harbaum, 2023-11-21:
See a little documentation on how I currently use the SPI connection between MCU and FPGA: https://github.com/harbaum/MiSTeryNano/blob/main/bl616/misterynano_fw/SPI.md

Some of this currently still is very Atari ST specific. E.g. key events are sent as Atari ST key matrix positions. But this can be extended to support PS2 codes again or even C64 key positions removing and key code translation from the core.

vossstef, 2023-11-21:
thx ! Need  still some time to integrate as ongoing refactoring...

rog77, 2023-11-21:
> > Is there any way to present a USB storage device to the FPGA
>
> Sure. That way files stored on USB media could be used by the core just like it currently does with the SD card. Since the USB is available to the MCU without the help of the FPGA it could even reconfigure the FPGAs from a bitstream stored in USB media.

Interesting read, thanks. I like how you have the different keymap idea covered too.

The thought occurs that if one is likely to have a second BL616 connected to the board anyway, couldn't this act as a USB device, such that a computer connected to it could access files whilst an emulated core is running? I lthink this might be more useful for cases where the core is used to produce something and the user doesn't want to physical usb/sd to access created files.

On the other hand, I wonder how many write cycles the bl616 flash is good for in practice, as nand2mario says there is space for bitstreams on there (and rememberinghow you said the ram is too small to hold them), and presumably they could be copied from SD card without needing extra hardware?

vossstef, 2023-12-31:
> Let me have a chat with sipeed and find out if they are open to either share the firmware binary, or as discussed here provide a mechanism for loading custom binary after MCU boot.

any news  ?

harbaum, 2023-12-31:
They sort of agreed that I release the flasher part as a binary-only library. I have prepared for this, but this is not finished yet as other parts are more interesting to implement ...

Closed 2024-01-02.

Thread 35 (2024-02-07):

Feature request: Datel MIDI cart

harbaum, 2024-02-07:
I have a carrier board for the Tang Nano with MIDI IN and OUT. Unfortunately this collides with the Dual shock connector of the C64 core.

I still would like to see an option to use the MIDI ports in the C64 core. This has been done for the MiST C64 core as it seems:

https://github.com/mist-devel/c64/issues/1

The use case? I think it would be quite funny to couple two Tang Nano via MIDI, run Atari ST + Cubase on one of them and C64 + Cynthcart on the other one. The C64 with it's SID would then be used by the Atari ST as a MIDI synthesizer.

Admittedly a rather odd setup and probably not the most common use case ... but nevertheless tempting ...

I might give that a try myself. But maybe you actually derive your code from the MiST core.

vossstef, 2024-02-08:
will add the already existing MIDI function so no issue.
Need to fix someother topics first.

harbaum, 2024-02-08:
No need to hurry ... This is really just for a little personal entertainment ...

Thanks!

vossstef, 2024-02-09:
I added midi to following branch:
https://github.com/vossstef/tang_nano_20k_c64/tree/c1541dos_2_flash

Can't test as i don't have the interface pcba and knowledge of Synthesizer's.
Be able to play a Korg M1 would be nice but reality...

The design still has a weird behavior in locking the video signals that i have to fix

vossstef, 2024-02-12:
released

Closed 2024-02-12.

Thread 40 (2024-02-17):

Black screen - no blue prompt and no loading

camplusplus, 2024-02-17:
I flashed it with Linux and Windows afterwards but no blue commodore prompt displays on boot as in your screenshots.

Also cannot load any disk image.

Only f12 menu works.

Tried [v0.1.7](https://github.com/vossstef/tang_nano_20k_c64/releases/tag/v0.1.7) and [v0.1.6](https://github.com/vossstef/tang_nano_20k_c64/releases/tag/v0.1.6)

vossstef, 2024-02-17:
The fpga design can only live together with a M0 Dock with programmed misterynano firmware for the bl616 µC.
To me it looks that the design is kept in reset by missing bl616 response on SPI interface.
The large multi color LED on the TN need to be illuminated in green.
In addition need one of the other LEDs need to be illuminated in red indicating that the m0S dock detected.
pls. checking wiring and correctly programmed µC fw.
0.1.7 requires the fw that i adhoc compiled and attached in the release package.

camplusplus, 2024-02-17:
Large multi color LED on the TN is Green
One smaller led is amber on TN.

3 red are on M0S dock.
I will check connection but keyboard works

camplusplus, 2024-02-17:
On boot i have next leds counting from 0 from usb:

0: quickly flashes
3: solid light M0S Dock detect

camplusplus, 2024-02-17:
I will try with older pairs of firmware

camplusplus, 2024-02-17:
Also same luck with v0.1.5
I flashed both M0S and TN with files from release.

Menu works fine, file browser working but black screen.

harbaum, 2024-02-17:
Did you start with a fresh SD card? Not that you have some old saved settings on card which prevent the C64 from booting.

camplusplus, 2024-02-17:
Button mechanically works also tried with fresh SD card Formatted in fat16.

I'm suspecting IRQ fin form M0S

camplusplus, 2024-02-17:
Formatted SD card to FAT16

Reset button mechanically clicks.

IRQ pin is 3.24 V

camplusplus, 2024-02-17:
Same issue with Mistery Tang, which was working before.
I'm trying to erase flash completely

harbaum, 2024-02-17:
MiSTeryNano would even boot without any M0S connected and no SD card inserted at all.

But you need a TOS ROM in flash. Otherwise it won't boot.

If it worked before and now doesn't I'd check if the reset button is working even if it clicks. There's not much more that may prevent both cores from booting while e.g. the menu works.

camplusplus, 2024-02-17:
I added TOS-es for MiSTeryNano.
Reset button working in MiSTeryNano.

Same situation in MiSTeryNano: Menu working but black screen.

harbaum, 2024-02-17:
How do you know that reset is working if you don't see anything?

camplusplus, 2024-02-17:
Monitor reconnects

harbaum, 2024-02-17:
What vertical frequency does your monitor report in MiSTeryNano? If it's 50Hz then the machine actually executed some part of the TOS operating system.

camplusplus, 2024-02-17:
it's was 50Hz

harbaum, 2024-02-17:
I am running out of ideas. My current guess would be that the embedded SDRAM of the FPGA has failed ...

camplusplus, 2024-02-17:
I would say also that I have defective board

Closed 2024-02-17.

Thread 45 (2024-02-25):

Primer 25k SDcard write core stall

vossstef, 2024-02-25:
hw control signal for sdcard might be missing

harbaum, 2024-02-26:
Write protect on a micro SD card? How does that work?

vossstef, 2024-02-26:
sorry my mistake. Just observed that core stalls when i press "save configuration".
Just figured out that a .ini had been written.
Need to debug further

vossstef, 2024-02-26:
no bug.

Closed 2024-02-26.

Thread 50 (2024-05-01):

improvements crt prg bin loader

vossstef, 2024-05-01:
further improve:
stability of crt, prg and bin loader
stability of sequenced autoload after power-up

Closed 2024-05-03.

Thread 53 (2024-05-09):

Trying to flash BL616 on Linux

vanfanel, 2024-05-09:
Hi,

I have started to try this C64 on my tang nano 20k + dock, which has M0S Dock onboard:

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

I have no problem with flashing the core with this command:
openFPGALoader -f tang_nano_20k_c64.fs
It boots!

However, I am missing many options on the OSD, like CRT loading etc.

Looking at the documentation here:  https://github.com/vossstef/tang_nano_20k_c64/blob/main/INSTALLATION_WINDOWS.md
I can see the BL616 on the M0S Dock has to be updated too.
For that, you point to a program called BuffaloLabDevCube which seems to be Windows software. I don't have a Windows machine, and will never use that OS.
Is there a way to do that on GNU/Linux?

Thanks!

harbaum, 2024-05-09:
https://github.com/harbaum/MiSTeryNano/blob/main/INSTALLATION_LINUX.md

But as I said in the other thread: Please ask the vendor of your board for help first. He has initially flashed it and he knows how to update it. He's making the money and he's the one to get you started and tell you how to use the board. We have never seen nor used your board.

vanfanel, 2024-05-09:
> https://github.com/harbaum/MiSTeryNano/blob/main/INSTALLATION_LINUX.md
>
> But as I said in the other thread: Please ask the vendor of your board for help first. He has initially flashed it and he knows how to update it. He's making the money and he's the one to get you started and tell you how to use the board. We have never seen nor used your board.

That's what I needed. Thanks, Till. Sorry to bother you.

vossstef, 2024-05-09:
Be aware that at this moment in time C64 and VIC20 core enhanced BL616 firmware has be loaded including many new CBM core features like the lately added loaders. I think that the latest FW i complied and added under releases will support all three cores.

harbaum, 2024-05-09:
Indeed. Everything will hopefully get a little more stable over the time. But currently there may be versions that may not support all cores fully at the same time.

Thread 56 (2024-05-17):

Video and audio problems

vanfanel, 2024-05-17:
Hi @vossstef!

I could finally test the latest core version on the Tang Nano 20k after flashing the BL616 with the latest firmware, I'm having A LOT of fun with it!

However, I've noticed some video & audio problems:

-If `Settings->Screen` is set to `Wide`, there is no HDMI audio. `Wide` is needed for correct aspect ratio on modern 16:9 monitors.

-If `Settings->Screen` is set to `Wide`, screen is not centered: it's displaced towards the left side of the screen.

-SID audio doesn't match the real C64 or the MiSTer core.
For example, try Tim Follin's Ghouls'N Ghosts tittle screen music: in both 6581 and 8580 modes, with or without DIGIFIX, it doesn't sound correct (it sounds correct on the MiSTer core).
This is how it sounds on real hardware and on the C64 MiSTer core:  https://www.youtube.com/watch?v=wz36JWHTk-A
Note this music is perhaps the definitive C64 audio test: only the C64 MiSTer core and real C64 passes this hard test :)
Are filters supposed to be implemented? Maybe it's simply filters being missing at this point?

vossstef, 2024-05-17:
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

Hi,
so far i didn't focus too mich on 16:9 but will have over time a Look at it.
Concerning the Mister SID i hat a lot of Compiler  Problems and therefore picked the Mega65 SID variant. Didn't know those mentioned game as reference but checked some rather New Demos that sounded about correct to my ears. Also the dual sid in Primer25k looked to me correct. Good news is that i found a lot of linting errors in the Mister sid and got it fixed and running with the Gowin IDE. Will check with that your game for Sound  differences and maybe swap.

vanfanel, 2024-05-17:
@vossstef The fact that you got the MiSTer SID working on the Gowin IDE is fantastic!

If you test Ghouls'n Ghosts, please use original 6581 SID, since the game was designed with that SID variant in mind (all Tim Follin soundtracks are meant to be played on a 6581 since that's what Tim had at home back in the day, apparently).

vossstef, 2024-05-22:
@vanfanel may i ask you a question...
Is in a MISTer FPGA core the SID Filter Option valid for 6561 or both 6561 and 8580 ?

vanfanel, 2024-05-23:
@vossstef Good question.
In MiSTEr C64 core, SID Filter option is only available for 6581, but not for 8580.
As soon as 8580 SID is selected, SID Filter option becomes greyed out.
I have recorded a video so you can see it better.

https://github.com/vossstef/tang_nano_20k_c64/assets/837585/8826f7b2-fe06-4218-8849-284b405ab3e9

vossstef, 2024-05-23:
@vanfanel
i created a new branch for testing and dropped the tang_nano_20k_c64.fs file and the needed misterynano_fw_bl616.bin
You will find all here: https://github.com/vossstef/tang_nano_20k_c64/tree/55-tape-sound-and-userport-uart-option

please check Cartridge and SID and give feedback. Big Thanks for help !

Changes:
SID from MISTer (incl. Filter Options)
Cartridge fixed (MISTer)
RS232 UART
Tape Sound
I was not able to detect sound changes while playing around with the SID Filters. Maybe you have more luck.

vanfanel, 2024-05-24:
I am so grateful for this! Perfect SID means a lot to me, this chip had a truly magical sound...

vossstef, 2024-06-11:
Hi @vanfanel , i created a proposal for a new release with new features:
New features:
- 2nd SID option (Stereo) also for TN20k
- SID Filter options : Follin, Galway, Average, Strong, Extreme
not yet working: Turbo-232 serial Interface preparations

Bugfixes:
- digital Joystick DB9 fixed
- DualShock Paddle Emulation fixed
pls. flash new misterynano fw and new fpga bitstream in branch
https://github.com/vossstef/tang_nano_20k_c64/tree/63-porting-of-latest-redip-sid-pipelining-mode-for-tn20k-dual-sid-usecase
pls report any issues and many thanks for checking . thx !

vanfanel, 2024-06-11:
@vossstef I have flashed the latest .fs and .bin, but there's some problem with the bl616 fw bin.
I am flashing exactly this file:
https://github.com/vossstef/tang_nano_20k_c64/raw/63-porting-of-latest-redip-sid-pipelining-mode-for-tn20k-dual-sid-usecase/misterynano_fw_bl616.bin
...But it's missing all SID options. Maybe you uploaded the wrong file? An old version maybe?

vossstef, 2024-06-12:
@vanfanel just added again the firmware and fw.ini
Would be glad if you could check SID sound.
SID Filter settings like 'exteme' i checked with Ghosts_Goblins and there is a difference now. Not sure was my previous MISTer port behaving like that. Do you know?
Found some dual SID $D420 music and that seem to work.
Hope to hear from you soon. a big thx already !

vanfanel, 2024-06-12:
@vossstef With this new .bin, I could finally test the new SID options.

The only filter setting that sounds correct to me is "Follin".
Extreme sounds too raw. I believe "Follin" is the default, right?

The reference game is Ghouls'n Ghosts, not Goblins, because Ghoulsn'n Ghosts music is by Tim Follin and does very sophisticated use of filters.

vossstef, 2024-06-12:
@vanfanel the default filter in reDIP-SID is 'average'.
Please store those setting in OSD.

Do you think that the new Design is suitable and good enough in terms of SID sound ? I Don't need now an answer. If you tell me let's say in 2 days is also fine. Still need to fix something related to serial RS232 Interface. thx

vanfanel, 2024-06-13:
@vossstef I have been testing both SID implementations all morning now (by going back and forth between stable .fs and this branch's test .fs) and I like the sound in the MiSTer version better, specially for Tim Follin games.
Thankfully, things are quiet on my workplace, so I have time for these delicate tests.
I brought my hi-quality headphones with me, to do the tests as they deserve.

I will be doing more tests with demos and other games, and will try to provide a definitive answer in some days.
I think this question needs to be carefully considered.

I have also opened a thread on the MiSTer forum to request opinions:
https://misterfpga.org/viewtopic.php?p=87479#p87479

...But for now, I would say the MiSTer version sounds better to me, more akin to real C64, also in Ghosts'n Goblins.

vossstef, 2024-06-13:
Thanks for your effort !

Did you use the 'average' setting for your comparisson test?
I can't tell at the moment which coefficients are implemented.  maybe i nedd to dig a bit in MISTer. Will let you know if i Figuren out

vanfanel, 2024-06-13:
@vossstef Yes, but the "average" sounds pretty off compared to the MiSTer implementation.

I have also asked Sorgelig, the MiSTer creator, and he answered that the MiSTer implementation is more accurate, which confirms what I hear when doing these comparisions...

vossstef, 2024-06-13:
@vanfanel looks that i need to rework the code significantly respectively need to make use of the latest redip-sid varaint. I only got a version running that is about similar age that Mister sid. Lokks that Mister added some more tweaks that i am missing now. Anyway i learned a lot and will release an intermediate step just to fix DB9 Joystick and Paddle for now.

vanfanel, 2024-06-16:
> @vanfanel i got the dual SID based on well knows MIST'er core finally done and just created the release. Pls. let me know if there are problems.

Ok, I will test as soon as I can! Thanks!
I am currently traveling, so I will start testing on wensday as soon as I am back at home :)

vanfanel, 2024-06-18:
> @vanfanel i got the dual SID based on well knows MIST'er core finally done and just created the release. Pls. let me know if there are problems.

Ok! I've been testing the latest stable version, and 1-SID chip (both 6581 and 8580 models) sound perfect to me with games and demos.
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
vossstef, 2024-06-25:
I check the effects of the SID filters with a program called PSID64 1.0 Roland Hermans.
For the very first time i was able to check the differences in between all the different filters settings and also the loadable filter (It works ! ) that i stored in the branch (custom.flt and Alankila6581R3_3984_1.flt)

ojaksch, 2024-06-26:
Um, I'm begging for pardon but can't see any difference with the new "release". Everything is still working (fine) as long as I use jiffydos in the 1541. Am I missing something?
Did only some quick tests, a demo (d64) here, a game (d64 and crt) there...

vossstef, 2024-06-26:
the 1.3.0 release was buggy for sure. In the bitstream and firmware i  stored temporary directly in the main brach there should be at least the Bugs related to the new FLT filter load be gone( the 6th drive). About TAP load i feel unsure as not tested. i tested default dolphin c64 kernal and c1541 dolphin DOS and that was fine loadimg d64 images. jffy i didnt test so far.

vossstef, 2024-07-09:
@vanfanel and @ojaksch i did a 1.3.1 release.
Most important is that the TAP autoload is removed and README enhanced with lot of hopefully helpful information.
I checked D64, PRG, TAP, FLT, BIN and combinations and hopefully it is working better now. Buildin Dolphin Kernal is working fine as usual. Speeddos and jiffy didn't test yet.

May i propose that you start testing but initially set all loaders to 'no Disk' and enable one after another or better more and more.

vanfanel, 2024-07-10:
@vossstef I tried this 1.3.1 release today, and I did what you said:
CRT loading is broken. Try MultiLoad games, they don't work (simple SingleLoad CRTs work, but that's all that works).

vossstef, 2024-07-10:
@vanfanel sorry!
i forgot to test multiload crt....

TAP after CRT load is not working for exbasic II but that is the only Bug i found.
will habe this evening a look

vossstef, 2024-07-10:
@vanfanel ,
i just updated in the 1.3.1 release the tang_nano_20k_c64.fs file.
CRT multiload is working now.

vanfanel, 2024-07-10:
@vossstef Ah, yes, yes, thanks! :)
CRT (single and multiload) works fine.
D64 works fine.
TAP works fine.
PRG does not work correctly (it never did, so it has not broken now, try to load this for reference: https://csdb.dk/release/?id=138582)

May I suggest a couple of things?
-Can you add a key to eject the inserted media? For example, MiSTer uses BACKSPACE.
-Please move joystick-on-keyboard keys to ARROW KEYS + LEFT CTRL?

vossstef, 2024-07-10:
thanks
will check agin prg

vossstef, 2024-07-10:
Hi @vanfanel ,
i am using exactly the  bladerunner PRG you listed above to check the dual SID function.
It is working like a charm over here.
I use in addition Singularity https://csdb.dk/release/?id=135891&show=notes
Also  working like a charm over here.

Can you pls check with after PRG load with LIST +CR what is there ? Then do RUN + CR

BUT i realized in case if you set for the c1541 'no disk' and do OSD cold boot or Power cycle the c1541 sdcard loader get stuck and will not load any PRG.
propose till i figure out how to fix alway leave the D64 properly set as boot8.d64 or other D64. It will anyway not harm.
Can you pls. let me know ? Thx !

vanfanel, 2024-07-10:
@vossstef I confirm that I can use LIST and RUN with a PRG, but only if a .D64 is inserted. So yes, I am seeing the same bug :)

vossstef, 2024-07-11:
@vanfanel
i found the Bug and will release still today. PRG loader will then also work without mounted D64.

vanfanel, 2024-07-11:
> @vanfanel i found the Bug and will release still today. PRG loader will then also work without mounted D64.

Awesome! Great! I Will test ASAP

vossstef, 2024-07-11:
@vanfanel
release 1.3.2. out and thumbs up !

vanfanel, 2024-07-11:
@vossstef With release 1.3.2, all bugs with storage seem to be solved! Congratulations on such a good version!

Loading PRGs without a D64 inserted works perfectly now.

vossstef, 2024-07-12:
@vanfanel just let me know if you find something...

ojaksch, 2024-07-12:
I'm late to the party because of a sudden flu, but will start testing next week when beginning holidays.

vossstef, 2024-07-12:
@ojaksch take care of your health and enjoy holiday!
Let me know if you find bugs. After all this SID filter load release took endless time and caused lot of problems

Closed 2024-05-24.

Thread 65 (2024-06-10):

DB9 joystick directions swaped

HaraldSimon, 2024-06-10:
I have a MisteryNano 20k board with DB9 joystick connector.
The DB9 joystick works fine with MiSTery core on several games.

With this C64 core flashed, the directions of the joystick are swaped:
Left is right and reverse.
Up is down and reverse.
Fire button works.

I searched the files and modified the file "tang_nano_20k_c64_top.cst" after the command "// generic IO pins to use for e.g. db9 joystick"
pin 28 <> pin 25
pin 26 <> pin 29

The file looks now this way:
..
// generic IO pins to use for e.g. db9 joystick
IO_LOC "io[0]" 27;
IO_PORT "io[0]" PULL_MODE=UP IO_TYPE=LVCMOS33;
IO_LOC "io[1]" 25;
IO_PORT "io[1]" PULL_MODE=UP IO_TYPE=LVCMOS33;
IO_LOC "io[2]" 28;
IO_PORT "io[2]" PULL_MODE=UP IO_TYPE=LVCMOS33;
IO_LOC "io[3]" 29;
IO_PORT "io[3]" PULL_MODE=UP IO_TYPE=LVCMOS33;
IO_LOC "io[4]" 26;
IO_PORT "io[4]" PULL_MODE=UP IO_TYPE=LVCMOS33;
..
After flashing the modified version, the DB9 joystick works as expected.

vossstef, 2024-06-11:
bug confirmed with MiSTeryNano shield as Joystick Adapter.
Will be fixed in next release.

vossstef, 2024-06-11:
@HaraldSimon pls. flash new misterynano fw and new fpga bitstream in branch https://github.com/vossstef/tang_nano_20k_c64/tree/63-porting-of-latest-redip-sid-pipelining-mode-for-tn20k-dual-sid-usecase
pls report any issues. thx !

HaraldSimon, 2024-06-12:
I flashed the new core, DB9 joystick works now "out of the box" in correct manner.
Thanks.

Closed 2024-06-13.

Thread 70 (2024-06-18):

USB Joystick behaving strangely

BennehBoy, 2024-06-18:
Hi,

I figure this is probably an upstream issue with the BL616 code, or potentially a strange USB hub interaction. If I connect up an 8 pin D joystick via a D to USB adapter then game input when the joystick is at rest has down and right continually selected.  Any actual input overrides this.  I also have a HUB in this equation so it may also be introducing an issue but the combination works fine with other projects.

This joystick/adapter combination works fine on linux/windows/rpi but I'm unable to test it with the HUB circuit with the tang.

The adapter I'm using is homebrew -> https://github.com/BennehBoy/ZipstickUSB

VID/PID : 040b:6533

I've not encountered issues with it previously.

A generic USB SNES gamepad works without issue.

VID/PID : 0810:e501

harbaum, 2024-06-18:
I'd assume this is some misinterpretation of signed vs. unsigned axis reports sent by this joystick. I thought I had sorted this a long time ago ... may need another look ...

BennehBoy, 2024-06-19:
I noticed that the firmware for the BL616 included in the nanomig core has a larger file size and a newer datestamp so also tried that - although everything seems to function fine, the joystick issue is still there.  Is the nanomig 616 firmware specific to that core?

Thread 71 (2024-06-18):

Unloading .CRT doesn't work

vanfanel, 2024-06-18:
CRT files work perfectly well with the core, but once loaded, they can't be unloaded unless the system is physically power-cycled.
Unloading a CRT and then resetting doesn't work either.

vossstef, 2024-06-18:
Hi @vanfanel, i wrote some hints how to operate in the readme.

To unload a CRT ROM you have first to set in  'STORAGE' , 'CRT ROM ' the setting 'No Disk' and then perform a 'ColdBoot' from the 'SYSTEM' Menue.

vanfanel, 2024-06-18:
@vossstef Ah! I understand now. Sorry to open this as an issue, based on my own ignorance.
And many thanks for the explanation!

Closed 2024-06-18.

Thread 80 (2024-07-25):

MISS keys triggering delete

SanguineBrah, 2024-07-25:
I'm not sure if this is an issue with FPGA companion or the core, so apologies if I am posting in the wrong place.

In my testing, any key marked as MISS in the C64 keymap table seems to be interpreted as MATRIX(0,0) by the core, which is the delete key.

However, this is not the case with the modifier keys, which just (correctly) do nothing if they are marked MISS.

vossstef, 2024-07-27:
Hi @SanguineBrah ,
i updated the firmware and swapped in the release section of c64 and vic20 core.

Pls have a try and report.
Thx for feedback to improve the core !

SanguineBrah, 2024-07-27:
Thanks. I've tested the new firmware on the release page and a lot of keys now trigger a left shift event, including HOME, END, PGUP, PGDN, BREAK, NUMLOCK, SCRLOCK, TAB and PRINTSCR. The restore key (F11) also triggers a left shift at the same time as successfully triggering a restore event.

For testing, I am using [Anykey](https://github.com/T-Pau/Anykey).

vossstef, 2024-07-27:
i implemented left shift as workaround!

is that fulfilling your needs?

left shift didn' produced  unwated  Charakters on the screen

vossstef, 2024-07-27:
i implemented left shift as workaround!

is that fulfilling your needs?

left shift didn' produced  unwated  Charakters on the screen

SanguineBrah, 2024-07-27:
I don't think shift+restore does anything so it should be okay as a workaround, thanks.

vossstef, 2024-07-27:
@SanguineBrah ,
i agree.
Restore is bare NMI trigger if i recall right. Didn't' tested all those 'freezer' CRT yet....

harbaum, 2024-07-29:
Indeed, the MISS code is sent to the core as 0 and if 0 actually is a valid code then this triggers something.

This is something I'll address in the new FPGA Companion firmware asap ....

Closed 2024-07-27.

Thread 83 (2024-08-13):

Feature suggestion: serial over spare I/O

SanguineBrah, 2024-08-13:
The RS-232 over USB works well, but I have found that its usefulness is limited because it requires a host device on the other end, which means it is only good for a null modem link with a PC.

If it is possible to put this out on spare I/O pins instead, we could connect it through a MAX3232 for a standard serial port, wire up an FTDI adapter module for USB connection or wire a header for an [ESP-01 wifi module](https://www.microchip.ua/wireless/esp01.pdf) for onboard wireless telnet using the [zimodem firmware](https://github.com/bozimmerman/Zimodem).

harbaum, 2024-08-13:
For telnet there's actually a way nicer solution. The latest firmware runs on the pi pico-w and the esp32 as well and these have wifi built-in.

This is not released yet, but I am using these with the Atari st core to redirect rs232 via wifi so I can dial via Internet into BBS' that way. This gives quite a retro networking experience.

vossstef, 2024-09-10:
@SanguineBrah i added an option for hw uart pin interface .
Do you want to test it ?

SanguineBrah, 2024-09-10:
> @SanguineBrah i added an option for hw uart pin interface . Do you want to test it ?

That's great! I'll take a look at it tomorrow.

SanguineBrah, 2024-09-11:
I have done some testing using CCGMS with the RX & TX wired up to a Wemos D1 Mini with wifi modem firmware. Everything works as expected. I am able to reach up to 2400 baud without dropping any characters in either UP9600 or Vicmodem modes - to reliably go faster, we would probably need flow control, which would use up two more spare I/O pins (it is arguable whether that would be worth it). I was not able to get the Swiftlink modes to send any data but I am not familiar with that device so I may be missing something there.

vossstef, 2024-09-11:
> Yes, I tested on 20k as I don't own any of the others. I haven't seen any side effects or stability issues so I think it should be okay to merge if the other models are also working the same way as this.

ok then will merge and create a draft release for easier use. Still need to consult @harbaum  to agree pinmap for TN25k/TM138k PMOD. share.

harbaum, 2024-09-11:
The pin sharing sounds fine to me. I should have broken out the unused pin on the pmod adapter ...

vossstef, 2024-09-11:
@SanguineBrah i created a pre-release and dropped the bitstreams
readme is also updated

Closed 2024-09-11.

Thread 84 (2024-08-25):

Volume control scale

SanguineBrah, 2024-08-25:
It sounds to me like the volume control does not scale correctly. 33% to 66% sounds like a small increase but 66% to 100% sounds a lot louder. I wonder if perhaps it has been scaled linearly, where it should be logarithmic.

harbaum, 2024-08-27:
It probably is linear as the Atari ST core also uses linear scaling. This was never meant to be the main volume control. Your display hopefully has its own volume control. The volume control inside the core was mainly meant to bring the audio volume into some sane range the display nicely copes with. One of my cheap screens e.g. has quite distorted audio if the volume of the input signal is too high although this is a pure digital thing and even full volume is transmitted lossless (e.g. no clipping) and should replay just fine. But it doesn't unless i set the core to not use the full digital signal range.

harbaum, 2024-08-27:
It's not even linear. It's actually 1/4 (33%), 1/2 (66%) or 1 (100%) as sound scaling then is just some bit shifting. See:

https://github.com/harbaum/MiSTeryNano/blob/58f5a73f55c89a65a9a11aea7cc5ac41028b68dc/src/misterynano.sv#L488

So we might better name the levels 25%, 50% and 100% ...

SanguineBrah, 2024-08-27:
I've built a portable machine using this core, and it was a bit awkward to find a suitable low profile pot to mount near the amplifier board inside the lid, so I've been relying on the software control so far:

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

It's not a big deal really, The existing options are usable enough, I just thought they could do with a tweak to bring them more in line with perceived loudness.

SanguineBrah, 2024-08-27:
> So we might better name the levels 25%, 50% and 100% ...

Actually, this description does sound a lot closer to what I am hearing - a big jump between 50-100 and a small difference between 25-50.

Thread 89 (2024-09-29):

Issue with games that use paddle inputs as extra buttons

SanguineBrah, 2024-09-29:
I tried out [Gates of the Ancient](https://drmortalwombat.itch.io/gates-of-the-ancient) today and found that it is currently unplayable with this core when using a DE9 joystick (in this case, the ArcadeR plugged into harbaum's midi shield).

This is because it uses pins 5 and 9, which are paddle inputs, as extra buttons. On the Nano, the extra button reports as permanently depressed, which activates the cockpit menu and means you can't steer the ship.

I also found out that there are [a few other commercial games](https://retrocomputing.stackexchange.com/questions/2499/which-c64-games-support-two-buttons) which used the paddle inputs in this way.

vossstef, 2024-09-29:
will look into that over the next weeks

vossstef, 2024-10-04:
Hi @SanguineBrah,
could you please test your game with my latest release ?
I checked with a diagnostic tool the 2nd and 3rd button but are not sure is the function properly for a game implemented.
thanks!

SanguineBrah, 2024-10-04:
In Gates of the Ancient, the behaviour is the same. I tested further using [Game Controller Tester](https://commodore.software/downloads/download/148-c64-testers/11748-game-controller-tester-v1-0), which shows that all POT values are at zero and the 2nd (64GS) button is permanently activated on both ports. Pressing the 2nd button on my joystick doesn't change the reading. By opening my joystick and putting it into Atari mode, it grounds the pin instead of putting 5v on it - in this case, when I press the button, the tester shows the 2nd button being released and the POT reading jumps to 255.

I tested on my real C64 to compare the behaviour (joystick back in C64 mode). Using the Tester program on the real machine, all POT values show as 255 and the 2nd button is not activated on either port. When I press the 2nd fire on my ArcadeR joystick, one POT drops to 2 and the 2nd fire button shows as activated in the tester. I also tested this joystick on Gates of the Ancient and the 2nd fire button is working correctly there on the real machine.

vossstef, 2024-10-04:
@SanguineBrah thanks for Feedback!

will also use this test sw to figure out and check in moment detail.

in which mode do you use the ArcadeR? i saw that there are pcba solder bridge fitting options for different computers.

the misteryshield and my core is only compatible to atari st 2 Button Joystick types meaning that a closing  switch in between d9 pin 9 and GND is expected. C64 Mode (pin9 and +5v) or atari 2600 vcs will not work.

SanguineBrah, 2024-10-04:
I've tested it in both. It looks like the Atari mode (connecting to GND) responds but the behaviour is inverted - i.e. POTs all default to 0 (2nd button active) then show as 255 (2nd inactive) when pressed.

I have also tested using a classic Atari 2600 joystick with only one button and the 2nd button shows in the tested as being permanently active (POTs at 0).

vossstef, 2024-10-04:
@SanguineBrah
i found the bug and it was inversion of the analog data.
Fixed now in a new release **v1.5.1**
As mentioned for Tang D9 port use the Atari ST mode http://wiki.icomp.de/wiki/DE-9_Joystick of ArcadeR

SanguineBrah, 2024-10-04:
@vossstef Thanks, v1.5.1 seems to be working great! Everything looks good in the tester with my joystick and Gates of the Ancient is playing correctly just like it plays on my C64.

Closed 2024-10-04.

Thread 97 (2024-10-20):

Video mode switching PAL/NTSC cause OSD to stall

vossstef, 2024-10-20:
power-cycle Tang Board to recover till soltion available.

Closed 2024-10-25.

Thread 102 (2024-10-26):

everything is a bit slower/lagging in V1.6.2

sgrockfort, 2024-10-26:
Hello, just noticed a bug in 1.6.2 .... everything is a bit slower/lagging... Sound and movement are lagging.... This happens in PAL & NTSC mode... I tried it with "Boulder Dash 1".. Problem did not appear in v.1.6.1

Thanks
Michael

vossstef, 2024-10-28:
Hi @sgrockfort, i created a 1.6.3 pre-release to fix the lag issue...
pls. have a try...

sgrockfort, 2024-10-29:
@vossstef  , perfect thank you... I can try it today evening...

sgrockfort, 2024-10-29:
hi @vossstef  , just tested the 1.6.3 ... Switching between pal & ntsc works fine.... gaming in PAL mode also works good.. I am not 100% sure!!!  but in PAL mode, it feels a very tiny bit faster as usual - also it seems that the game speed in PAL and NTSC is equal... Usual NTSC always a bit faster.....  But it's ok imho.

Also I noticed that in NTSC mode the sound seems to be broken.... The sound is interupted every 1-2 seconds by a very soft click sound... This sound is even noticable directly in the C64 start screen... In PAL mode the sound is fine...

I made my tests with standard settings - no filter files or something like that.
For game-test I used Boulder-Dash 1 once more :-)

vossstef, 2024-10-29:
@sgrockfort Thanks!
I tested a lot in PAL mode but obviously too little in ntsc...  Those sound issue i didn't detected. Will have again a look and let you know.

vossstef, 2024-10-29:
Hi @sgrockfort ,
i was also able to detect the noise but not the speed topic.
i synthesized again with IDE 1.9.10.03 and a buildscript. Checked with one Game and the clicking noise in NTSC seeme to be gone.
Stored the file as pre-release v1.6.4
Maybe could you also check... big thx !

sgrockfort, 2024-10-30:
Hi @vossstef  , no problem.. I'll check it later.. Thanks for fixing...

sgrockfort, 2024-10-30:
@vossstef , good evening, I flashed the v.1.6.4, but in NTSC mode I still have the sound issue.. I attached a short audio record how it sounds..  I flashed it twice, just to ensure that I didn't made a mistake..

[Neue Aufnahme.zip](https://github.com/user-attachments/files/17577592/Neue.Aufnahme.zip)

vossstef, 2024-10-30:
@sgrockfort thx for feedback. A  nightmare...
FPGA is entirely full and i assume a malfunction due to that. Will try to exclude certain function e.g. MIDI to free some resources and try clock constrains... Will try to fix.

sgrockfort, 2024-10-31:
@vossstef  , just let me know if I can help with testing.. Completley no problem, I just need some time sometimes ;-)

vossstef, 2024-11-01:
@sgrockfort
created now a v1.65 pre-release....

From early tests it looks better but let's see..

sgrockfort, 2024-11-01:
p.s. also tried with other sound chip settings.

vossstef, 2024-11-01:
@sgrockfort thanks !
i tested a single tn20k board and also a tp25k using different games (also Boulder Dash) and sound was always fine both in PAL and NTSC mode. Tested also G64 disk, RS232 with terminal , MultiCRT and freezer all was ok.

Will flash an another tn20k to figure out those sound noise topic...

sgrockfort, 2024-11-01:
@vossstef  , hmm, maybe it's something specific to my setup... I just also noticed that this click sound also appears when the volume is completley muted.. Also noticed that the gamesound gets very quiet ini the rhythm of the click.... I think what I hear is the result of switch off the sound off/on in this rhythm... It only appears in NTSC mode - that's why I thought its something about my screen. But with 1.6.1 it's okay.

But if you cannot reproduce it, it's maybe really something related to my setup and as for me no need to change anything.. In general I only use pal :)

sgrockfort, 2024-11-02:
@vossstef  , I can confirm that this problem is related to my screen.. I switch my screen to my old 1080p screen and there is no sound issue in NTSC anymore... I still cannot understand why it not happen with v.1.6.1 but anyway... Maybe it's something with upscaling ?! (new Screen is 4k)

Thank you for helping and sorry for the confusion.

sgrockfort, 2024-11-02:
@vossstef  ,  just an addional info - I found out that with v1.6.1 the screen-resolution in NTSC is 800x480@60Hz and with 1.6.5 it is 800x480@58Hz (if my screen shows the values correctly) .... Maybe my screen is just a bit sensitive about it and not tolerant about it...

vossstef, 2024-11-02:
@sgrockfort i found a solution now and still testing the correction. Looks that the DCS clock management is causing the trouble. new fix is simple not needing that.😀

vossstef, 2024-11-02:
@sgrockfort , i created a v.1.6.6. based on the working 1.6.1

sgrockfort, 2024-11-02:
Hello @vossstef  , I'm sorry but in my environment the NTSC-sound is still broken. It seems to be a very specific behavoir related not to all screens.. As for me, no need to change it. But if you want/like to continue work on it, I can continue testing. Completley no problem... :-)

vossstef, 2024-11-02:
I checked many games and including Boulderdash and SID sound reference Ghost'n & Goblins in NTSC and PAL mode using HDMI to USB converter and not too old Dell 4K monitor without any noise problems. G64 Disks are now working, RS232 is fine and MultiCRT ROMs, freezer CRT, Kernal, CRT and PRG load after power-up is working.
Maybe your noice issue is specific to your setup.

I found malfunction if the OSD XML file is missing on the sdcard.

sgrockfort, 2024-11-03:
@vossstef  , yes, I also think so.. It is something about my specific screen.. As I said, with my old/other screen I haven't any problems also.. I think this screen don't come clear with the 58Hz..

Thanks once more for all you work. I really like your project.. If you need a tester for other future problems - no problem :-)

Michael

vossstef, 2024-11-03:
@sgrockfort ,
all fine and thanks for all the effort in testing and news that your other screen works fine !

Closed 2024-12-01.

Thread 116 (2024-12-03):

Adding support for more USB keyboards, possible?

vanfanel, 2024-12-03:
Hi there,

I've been happily using this absolutely fantastic C64 core for some time now, and recently tried a mechanical 8bitdo keyboard with it. It didn't work. Same with another mechanical QNIX keyboard I have.

However, my old trusty (but not so pleasant to use) Logitech keyboard+mouse combo works perfectly well with it!

This is how GNU/Linux's `lsusb` sees the working keyboard:
`Bus 001 Device 005: ID 046d:c534 Logitech, Inc. Nano Receiver`

And this is how it sees the non-working 8bitdo mechanical keyboard:
`Bus 001 Device 006: ID 2dc8:5201 8BitDo 8BitDo Retro Keyboard Receiver`

So, I guess this depends on the FPGA Companion (bl616) firmware, right?
Where in that firmware should I add new keyboard identifiers? Can that firmware be rebuilt on GNU/Linux easily? I hope so! :)

vossstef, 2024-12-03:
Hi @vanfanel ,
great to hear from you again and i am very happy that you are still using the core !
Let's ask @harbaum what could be a blocking factor for this specific Keyboard to see is there a fix possible in the FW.

camplusplus, 2025-03-08:
I also have USB keyboard (with joystick) issue, reported to https://github.com/harbaum/FPGA-Companion/issues/15

camplusplus, 2025-08-25:
I found solution by converting usb to ps2 with esp32 and using ps2 to usb convertor.

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

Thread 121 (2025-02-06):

Unable to load Magic Formel

geniac, 2025-02-06:
There seems to be an issue with the Magic Formel cartdridge.
No matter which version ist being used, the system boots with the cartdrige "inserted" but the Magic Formel menu does not show up.

Info and Download link:

http://rr.c64.org/wiki/Magic_Formel

It works in Vice, but i had no luck with the tang

Greetings

Lars

vossstef, 2025-02-06:
Hi @geniac, to me it look that Magic Formel cartridge is presently not supported from the C64 MiSTer core on that this project is based on.

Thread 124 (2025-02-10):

Can't update the C64 core on Tang Nano 20K flash anymore. Can you lend a hand, please?

vanfanel, 2025-02-10:
Hello there @vossstef

I have been updating my TangNano 20K to the latest C64 core via the USB-C cable for a year or more.
I was trying to update to the 1.8.0 release today, and I am getting errors I had never seen before:

```
manuel@debian:~/C64$ sudo openFPGALoader -f tang_nano_20k_c64.fs
empty
write to flash
No cable or board specified: using direct ft2232 interface
Jtag frequency : requested 6.00MHz   -> real 6.00MHz
Parse file Parse tang_nano_20k_c64.fs:
Done
DONE
after program flash: displayReadReg 00004421
        CRC Error
        Memory Erase
        Non-JTAG configuration is active
        Security Final
Erase SRAM DONE
Jtag probe limited to %d MHz6000000
Jtag frequency : requested 10.00MHz  -> real 6.00MHz
Detail:
Jedec ID          : ff
memory type       : ff
memory capacity   : ff
Detail:
Jedec ID          : ff
memory type       : ff
memory capacity   : ff
RDSR : ff
WIP  : 1
WEL  : 1
BP   : f
TB   : 1
SRWD : 1
flash chip unknown: use basic protection detection
unlock blocks
Error: block protection is set
       can't unlock without --unprotect-flash
Error: write to flash failed
Error: Failed to program FPGA: Error: write to flash failed
```

And then, if I pass the "--unprotect-flash" parameter, I get:

```
manuel@debian:~/C64$ sudo openFPGALoader -f tang_nano_20k_c64.fs --unprotect-flash
empty
write to flash
No cable or board specified: using direct ft2232 interface
Jtag frequency : requested 6.00MHz   -> real 6.00MHz
Parse file Parse tang_nano_20k_c64.fs:
Done
DONE
after program flash: displayReadReg 00004421
        CRC Error
        Memory Erase
        Non-JTAG configuration is active
        Security Final
Erase SRAM DONE
Jtag probe limited to %d MHz6000000
Jtag frequency : requested 10.00MHz  -> real 6.00MHz
Detail:
Jedec ID          : ff
memory type       : ff
memory capacity   : ff
Detail:
Jedec ID          : ff
memory type       : ff
memory capacity   : ff
RDSR : ff
WIP  : 1
WEL  : 1
BP   : f
TB   : 1
SRWD : 1
flash chip unknown: use basic protection detection
unlock blocks
timeout: ff ff ff
ff
wait: Error
Error: write to flash failed
Error: Failed to program FPGA: Error: write to flash failed
```

This is on GNU/Linux, of course.
Do you have an idea on what could be going on, please?

vossstef, 2025-02-10:
hi @vanfanel, looks to me that something wrong with the openfpga loader...
i also had problem with that tool and i use now the 1.9.10.03 gowin Programmer sw instead also under Fedora.
had also the feeling after update to f40 / f41 problems got more accute.

you need to run the gowin programmer as sudo otherwise it will fail at some point.

gowin programmer also has issues with "stoneold" GW1 devices... i had to use for TN9 very old toolset to get that programmed.

vanfanel, 2025-02-10:
Thanks @vossstef

I'm trying to use the GoWin programmer but it's VERY confusing. Where is the option to flash the .fs files to the tangnano20k board? I can't seem to find a way to open .fs files or flash them...

vossstef, 2025-02-10:
@vanfanel pls have a look into Till's or my instruction document how to use the programner

vanfanel, 2025-02-11:
> [@vanfanel](https://github.com/vanfanel) pls have a look into Till's or my instruction document how to use the programner

Thanks, looked in the docs and found the precise instructions.
I hope OpenFPGALoader works again someday.. it was way better and easier on the Linux CLI.
The graphical Gowin programmer is clunky to say the least...

Many thanks! Now enjoying the latest core version again! :)

vossstef, 2025-02-13:
@vanfanel
@harbaum

just saw this !

https://dl.sipeed.com/shareURL/TANG/Debugger/onboard/BL616/202501231x

looks they found issues and fixed something...

harbaum, 2025-02-13:
Please be careful when using these. I had trouble with different tn20k versions when some of them needed  signed/encrypted firmware versions and some did not.

My recommendation is to only update when you really have a problem and not just because "newer is better".

Closed 2025-02-11.

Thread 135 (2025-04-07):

TheC64 + tang_nano_20k_c64: How to send the menu open command?

vanfanel, 2025-04-07:
Hi there!

I don't know it someone had tried before, but I connected the TheC64 keyboard to the TangNano20k+misteryshield20k, and it woks perfectly well.
(TheC64 is a full size C64 replica running an small GNU/Linux system with the VICE emulator on top: https://www.c64-wiki.com/wiki/THEC64)

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

...So my dream of gutting a TangNano20k+misteryshield20k inside TheC64 is near.
However, since the C64 has no F12 key, there's no way to enter the core menu.

Is there a couple of pins somewhere on the TangNano20k or on the misteryshield20k that I can use to attack a switch to them so I can enter the core menu with that?

Thanks!

vossstef, 2025-04-08:
Hi @vanfanel ,
the F12 key is something special in the Fpga companion fw. you will need a customization in that. never tried before but you can transfer the two tn20k button state into the fw. hope my c64 is doing that already and ifnot will add.that. bigger part is to modify fw that one of the two received buttons is equivalent to F12. All maybe possible. btw one of the buttons is already in use to swap joyports and other one if i recall unused. sorry for the short answer but rather busy at the moment.

vanfanel, 2025-04-08:
> Hi [@vanfanel](https://github.com/vanfanel) , the F12 key is something special in the Fpga companion fw. you will need a customization in that. never tried before but you can transfer the two tn20k button state into the fw. hope my c64 is doing that already and ifnot will add.that. bigger part is to modify fw that one of the two received buttons is equivalent to F12. All maybe possible. btw one of the buttons is already in use to swap joyports and other one if i recall unused. sorry for the short answer but rather busy at the moment.

Many thanks for the response! Not in a hurry at all, don't worry :)
Isn't it possible to use a couple of pins on the companion board? It has 8 pins (which I don't know what they do, to be honest, and I can't find any information on what they do).

vossstef, 2025-04-08:
@vanfanel , you could also use one of the spare FPGA pins that i don't use for the DS2 interface for a Key F12 button. But the issue of forwarding the pin press into the firmware will remain. There is some work to do...

harbaum, 2025-04-09:
Does that keyboard have a different key you could re-purpose? Maybe some rarely used one? Or a long press on restore or the like? That could be done inside the FPGA Companion firmware and would not need any special support on FPGA side.

vanfanel, 2025-04-09:
> Does that keyboard have a different key you could re-purpose? Maybe some rarely used one? Or a long press on restore or the like? That could be done inside the FPGA Companion firmware and would not need any special support on FPGA side.

The keyboard doesn't have any special keys I know of, other than being a plain C64 keyboard.
But a key that has not much use on a C64 is the "pound" key, which on GNU/Linux produces scancode 0x27, according to XEV:
```
KeyPress event, serial 39, synthetic NO, window 0x1600001,
    root 0x400, subw 0x0, time 83083999, (-627,102), root:(244,550),
    state 0x10, keycode 20 (keysym 0x27, apostrophe), same_screen YES,
    XLookupString gives 1 bytes: (27) "'"
    XmbLookupString gives 1 bytes: (27) "'"
    XFilterEvent returns: False
```
I think the key should be remapped to the "pound" symbol before being used for menu toggling however?
(It has a "pound" symbol on it)

vossstef, 2025-04-09:
Hi @vanfanel ,
please consider to make use of this tiny extra Keyboard for the F12 Key topic . Some users found that helpful for A2600.
https://github.com/vossstef/A2600Nano/issues/7

harbaum, 2025-04-09:
Ah ... yes, of course.

And  one could actually make a little firmware for a pico (or pico zero) that implements a hid keyboard with just F12, the cursor keys and the return key as a 'mistery menu controller'. This would be super cheap but also flexible.

vanfanel, 2025-04-10:
Thanks for thinking this alongside me, guys!
But the solution may be a tad easier.
On GNU/Linux, as I said, the "pund" key sends `keycode 20 (keysym 0x27, apostrophe)` right now.
Ok, I just have to remap that to F12, and presto! It has to work like that!
So.. where is the keyboard mapping file? I guess that's part of the companion programming, right?

vossstef, 2025-04-10:
@vanfanel ,
please have a look to hid.c and search for
// F12 toggles the OSD state. Therefore F12 must never be forwarded
to get an idea

Maybe you compile for your own purposes a modified Version and try it.

vanfanel, 2025-04-11:
> [@vanfanel](https://github.com/vanfanel) , please have a look to hid.c and search for // F12 toggles the OSD state. Therefore F12 must never be forwarded to get an idea
>
> Maybe you compile for your own purposes a modified Version and try it.

Ah, yes, that's promising. I see this line:
https://github.com/harbaum/FPGA-Companion/blob/dc5af8d6a0e69a1a1df5227406d4f1e999a6da47/src/hid.c#L131
...where it seems that the menu is toggled if the value in the buffer position is `0x45`.
I understand that `0x45` must be the scancode for F12, right?
If I connect the TheC64 keyboard to a GNU/Linux system, the "showkey" command tells me that the "pound" key on the keyboard has scancode 0x0c.

However, after building the latest FPGA-companion core from latest GIT code, it doesn't work with the latest stable tang_nano_20k_c64 release (1.9.1) to complete this experiment.

Can you please point me to the exact commit in https://github.com/harbaum/FPGA-Companion/commits/main/ that corresponds to the FPGA-Companion release 1.2?

vanfanel, 2025-04-11:
@vossstef Well, latest commit from March 3 doesn't build:
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
vanfanel, 2025-04-15:
@vossstef I'm almost there with the correct mapping! I am only missing the RESTORE key code to send.
The Readme says that RESTORE is mapped in F11, but looking at the F11 mapping in https://github.com/vossstef/tang_nano_20k_c64/blob/c2c524513433d8a0d72023f8ad7484ba1b012dda/src/misc/c64_keymap.v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, I see it's sending `3'd7,3'd1`  which is the code for LSHIFT.

What's the code I should send for RESTORE?
I know it's not on the C64 matrix, according to https://www.c64-wiki.com/wiki/Keyboard,
so maybe it's being treated as a special case in the companion firmware just like F12, but.. where?
It's mentioned in https://github.com/harbaum/FPGA-Companion/blob/dc5af8d6a0e69a1a1df5227406d4f1e999a6da47/src/hid.c#L52 but nothing else...

vossstef, 2025-04-15:
Restore is used for triggering nmi interrupt in c64

vanfanel, 2025-04-15:
> Restore is used for triggering nmi interrupt in c64

Yes, I know. But where is it mapped? In the core? Or in the Companion?
Can you point me to where it's mapped, please?

vanfanel, 2025-04-15:
> [@vanfanel](https://github.com/vanfanel), basically i am using a 2nd communication channel from companion originally intended for Joystick Numpad... numpad(6) for NMI (F11) and numpad(7) for swap of joystick ports. I think we have at the moment a hard mapping for those Keyboard joystick still in companion.

Can you point me to the code of that hard mapping, please?

vossstef, 2025-04-15:
@vanfanel ,
it's in the hid.c line 39 and following.

vanfanel, 2025-04-16:
> [@vanfanel](https://github.com/vanfanel) , it's in the hid.c line 39 and following.

This exact line is where F11 is assigned to RESTORE:
https://github.com/harbaum/FPGA-Companion/blob/dc5af8d6a0e69a1a1df5227406d4f1e999a6da47/src/hid.c#L66
So setting that to 0x2b instead of 0x44, I got the physical RESTORE key working on the TheC64 keyboard!

vanfanel, 2025-04-16:
@vossstef Now, RESTORE (0x2b) seems to activate both RESTORE and LSHIFT, as in:

https://github.com/user-attachments/assets/7ac33207-11b2-45ef-922a-ec0c240cfcc2

So, to prevent that, I changed this:
https://github.com/harbaum/FPGA-Companion/blob/dc5af8d6a0e69a1a1df5227406d4f1e999a6da47/src/hid.c#L134
For this:
`if(!osd_is_visible() && (buffer[2+i] != 0x2b)) /* Don't send the RESTORE key to the core */`
...so the key isn't sent to the core as a normal key.

...and now, RESTORE is working as intended! Yeah!

https://github.com/user-attachments/assets/c17efb11-40af-4f35-850d-caad0e030051

vossstef, 2025-04-16:
@vanfanel,
congratulations  and great success !

have not much time for core at the moment but think as keymapping is inside the core it should be easier possible to extract Numpad and those extra handlings like restore.  Need to dig into that...

vanfanel, 2025-04-17:
@vossstef Another small question if you don't mind.
In this line:
https://github.com/harbaum/FPGA-Companion/blob/755c88de03dc643b59d2de5fe4c6c9cf6170dabf/src/hid.c#L139
you guys detect the UP arrow keypress inside the GUI.
However, the TheC64 doesn't have an UP key, it has the same DOWN/UP key as a C64 keyboard, with UP needing SHIFT+DOWN/UP.
So, is there a way for me to detect that SHIFT is pressed?

vossstef, 2025-04-17:
@vanfanel , same idea i had also more than a year ago but didn' found time to think about.

vanfanel, 2025-04-17:
@vossstef Ok, no hurries, thanks for the answer!

What about SHIFT LOCK? Using a normal USB keyboard, the CAPS LOCK key doesn't work as it does on a real C64: it acts as LSHIFT.
On a real C64, SHIFT LOCK lets the user change lettercase permanently.

harbaum, 2025-04-22:
I just commited a change to the FPGA Companion that will allow you to specify the key in the ini file:

```
; firmware options
; HID key code of OSD/menu hotkey
option hotkey=69

```

vossstef, 2025-04-22:
> [@vossstef](https://github.com/vossstef) Ok, no hurries, thanks for the answer!
>
> What about SHIFT LOCK? Using a normal USB keyboard, the CAPS LOCK key doesn't work as it does on a real C64: it acts as LSHIFT. On a real C64, SHIFT LOCK lets the user change lettercase permanently. It's not a normal key: it's a physical electric latch. That doesn't seem to be the case on the core.

@vanfanel i need to adjust the c64 / vic20 core a bit

vossstef, 2025-04-23:
@vanfanel let me first update the core to cover the shift cursor and shift Fx Key topc and will look then into the RESTORE too.

vossstef, 2025-04-29:
@vanfanel
i did't forgot you... Just created a pre-release for you that already adds the auto shift for Cursor up/left and the Function Keys.
https://github.com/vossstef/tang_nano_20k_c64/releases/tag/v2.0.1

CAPS Lock need also a fix and still need to do a refactoring in the Numpad area.

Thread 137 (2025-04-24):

Misteryshield20k_rpipico - keyboard/mouse USB doesn't work, while D3,D4 is on, D2 is off. Joystick works (on debug)

luciust, 2025-04-24:
The setup: soldered the board, powering via Tang Nano 20k USB-C, the power draw is 1W just as if the Tang is running standalone. Atari ST core starts up and I get the desktop - I'm using original working Atari ST core here before moving to C64.

So using the https://github.com/vossstef/tang_nano_20k_c64/blob/main/board/misteryshield20k_rpipico/README.md board, and found out so far:
- the FPGA Companion 1.2 release (fpga_companion.uf2) works with RPI Pico 1 (original board)
- the FPGA Companion 1.2 release (fpga_companion_rp2040_zero.uf2) works with RPI Pico W

by works I mean I get D3 LED on pretty much at boot and couple seconds later D4 also lights up. D2 is off, and it stays this way - nothing is connected.

The Problem: When connecting mouse, keyboard to USB - all I get is brief flash of the IR LED in mouse and then it's off. **Neither work.** D2-D4 stay the same, Tang 20K works during all the USB connections.

My suspision is that the 12MHz crystal might be wrong or soldered incorrectly, other stuff on the board should be OK. Any pointers what I should look at now ?
I do have the chinese RPi Pico (those in purple with 16MB Flash) which are good for making Atari XL cartiges...

harbaum, 2025-04-24:
There's a lot I don't understand in your report. The pi zero does not fit onto the shield and the version for the waveshare zero also won't work on the regular pi pico as the USB is wired up differently.

luciust, 2025-04-24:
I'm using RPi Pico W and RPi Pico here, not the "pi zero". Actually moved to RPi Pico since the I thought the fpga_companion.uf2 was for RPi Pico W - but it didn't work - there was no LED after copying the uf2 onto it - but the RPi Pico 1 - the first original board did start with it.

As for the "whaveshare zero" - I do have this one: https://www.aliexpress.com/item/1005008250289610.html but I haven't  tested yet - need to make sure it's pin compatible (it's suppose to be)

luciust, 2025-04-24:
It seems I have similar situation: https://github.com/harbaum/FPGA-Companion/issues/36

I've copied over u2f on original Pico (not Pico W) and
- it flashes it's green LED constatnly when connected to the mysteryshiled29k_rpipico, but D2,D3,D4 does not light up
- it flahsed 13 times when connected as standalone - to power only

Here's the video when RPi Pico is conneced to the shield: https://www.youtube.com/watch?v=4EKl9PAC8ww

Investingating further - this might be related to copying file vs. flashing...

luciust, 2025-04-24:
Further investigation on Pico's:

I've build the fpga_companion.uf2 from the source and copied to RPi Pico and RPi Pico W:
What changed:
- both Pico and Pico flash it's green LED when connected to shield
- D2,D3 and D4 are off
- mouse, keyboard - don't work they get a flash of their LED but no furhter action
- Tang Nano 20K doesn't boot the ST core properly - it stays at the white screen with two orange LED on and crashes there - no more reaction to the reset button. When Pico is disconnected - Tang boots Atari ST to the desktop.

Internesting!

luciust, 2025-04-24:
I got something!

```
SYS: Core ID: 01
SYS: Core: Atari ST
SYS: FPGA ready after 3070ms!
SYS: SYS set value R = 3
SDC: ---- SDC init ----
SDC: SD not ready, status = 34
config[0] = 01
No valid config found, neither on sd card nor in core
```

harbaum, 2025-04-24:
So what are you missing? No config found just means that it's a rather old core and uses the old method. But that's no error and should just work.

You don't get any output regarding detected USB devices? If you have some USB peripherals connected you should see some debug output regarding USB.

luciust, 2025-04-24:
Yes, got old core (previous), and I'm missing the USB. So crystal and CH334U are the suspects, right?

luciust, 2025-04-24:
Just looking at the schematics - I think it's gonna be the crystal - I need to check it with scope...

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

luciust, 2025-04-24:
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

luciust, 2025-04-26:
Well it *WAS* the 12MHz crystal.

Let's recap:

- I've soldered the board with wrong crystal - it was not the PIN 1 XI, 2 GND, 3 XO, 4 GND but VCC, GND, OUTPUT. I got the right crystal 12MHz:

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

- but the problem was the orientation, first of all the denoted PIN 1 (supposed XI) was shorted with PIN 3 (supposed XO) - so it seemed that there's a wrong description. Soldered it anyway - and it still did not work
- based on the findings I've moved it 45 deg because the XI and XO cannot be shorted and... it worked! USB hub is working fine.
Here's the final position of my crytstal, I'll order more and check in 3-4 weeks when they arrive:

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

harbaum, 2025-04-26:
Ok ... wasn't aware that you soldered the board yourself. I thought you got it fully assembled and I thus wasn't expecting the crystal to be the problem.

If you like to improve your soldering skills: The next variant may have the rp2040 directly on the PCB, hopefully underneath the Tang Nano 20k and thus allowing the board to be smaller. I like small devices ...

harbaum, 2025-04-26:
BTW: You have a Pico-W, so you should now be able to go online with your setup

luciust, 2025-04-26:
I saw the updated release, and I'm gonna test the online ASAP :)

Well, here I was able to resolder the crystal 6 times - so it was great for getting the skill of fixing SMD in tight spacer. Thanks!

vossstef, 2025-04-27:
have a look in the c64 readme how to usevthe wifi modem.  I tried to document the steps.

luciust, 2025-04-28:
> have a look in the c64 readme how to usevthe wifi modem. I tried to document the steps.

Yay, it works! Steps were clear athelp did the job. I'm ONLINE for the first time using Atari ST!

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

Closed 2025-04-26.

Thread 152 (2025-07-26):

S2 Menu Button + F12 + Keystrokes not recognized

Mangerrione, 2025-07-26:
Have set up my new TN20K following the instructions.
Latest core and latest companion.
Everything went well.
The C64 Nano boots into DolphinDOS.
The first LED is on.
But the S2 Menu Button + F12 + Keystrokes are not recognized
What could possibly be wrong?

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

vossstef, 2025-07-26:
@Mangerrione , it looks that you want to go for internal BL616 µC isn't it ?.
Did you installed the latest Companion firmware for TN20k?
Do you have a TN20K 3921 board variant ?

If you connect to PC USB does it register as a new USB device and **Bouffalo CDC DEMO** ?
If so then you have an older unfused variant and better read this : https://github.com/harbaum/FPGA-Companion/issues/79

Mangerrione, 2025-07-26:
Thank you for your reply!
Yes i'd like to try out the onboard MCU. Would like to have a really tiny C64!
Have flashed the latest C64 Nano core + the DOS files and then the latest Companion.
Everything finished successful.
The board is v3821 yes! Got it yesterday form China...
When i connect it to the PC i can hear the "klang" but nothing else...
It shows up as USB Debugger. Is that a good sign?
If the S2 button for menu does not work it means the FPGA-Companion isn't working?
I have flashed everything back and forth 3 times...

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

Closed 2025-07-27.

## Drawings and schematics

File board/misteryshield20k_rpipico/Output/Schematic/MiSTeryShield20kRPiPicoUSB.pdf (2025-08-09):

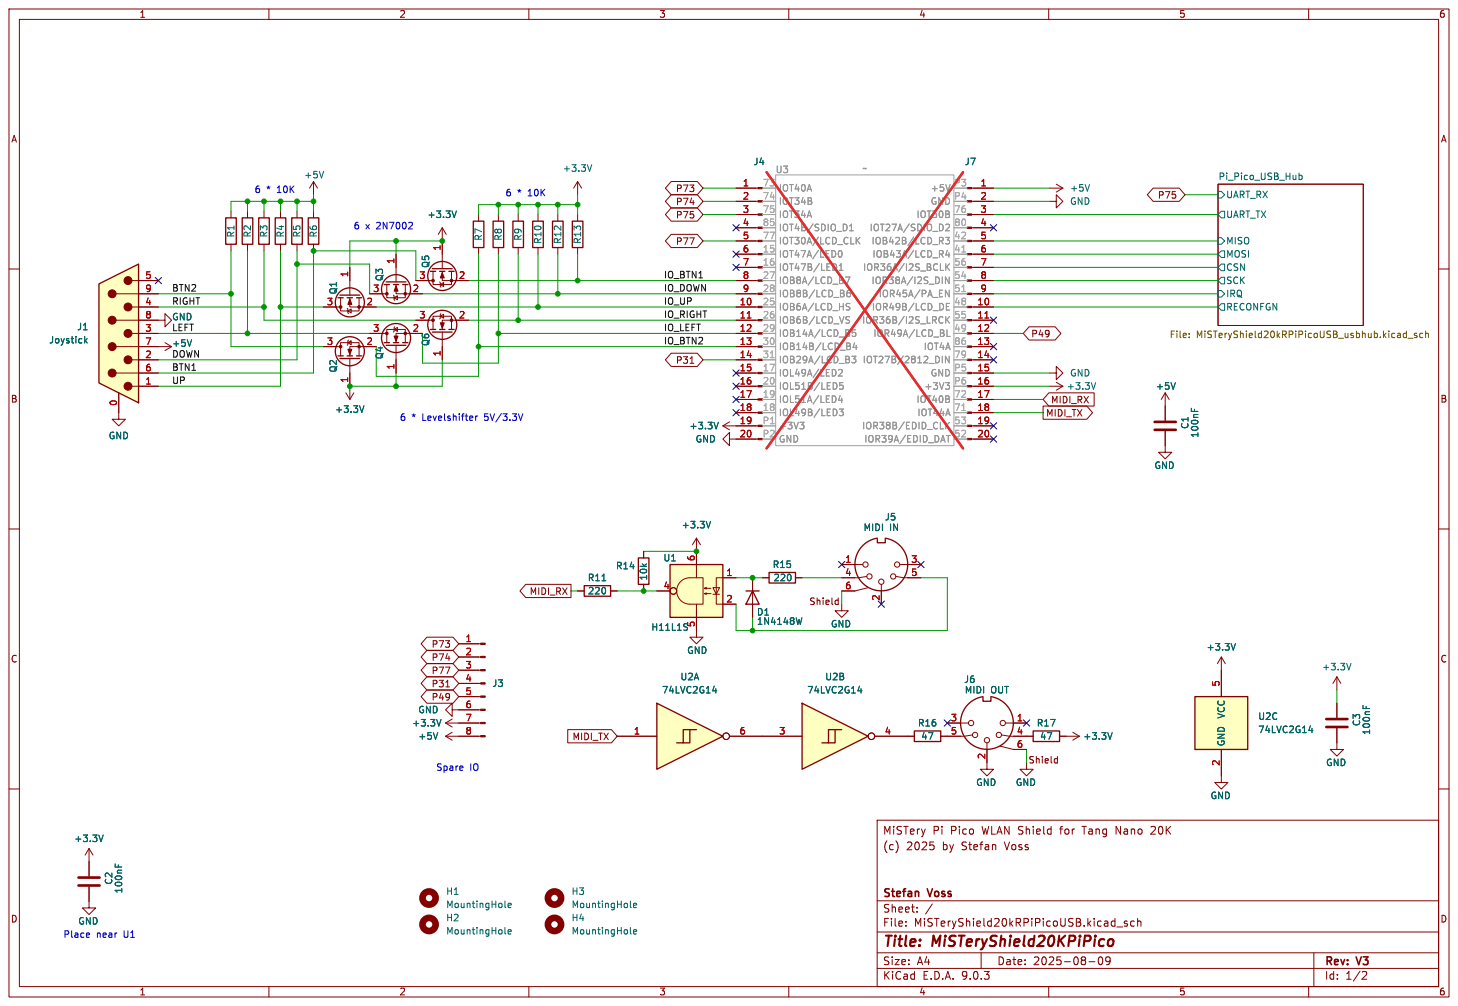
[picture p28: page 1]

UART_RX MOSI SCK CSN MISO
UART_TX RECONFGN

File: MiSTeryShield20kRPiPicoUSB.kicad_sch Sheet: / Stefan Voss

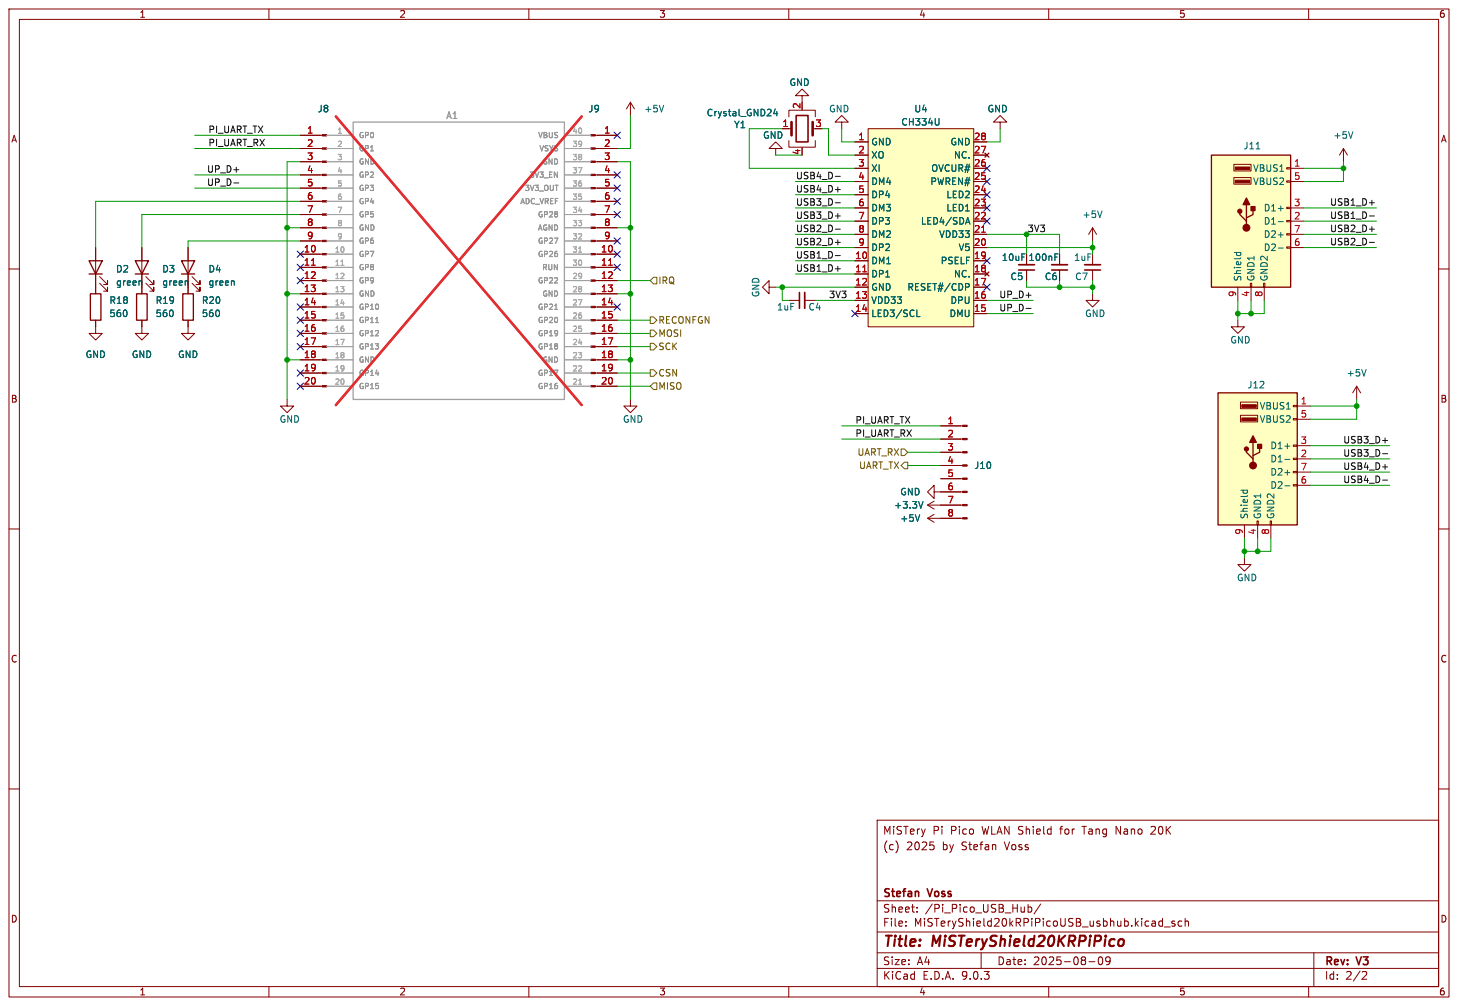
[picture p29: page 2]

File: MiSTeryShield20kRPiPicoUSB_usbhub.kicad_sch Sheet: /Pi_Pico_USB_Hub/ Stefan Voss

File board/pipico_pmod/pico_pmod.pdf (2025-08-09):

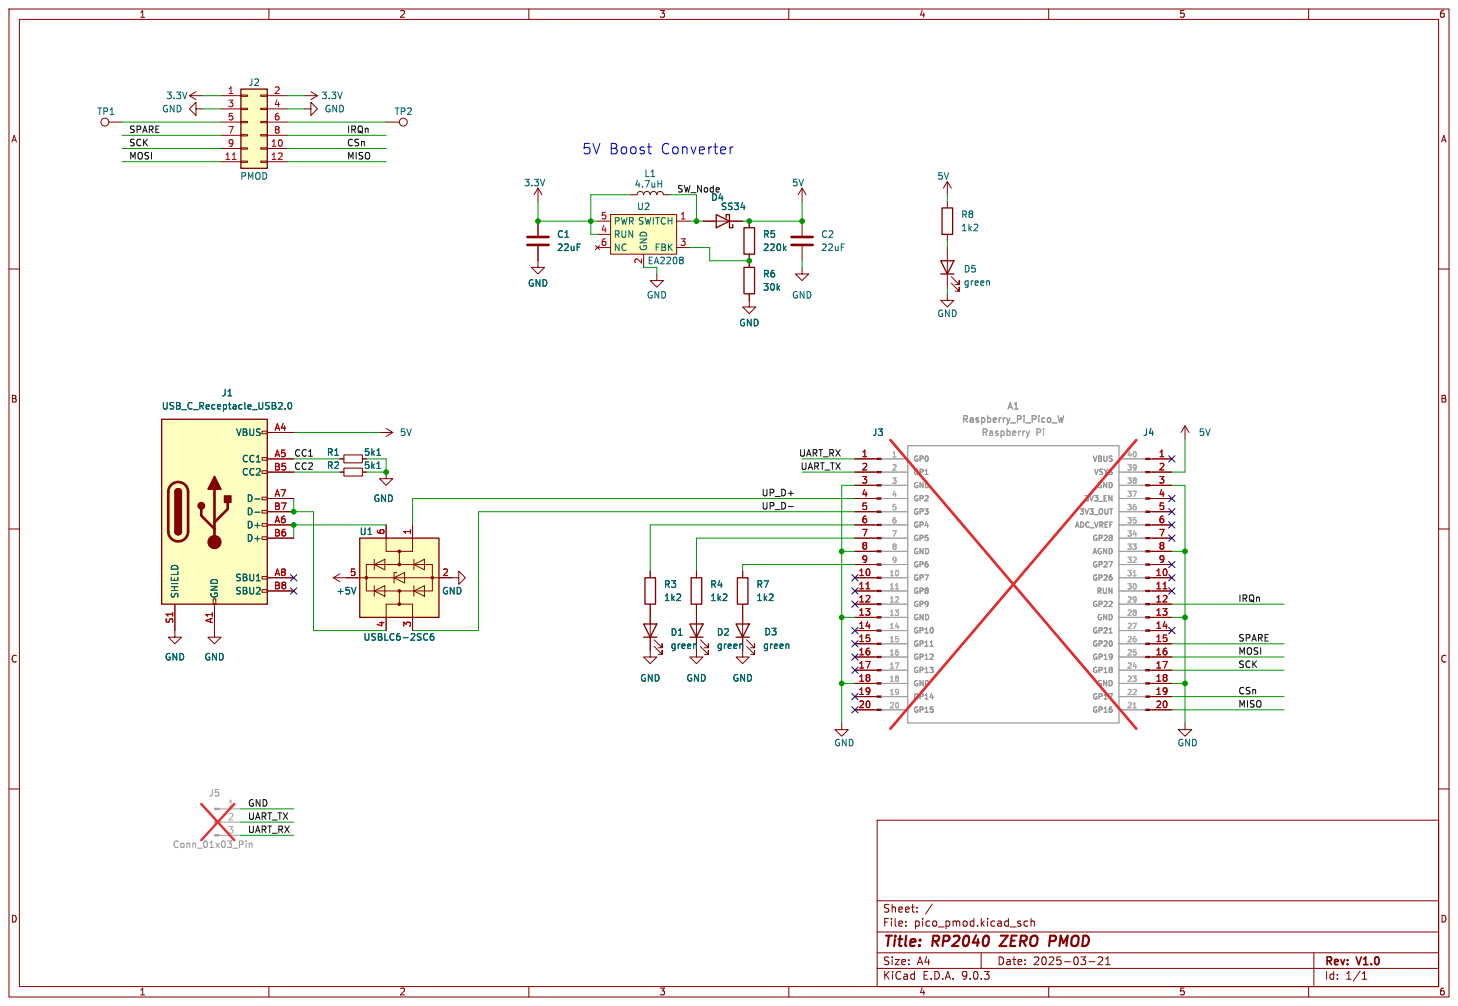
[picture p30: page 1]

3 U1USBLC6-2SC6 GND GND GND GND SHIELD S1 GND A1 VBUS A4 CC1 A5 CC2 B5 D- A7 D- B7 D+ A6 D+ B6 SBU1 A8 SBU2 B8

File: pico_pmod.kicad_sch Sheet: /
Id: 1/1 Title: RP2040 ZERO PMOD

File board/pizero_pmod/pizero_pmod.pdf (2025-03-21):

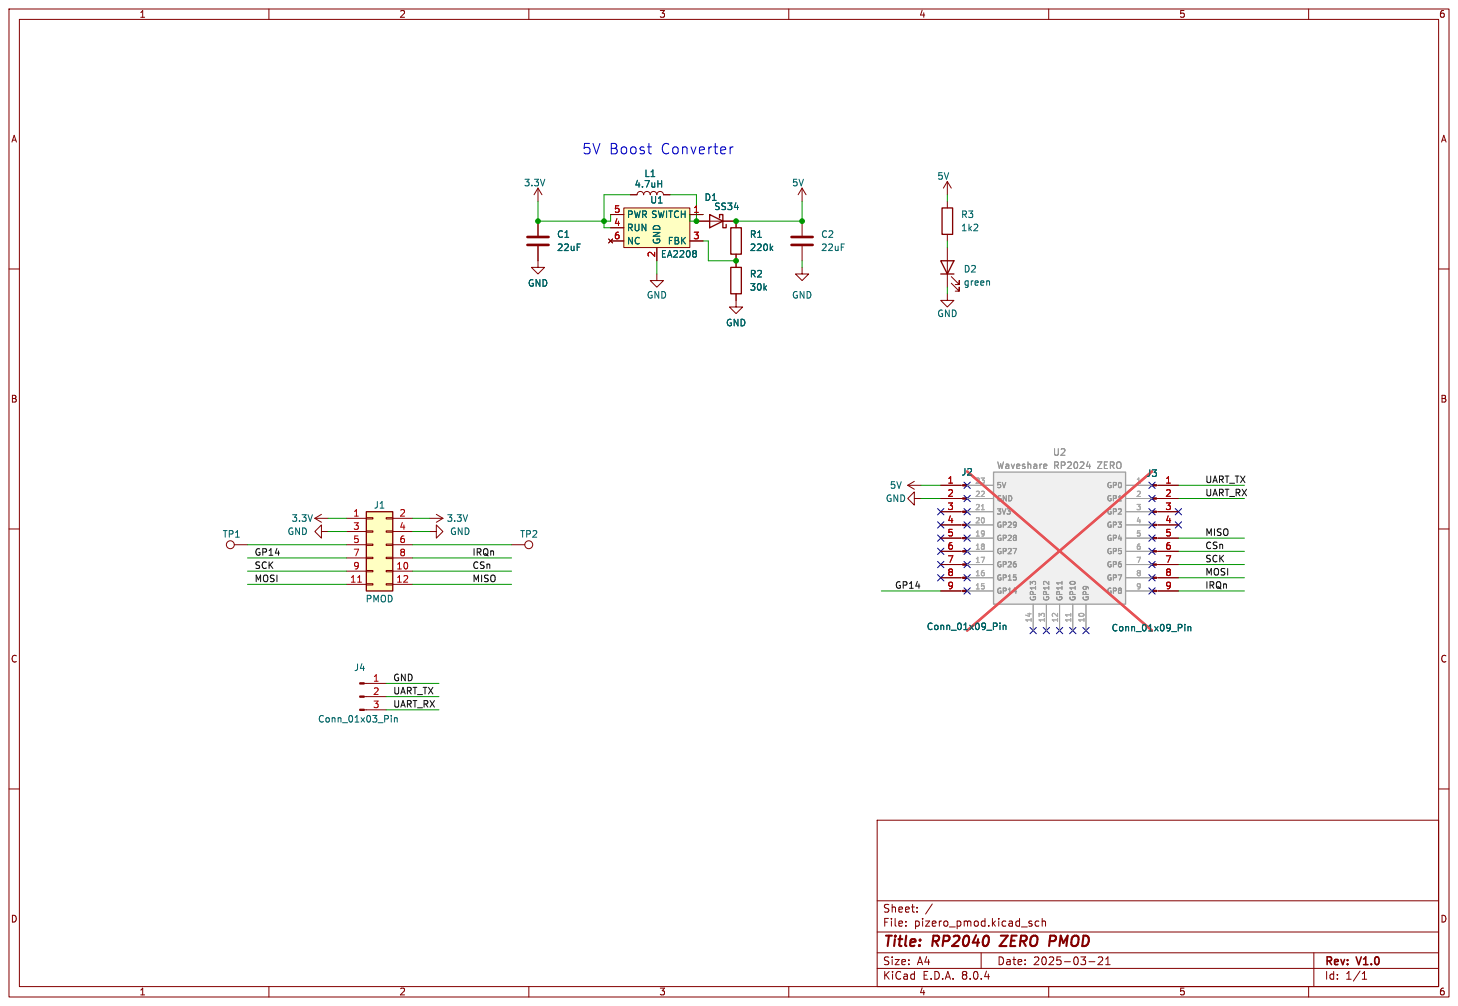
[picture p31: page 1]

2 FBK 3 RUN 4 PWR 5 NC 6 U1EA2208

2 FBK 3 RUN 4 PWR 5 NC 6

File: pizero_pmod.kicad_sch Sheet: /
Id: 1/1 Title: RP2040 ZERO PMOD

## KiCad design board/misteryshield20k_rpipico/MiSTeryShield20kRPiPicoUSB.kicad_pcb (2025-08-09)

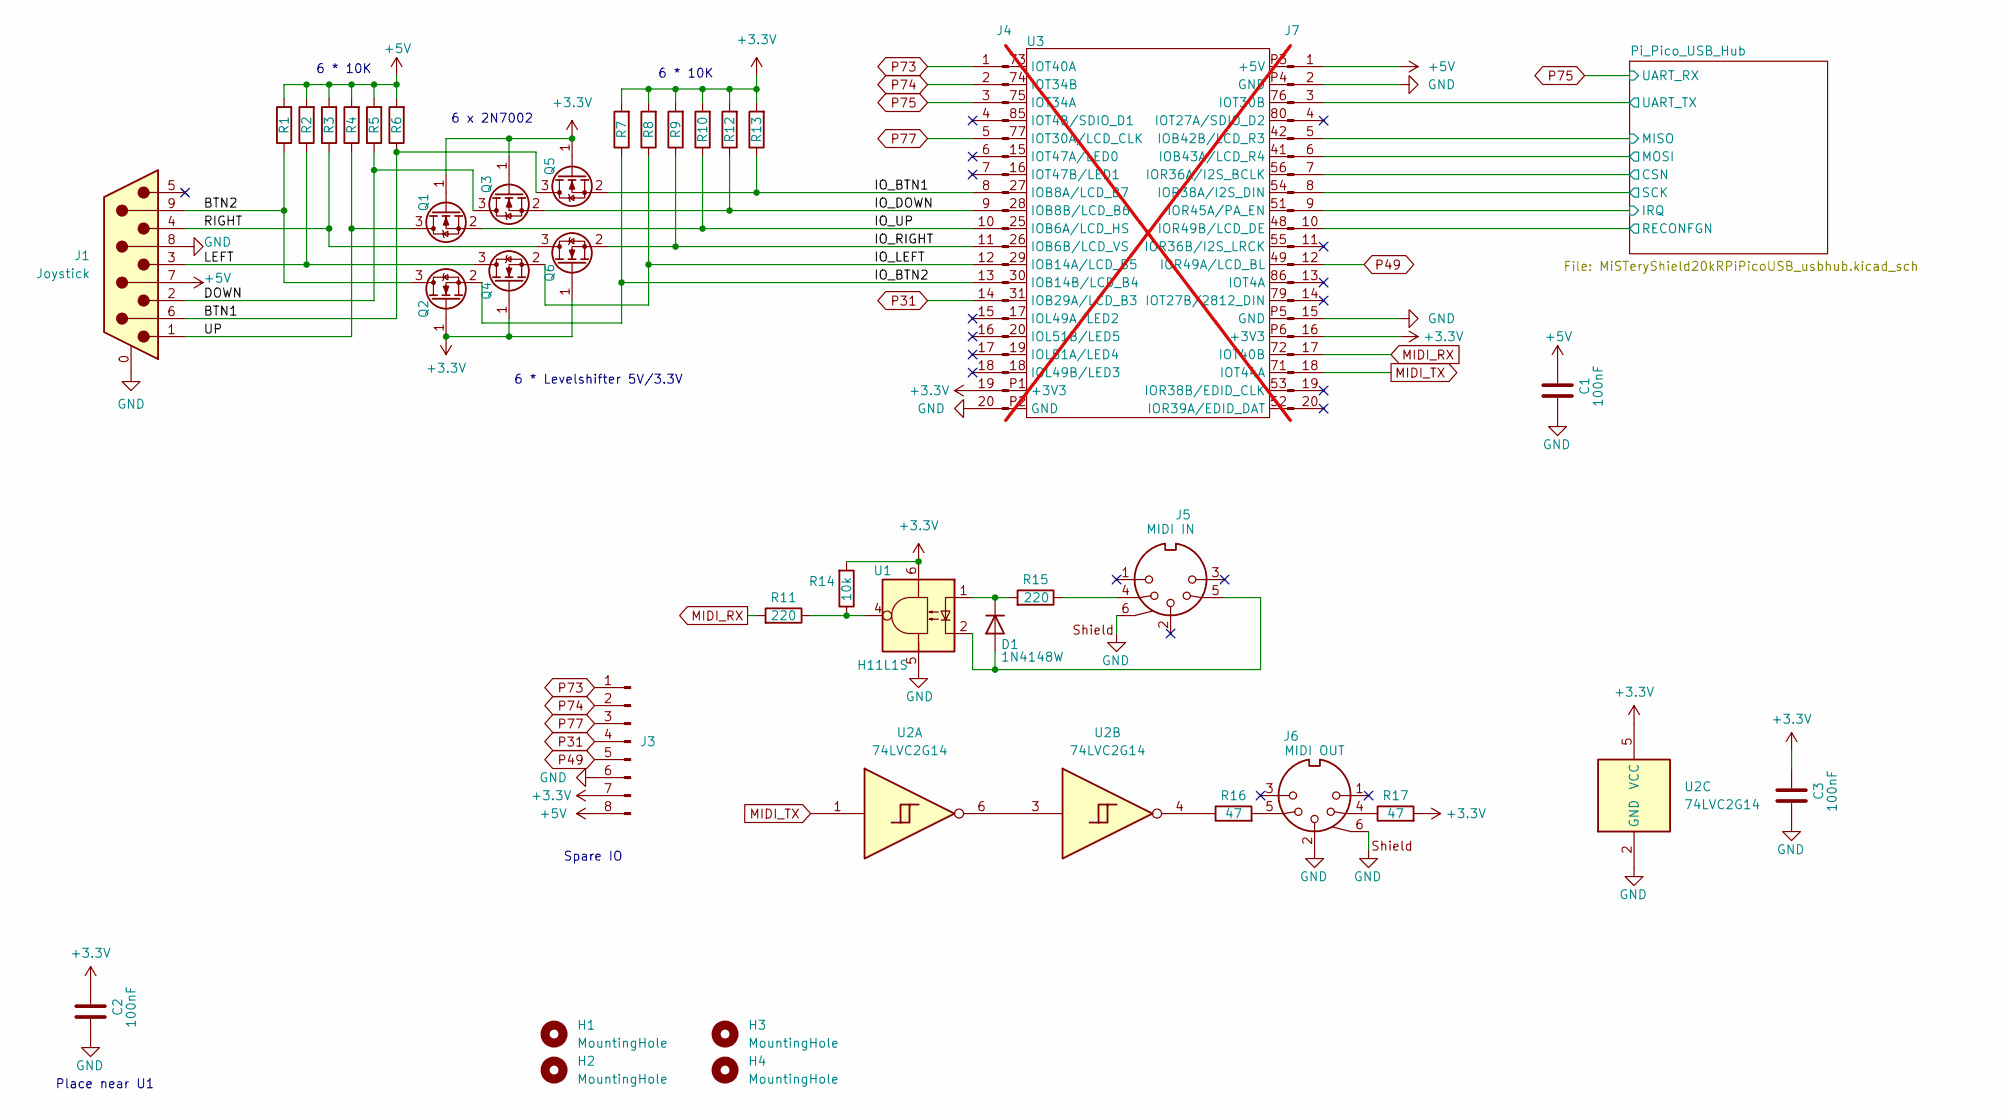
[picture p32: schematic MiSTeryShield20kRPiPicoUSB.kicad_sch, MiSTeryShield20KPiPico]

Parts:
C1, C2, C3: 100nF; C_0805_2012Metric; LCSC Part # C49678
D1: 1N4148W; D_SOD-123; LCSC Part # C81598
H1, H2, H3, H4: MountingHole; MountingHole_3.2mm_M3
J1: Joystick; DSUB-9_Male_Horizontal_P2.77x2.84mm_EdgePinOffset7.70mm_Hou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; LCSC Part # C141880
J3: Conn_02x04_Pin; PinHeader_2x04_P2.54mm_Vertical; LCSC Part # C7501275
J4, J7: Conn_01x20_Pin; PinSocket_1x20_P2.54mm_Vertical; LCSC Part # C18078139
J5: MIDI IN; DIN-5_180degree; LCSC Part # C2939346
J6: MIDI OUT; DIN-5_180degree; LCSC Part # C2939346
Q1, Q2, Q3, Q4, Q5, Q6: 2N7002; SOT-23; LCSC Part # C8545
R1, R2, R3, R4, R5, R6, R7, R8, R9, R10, R12, R13, R14: 10k; R_0805_2012Metric; LCSC Part # C17414
R11, R15: 220; R_0805_2012Metric; LCSC Part # C17557
R16, R17: 47; R_0805_2012Metric; LCSC Part # C17714
U1: H11L1S; SMDIP-6_W9.53mm; LCSC Part # C78589
U2: 74LVC2G14; SOT-23-6; LCSC Part # C5375976
U3: TangNano-20K; not fitted

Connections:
+3.3V: C2.2, C3.2, J3.7, J4.19, J7.16, Q1.1 (G), Q2.1 (G), Q3.1 (G), Q4.1 (G), Q5.1 (G), Q6.1 (G), R7.2, R8.2, R9.2, R10.2, R12.2, R13.2, R14.2, R17.2, U1.6, U2.5 (VCC); also elsewhere on the board
+5V: C1.2, J1.7, J3.8, J7.1, R1.2, R2.2, R3.2, R4.2, R5.2, R6.2; also elsewhere on the board
/BTN1: J1.6, Q5.3 (D), R6.1
/BTN2: J1.9, Q2.3 (D), R1.1
/DOWN: J1.2, Q3.3 (D), R5.1
/IO_BTN1: J4.8, Q5.2 (S), R13.1
/IO_BTN2: J4.13, Q2.2 (S), R7.1
/IO_DOWN: J4.9, Q3.2 (S), R12.1
/IO_LEFT: J4.12, Q4.2 (S), R8.1
/IO_RIGHT: J4.11, Q6.2 (S), R9.1
/IO_UP: J4.10, Q1.2 (S), R10.1
/LEFT: J1.3, Q4.3 (D), R2.1
/Pi_Pico_USB_Hub/CSN: J7.7; also elsewhere on the board
/Pi_Pico_USB_Hub/IRQ: J7.9; also elsewhere on the board
/Pi_Pico_USB_Hub/MISO: J7.5; also elsewhere on the board
/Pi_Pico_USB_Hub/MOSI: J7.6; also elsewhere on the board
/Pi_Pico_USB_Hub/RECONFGN: J7.10; also elsewhere on the board
/Pi_Pico_USB_Hub/SCK: J7.8; also elsewhere on the board
/Pi_Pico_USB_Hub/UART_TX: J7.3; also elsewhere on the board
/RIGHT: J1.4, Q6.3 (D), R3.1
/UP: J1.1, Q1.3 (D), R4.1
GND: C1.1, C2.1, C3.1, J1.0 (PAD), J1.8, J3.6, J4.20, J5.6, J6.2, J6.6, J7.2, J7.15, U1.5, U2.2 (GND); also elsewhere on the board
MIDI_RX: J7.17, R11.2
MIDI_TX: J7.18, U2.1
unnamed: D1.2 (A), J5.5, U1.2
unnamed: D1.1 (K), R15.2, U1.1
unnamed: J5.4, R15.1
unnamed: J6.4, R17.1
unnamed: J6.5, R16.2
unnamed: R11.1, R14.1, U1.4
unnamed: R16.1, U2.4
unnamed: U2.3, U2.6
P31: J3.4, J4.14
P49: J3.5, J7.12
P73: J3.1, J4.1
P74: J3.2, J4.2
P75: J4.3; also elsewhere on the board
P77: J3.3, J4.5

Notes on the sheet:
6 * Levelshifter 5V/3.3V
Spare IO
Place near U1
6 * 10K
6 x 2N7002

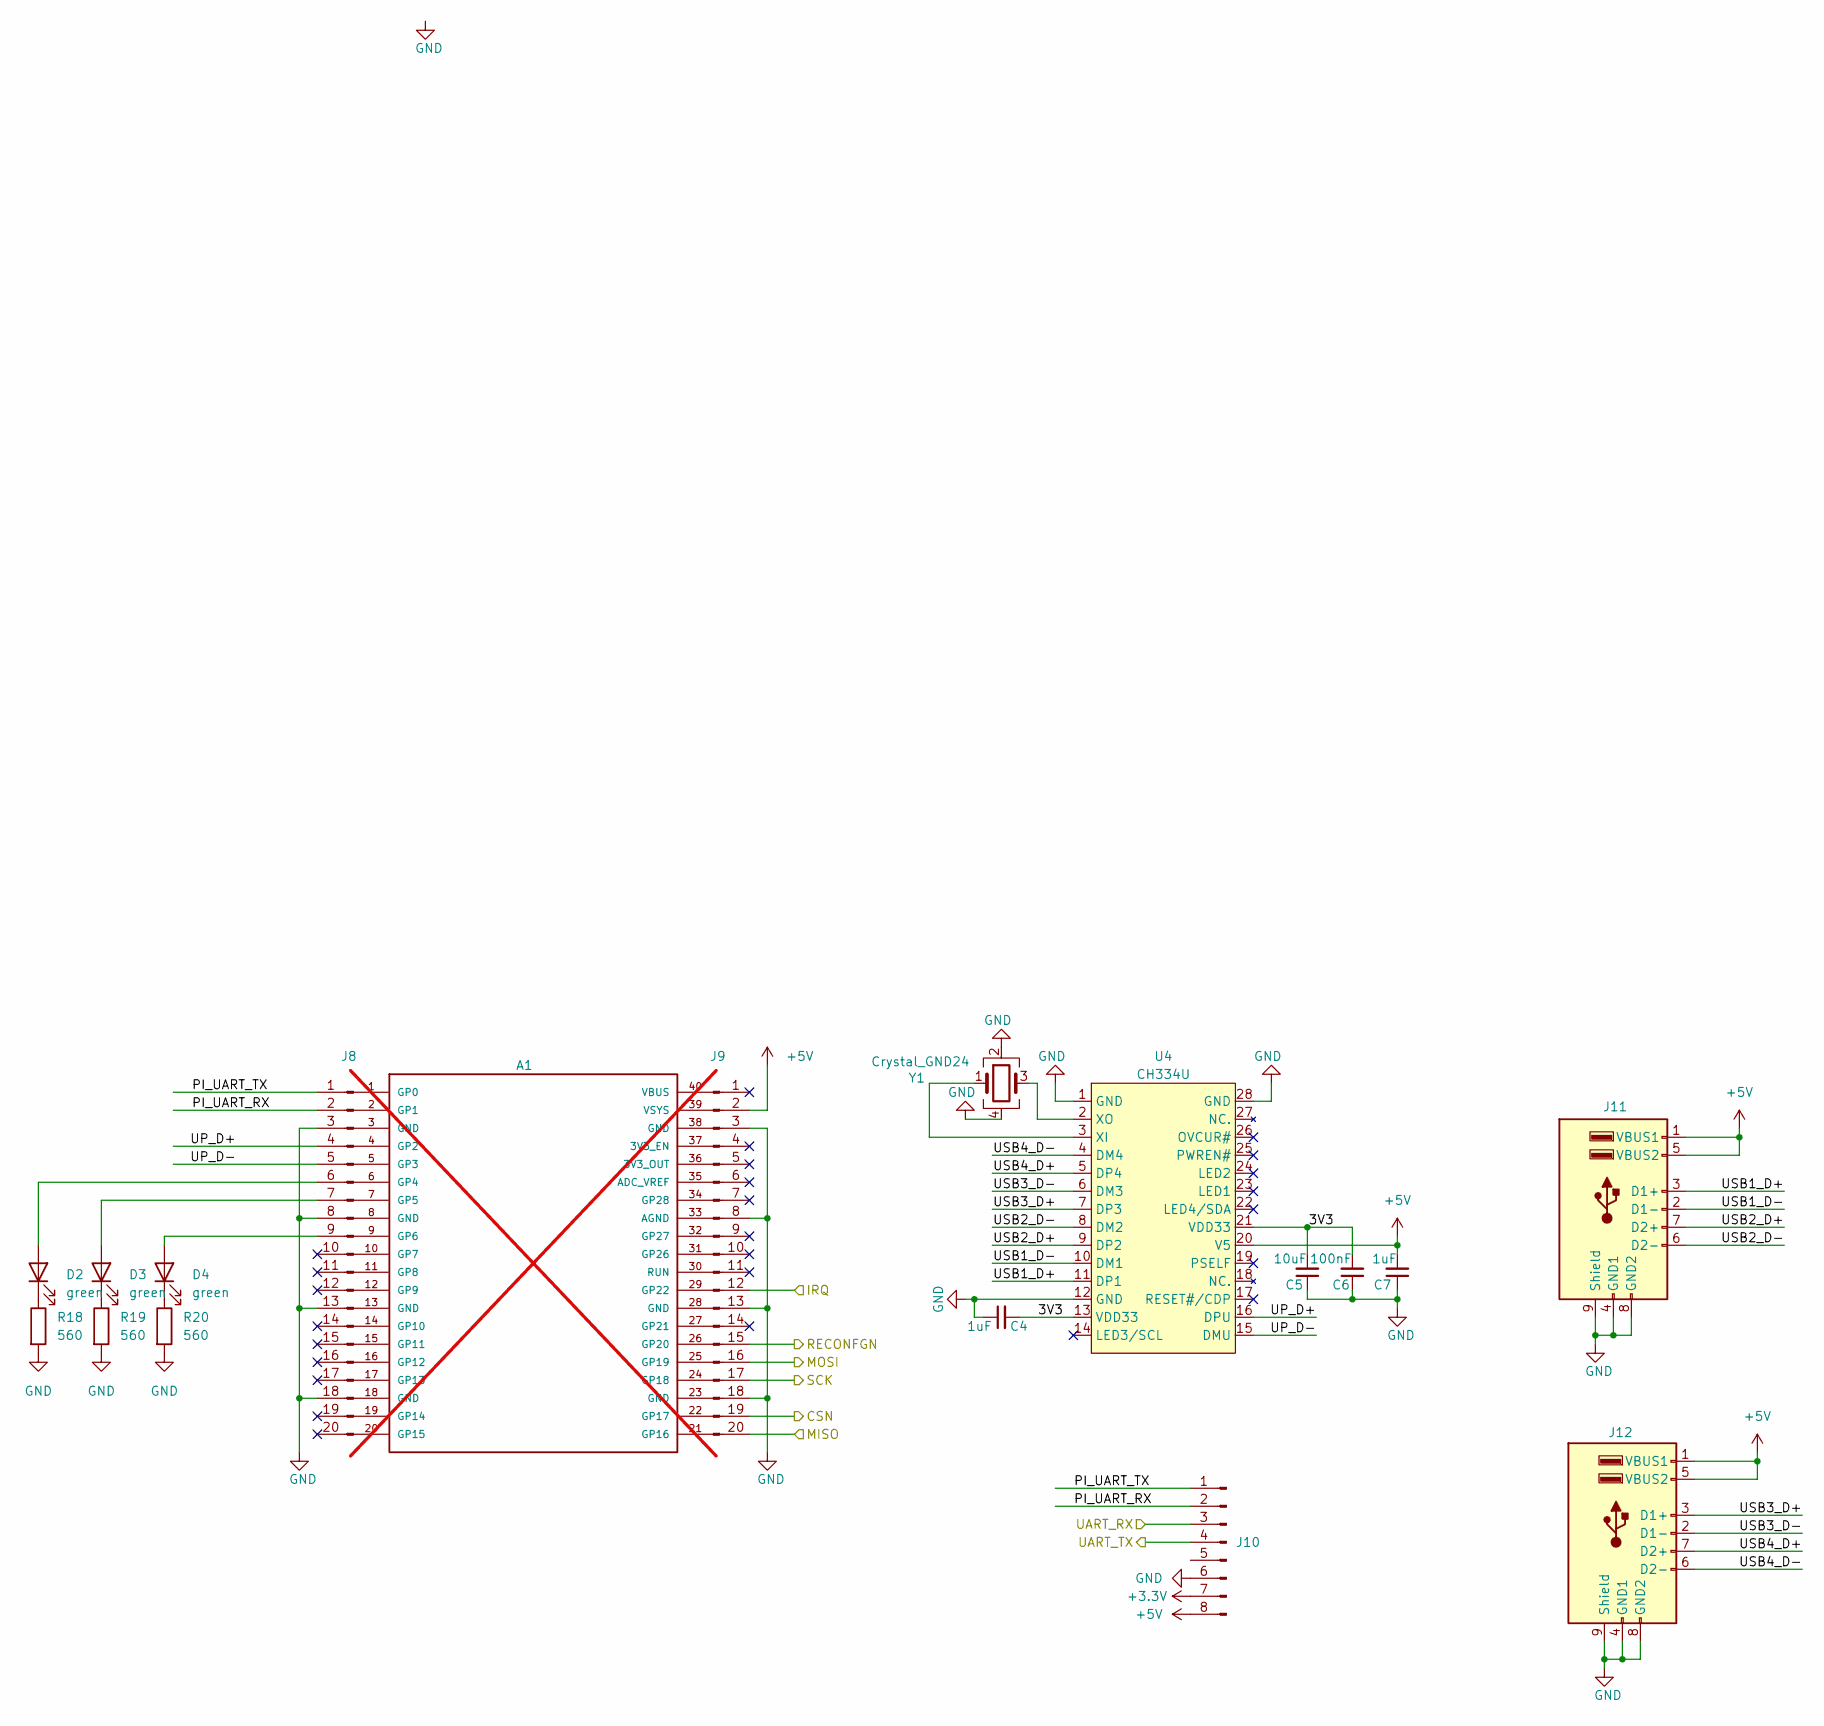
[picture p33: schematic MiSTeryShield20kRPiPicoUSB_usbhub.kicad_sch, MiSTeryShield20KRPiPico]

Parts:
A1: Raspberry_Pi_Pico_W; not fitted
C4, C7: 1uF; C_0805_2012Metric; LCSC Part # C28323
C5: 10uF; C_0805_2012Metric; LCSC Part # C15850
C6: 100nF; C_0805_2012Metric; LCSC Part # C49678
D2, D3, D4: green; LED_0805_2012Metric; LCSC Part # C2297
J8, J9: Conn_01x20_Pin; PinSocket_1x20_P2.54mm_Vertical; LCSC Part # C18078139
J10: Conn_02x04_Pin; PinHeader_2x04_P2.54mm_Vertical; LCSC Part # C7501275
J11, J12: USB_A_Stacked; USB_A_Wuerth_61400826021_Horizontal_Stacked; LCSC Part # C456021
R18, R19, R20: 560; R_0805_2012Metric; LCSC Part # C28636
U4: CH334U; SSOP-28_3.9x9.9mm_P0.635mm; LCSC Part # C5187524
Y1: Crystal_GND24; Crystal_SMD_3225-4Pin_3.2x2.5mm; LCSC Part # C9002

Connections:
+3.3V: J10.7; also elsewhere on the board
+5V: C7.2, J9.2, J10.8, J11.1 (VBUS1), J11.5 (VBUS2), J12.1 (VBUS1), J12.5 (VBUS2), U4.20 (V5); also elsewhere on the board
/Pi_Pico_USB_Hub/3V3: C4.2, C5.2, C6.2, U4.13 (VDD33), U4.21 (VDD33)
/Pi_Pico_USB_Hub/CSN: J9.19; also elsewhere on the board
/Pi_Pico_USB_Hub/IRQ: J9.12; also elsewhere on the board
/Pi_Pico_USB_Hub/MISO: J9.20; also elsewhere on the board
/Pi_Pico_USB_Hub/MOSI: J9.16; also elsewhere on the board
/Pi_Pico_USB_Hub/PI_UART_RX: J8.2, J10.2
/Pi_Pico_USB_Hub/PI_UART_TX: J8.1, J10.1
/Pi_Pico_USB_Hub/RECONFGN: J9.15; also elsewhere on the board
/Pi_Pico_USB_Hub/SCK: J9.17; also elsewhere on the board
/Pi_Pico_USB_Hub/UART_TX: J10.4; also elsewhere on the board
/Pi_Pico_USB_Hub/UP_D+: J8.4, U4.16 (DPU)
/Pi_Pico_USB_Hub/UP_D-: J8.5, U4.15 (DMU)
/Pi_Pico_USB_Hub/USB1_D+: J11.3 (D1+), U4.11 (DP1)
/Pi_Pico_USB_Hub/USB1_D-: J11.2 (D1-), U4.10 (DM1)
/Pi_Pico_USB_Hub/USB2_D+: J11.7 (D2+), U4.9 (DP2)
/Pi_Pico_USB_Hub/USB2_D-: J11.6 (D2-), U4.8 (DM2)
/Pi_Pico_USB_Hub/USB3_D+: J12.3 (D1+), U4.7 (DP3)
/Pi_Pico_USB_Hub/USB3_D-: J12.2 (D1-), U4.6 (DM3)
/Pi_Pico_USB_Hub/USB4_D+: J12.7 (D2+), U4.5 (DP4)
/Pi_Pico_USB_Hub/USB4_D-: J12.6 (D2-), U4.4 (DM4)
GND: C4.1, C5.1, C6.1, C7.1, J8.3, J8.8, J8.13, J8.18, J9.3, J9.8, J9.13, J9.18, J10.6, J11.4 (GND1), J11.8 (GND2), J11.9 (Shield), J12.4 (GND1), J12.8 (GND2), J12.9 (Shield), R18.2, R19.2, R20.2, U4.1 (GND), U4.12 (GND), U4.28 (GND), Y1.2, Y1.4; also elsewhere on the board
unnamed: D2.2 (A), J8.6
unnamed: D2.1 (K), R18.1
unnamed: D3.2 (A), J8.7
unnamed: D3.1 (K), R19.1
unnamed: D4.2 (A), J8.9
unnamed: D4.1 (K), R20.1
unnamed: U4.3 (XI), Y1.1
unnamed: U4.2 (XO), Y1.3
P75: J10.3; also elsewhere on the board

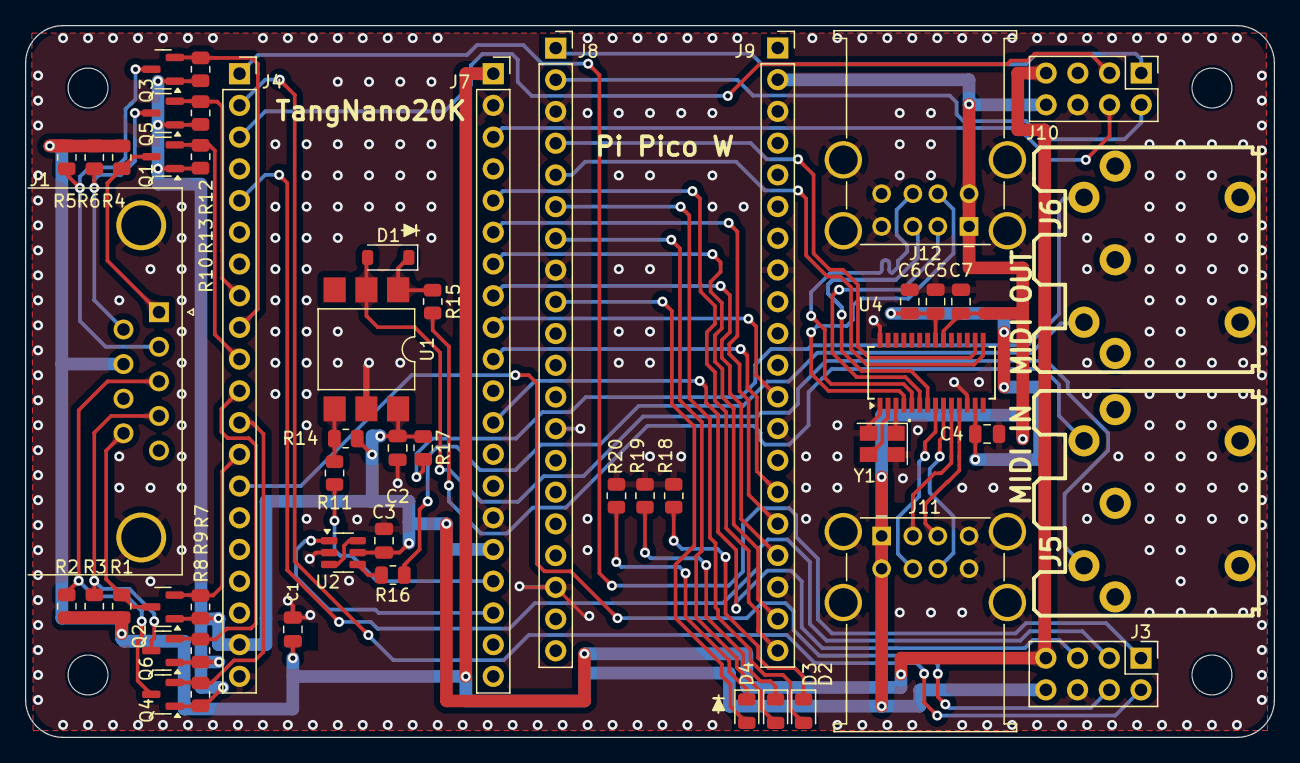
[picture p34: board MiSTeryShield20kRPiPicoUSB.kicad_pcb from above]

Board: 2 copper layers, 100.0 x 57.0 mm, 56 parts (0 on the bottom side), 59 nets.

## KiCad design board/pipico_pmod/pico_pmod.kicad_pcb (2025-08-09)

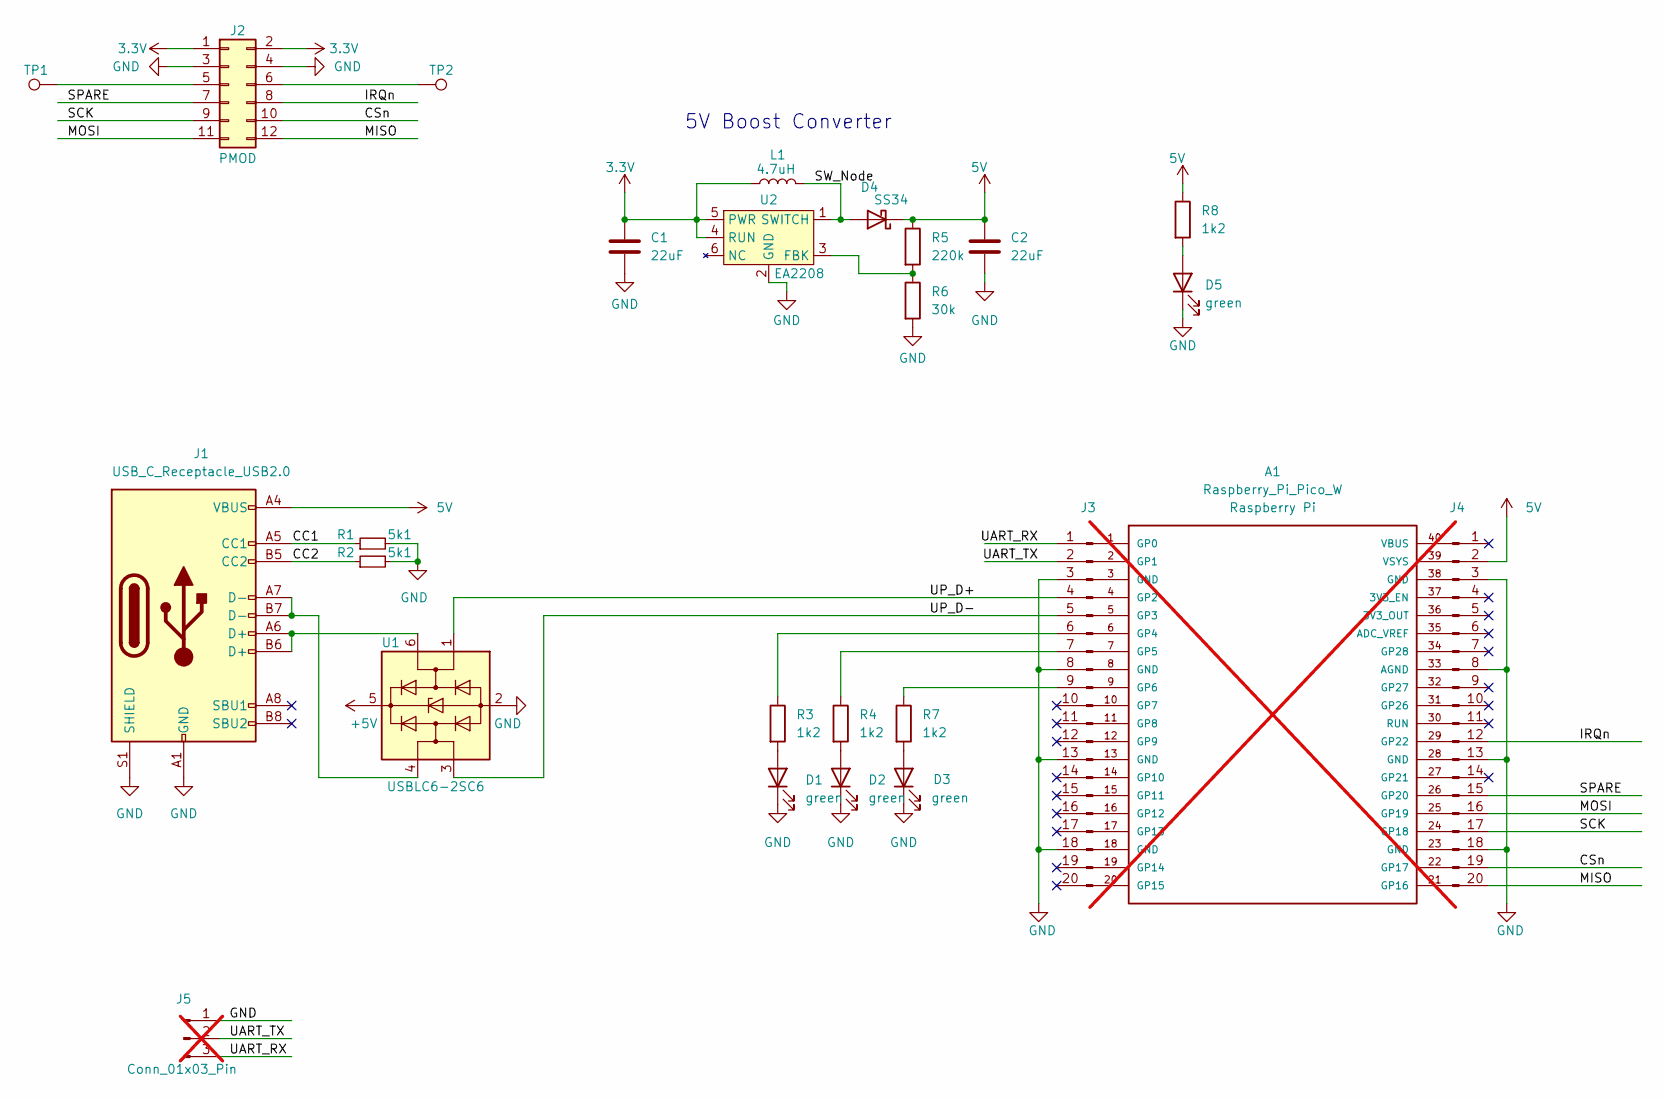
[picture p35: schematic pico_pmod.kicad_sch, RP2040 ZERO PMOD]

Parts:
A1: Raspberry_Pi_Pico_W; not fitted
C1, C2: 22uF; C_1206_3216Metric; LCSC Part # C12891
D1, D2, D3, D5: green; LED_0805_2012Metric; LCSC Part # C2297
D4: SS34; D_SMA; LCSC Part # C8678
J1: USB_C_Receptacle_USB2.0; USB_C_Receptacle_HRO_TYPE-C-31-M-12; LCSC C165948
J2: PMOD; PinHeader_2x06_P2.54mm_Horizontal; JLCPCB Position Offset -6.35,-1.5
J3, J4: Conn_01x20_Pin; PinSocket_1x20_P2.54mm_Vertical; LCSC Part # C18078139
J5: Conn_01x03_Pin; PinHeader_1x03_P2.54mm_Vertical; LCSC Part # C2932698; not fitted
L1: 4.7uH; L_6.3x6.3_H3; LCSC Part # C142106
R1, R2: 5k1; R_0402_1005Metric; LCSC C25905
R3, R4, R7, R8: 1k2; R_0805_2012Metric; LCSC Part # C17379
R5: 220k; R_0805_2012Metric; LCSC Part # C17556
R6: 30k; R_0805_2012Metric; LCSC Part # C17621
TP1, TP2: TestPoint; TestPoint_Pad_D1.5mm
U1: USBLC6-2SC6; SOT-23-6; LCSC C2827654
U2: EA2208; SOT-23-6; LCSC Part # C22462489

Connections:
3.3V: C1.1, J2.1, J2.2, L1.1, U2.4 (RUN), U2.5 (PWR)
5V: C2.1, D4.1 (K), J1.A4 (VBUS), J1.A9 (VBUS), J1.B4 (VBUS), J1.B9 (VBUS), J4.2, R5.1, R8.1
+5V: U1.5 (VBUS)
/CC1: J1.A5 (CC1), R1.1
/CC2: J1.B5 (CC2), R2.1
/CSn: J2.10, J4.19
/IRQn: J2.8, J4.12
/MISO: J2.12, J4.20
/MOSI: J2.11, J4.16
/SCK: J2.9, J4.17
/SPARE: J2.7, J4.15
/SW_Node: D4.2 (A), L1.2, U2.1 (SWITCH)
/UART_RX: J3.1, J5.3
/UART_TX: J3.2, J5.2
/UP_D+: J3.4, U1.1 (I/O1)
/UP_D-: J3.5, U1.3 (I/O2)
GND: C1.2, C2.2, D1.1 (K), D2.1 (K), D3.1 (K), D5.1 (K), J1.A1 (GND), J1.A12 (GND), J1.B1 (GND), J1.B12 (GND), J1.S1 (SHIELD), J2.3, J2.4, J3.3, J3.8, J3.13, J3.18, J4.3, J4.8, J4.13, J4.18, J5.1, R1.2, R2.2, R6.2, U1.2 (GND), U2.2 (GND)
unnamed: D1.2 (A), R3.2
unnamed: D2.2 (A), R4.2
unnamed: D3.2 (A), R7.2
unnamed: D5.2 (A), R8.2
unnamed: J1.A6 (D+), J1.B6 (D+), U1.6 (I/O1)
unnamed: J1.A7 (D-), J1.B7 (D-), U1.4 (I/O2)
unnamed: J2.5, TP1.1
unnamed: J2.6, TP2.1
unnamed: J3.6, R3.1
unnamed: J3.7, R4.1
unnamed: J3.9, R7.1
unnamed: R5.2, R6.1, U2.3 (FBK)

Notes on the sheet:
5V Boost Converter

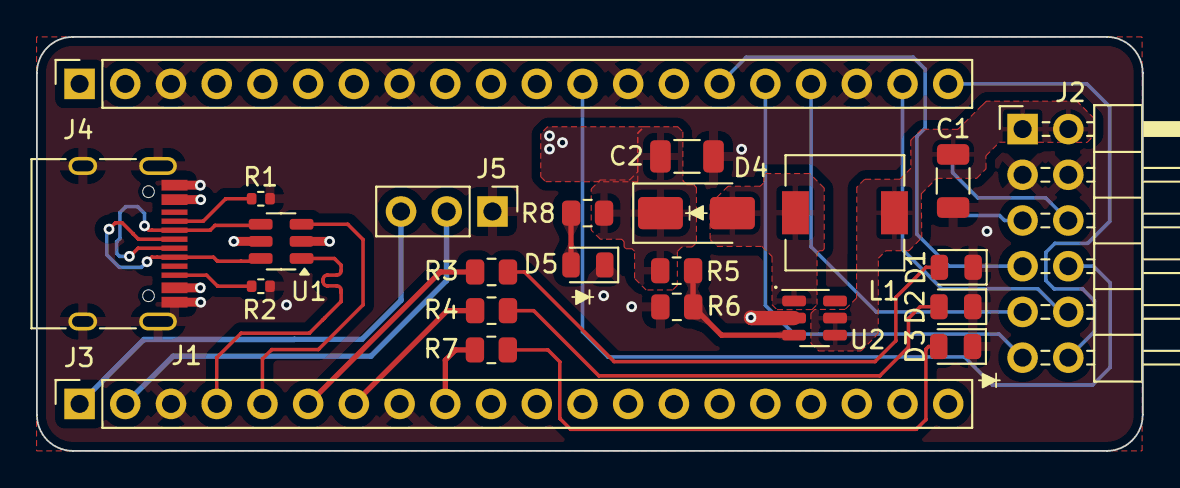
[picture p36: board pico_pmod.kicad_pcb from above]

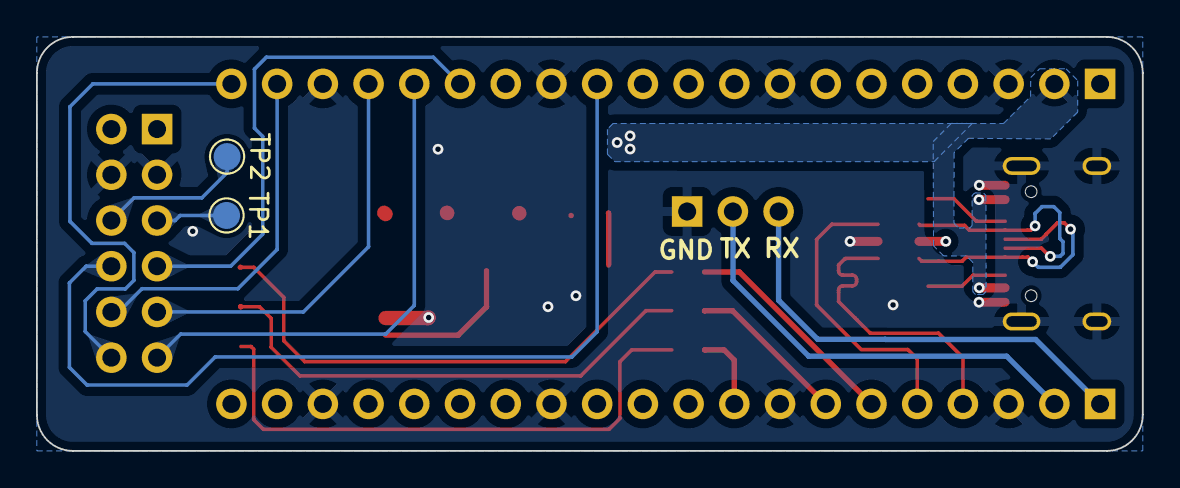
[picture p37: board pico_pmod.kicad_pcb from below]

Board: 2 copper layers, 61.4 x 23.0 mm, 25 parts (2 on the bottom side), 28 nets.

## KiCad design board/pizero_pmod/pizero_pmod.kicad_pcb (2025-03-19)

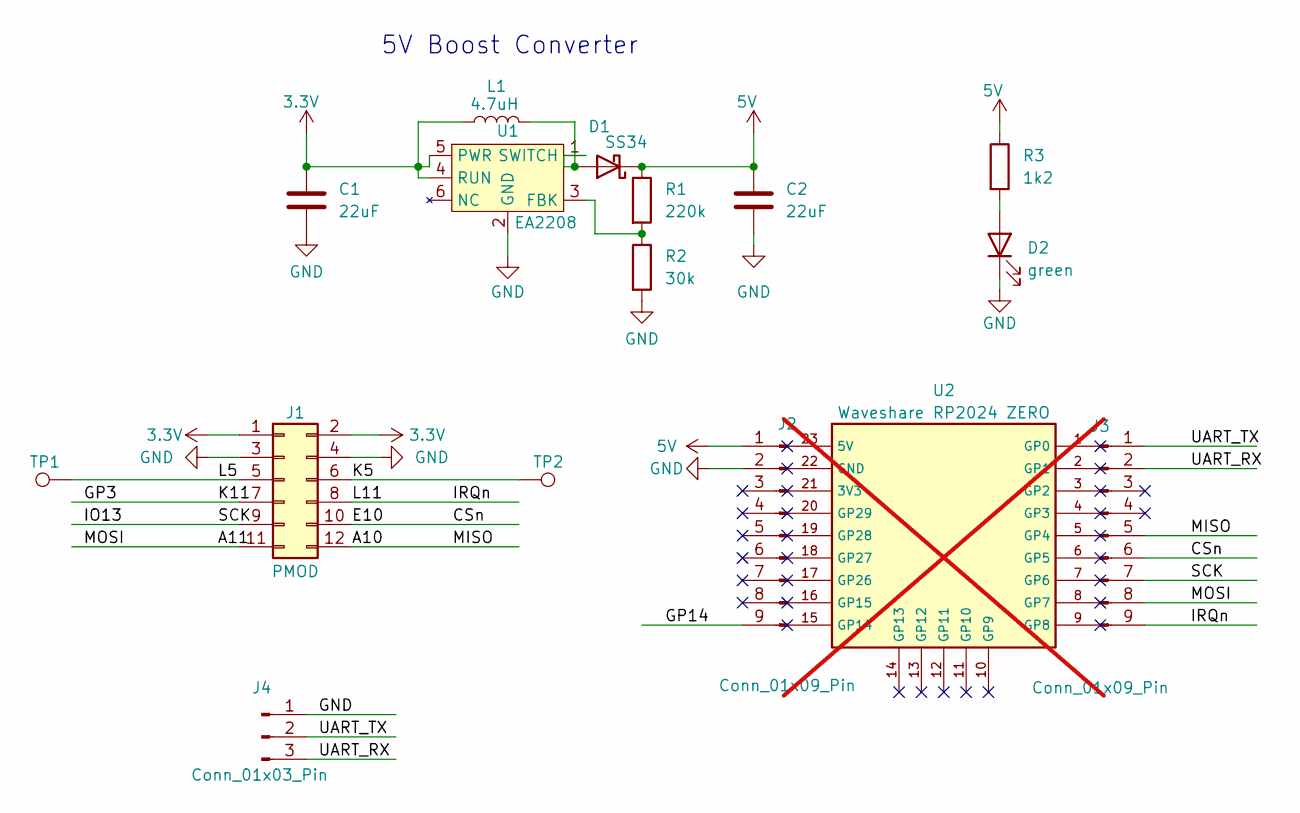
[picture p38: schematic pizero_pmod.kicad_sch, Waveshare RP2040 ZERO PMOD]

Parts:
C1, C2: 22uF; C_1206_3216Metric; LCSC Part # C12891
D1: SS34; D_SMA; LCSC Part # C8678
D2: green; LED_0805_2012Metric; LCSC Part # C2297
J1: PMOD; PinHeader_2x06_P2.54mm_Horizontal; JLCPCB Position Offset -6.35,-1.5
J2, J3: Conn_01x09_Pin; PinHeader_1x09_P2.54mm_Vertical; LCSC Part # C2932701
J4: Conn_01x03_Pin; PinHeader_1x03_P2.54mm_Vertical; LCSC Part # C2932698
L1: 4.7uH; L_6.3x6.3_H3; LCSC Part # C142106
R1: 220k; R_0805_2012Metric; LCSC Part # C17556
R2: 30k; R_0805_2012Metric; LCSC Part # C17621
R3: 1k2; R_0805_2012Metric; LCSC Part # C17379
TP1, TP2: TestPoint; TestPoint_Pad_D1.5mm
U1: EA2208; SOT-23-6; LCSC Part # C22462489
U2: Waveshare RP2024 ZERO; Waveshare-RP2040-ZERO; not fitted

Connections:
3.3V: C1.1, J1.1, J1.2, L1.1, U1.4 (RUN), U1.5 (PWR)
5V: C2.1, D1.1 (K), J2.1, R1.1, R3.1
/A10: J1.12, J3.5
/A11: J1.11, J3.8
/CSn: J1.10, J3.6
/GP3: J1.7
/GP14: J2.9
/IO13: J1.9, J3.7
/IRQn: J1.8, J3.9
/K5: J1.6, TP2.1
/L5: J1.5, TP1.1
/UART_RX: J3.2, J4.3
/UART_TX: J3.1, J4.2
GND: C1.2, C2.2, D2.1 (K), J1.3, J1.4, J2.2, J4.1, R2.2, U1.2 (GND)
unnamed: D1.2 (A), L1.2, U1.1 (SWITCH)
unnamed: D2.2 (A), R3.2
unnamed: R1.2, R2.1, U1.3 (FBK)

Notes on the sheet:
5V Boost Converter

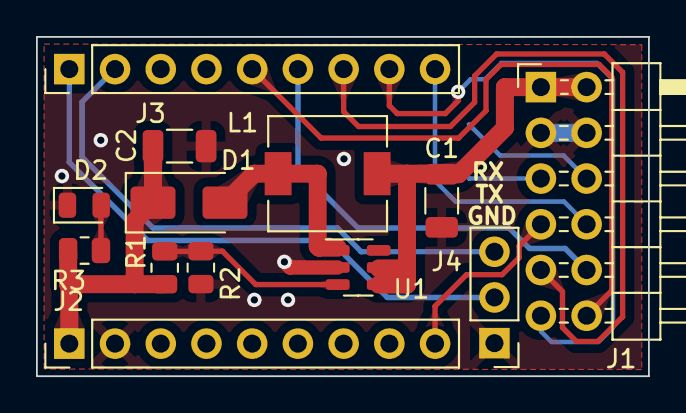
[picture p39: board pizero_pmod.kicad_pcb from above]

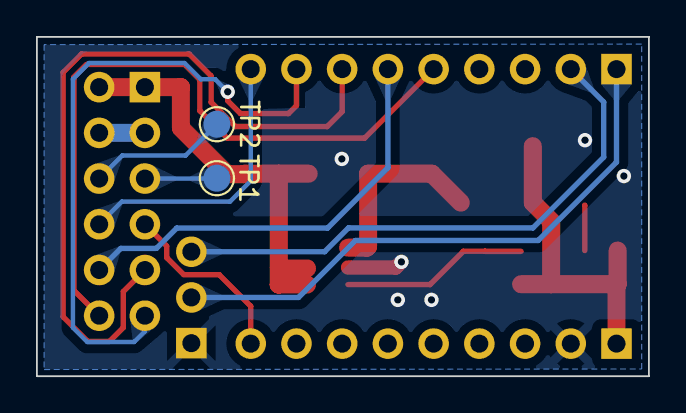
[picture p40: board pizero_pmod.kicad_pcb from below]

Board: 2 copper layers, 34.0 x 18.8 mm, 15 parts (2 on the bottom side), 15 nets.

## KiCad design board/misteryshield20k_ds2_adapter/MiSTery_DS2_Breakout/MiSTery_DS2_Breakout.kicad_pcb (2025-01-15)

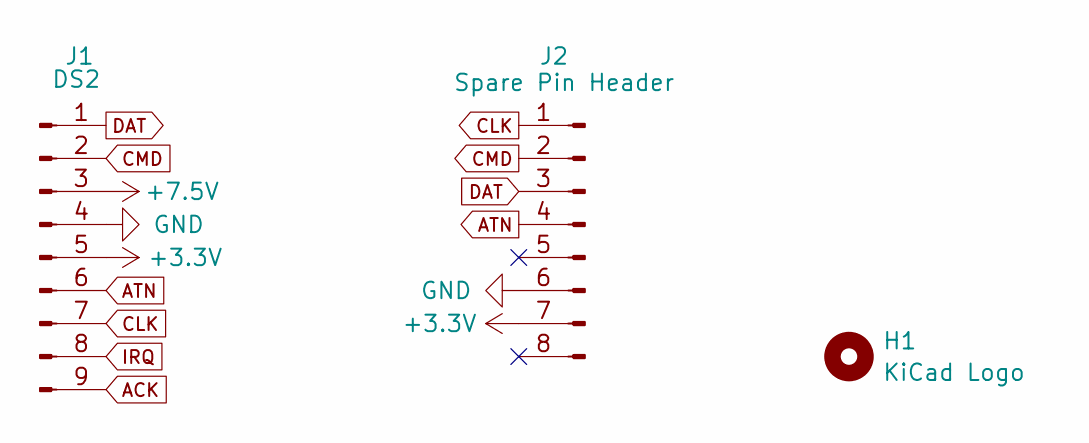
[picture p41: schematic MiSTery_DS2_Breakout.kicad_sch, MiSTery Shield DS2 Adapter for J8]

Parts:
H1: KiCad Logo; KiCad-Logo_5mm_SilkScreen
J1: DS2; DS2_Port_Connector
J2: Spare Pin Header; PinHeader_2x04_P2.54mm_Vertical

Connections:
+3.3V: J1.5, J2.7
+7.5V: J1.3
ACK: J1.9
ATN: J1.6, J2.4
CLK: J1.7, J2.1
CMD: J1.2, J2.2
DAT: J1.1, J2.3
GND: J1.4, J2.6
IRQ: J1.8

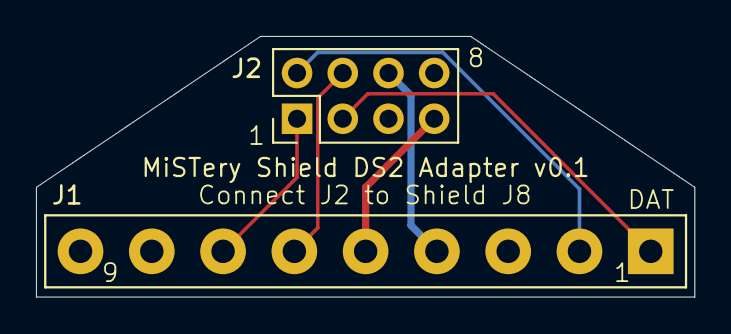
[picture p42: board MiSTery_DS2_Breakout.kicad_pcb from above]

Board: 2 copper layers, 36.6 x 14.5 mm, 3 parts (1 on the bottom side), 6 nets.

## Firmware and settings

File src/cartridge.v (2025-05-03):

/*
	CRT cartridge handling for C64 L.C.Ashmore 2017

	Improvements by Sorgelig
modified for TN20k use 2025 Stefan Voss 
*/

module cartridge
(
	input             clk32,				 	// 32mhz clock source
	input             reset_n,					// reset signal

	input             cart_loading,
	input      [15:0] cart_id,					// cart ID or cart type
	input       [7:0] cart_exrom,				// CRT file EXROM status
	input       [7:0] cart_game,				// CRT file GAME status
	input      [15:0] cart_bank_laddr,		// bank loading address
	input      [15:0] cart_bank_size,		// length of each bank
	input      [15:0] cart_bank_num,
	input       [7:0] cart_bank_type,
	input      [22:0] cart_bank_raddr,		// chip packet address
	input             cart_bank_wr,

	output            exrom,					// exrom line
	output            game,						// game line

	input             romL,						// romL signal in
	input             romH,						// romH signal in
	input             UMAXromH,				// romH VIC II address signal
	input             IOE,						// IOE control signal
	input             IOF,						// IOF control signal
	input             mem_write,				// memory write active
	input             mem_ce,
	output            mem_ce_out,
	output reg        mem_write_out,
	output            IO_rom,					// FLAG to enable IOE/IOF address relocation
	output            IO_rd,
	output reg  [7:0] IO_data,
	input      [15:0] addr_in,             // address from cpu
	input       [7:0] data_in,  			   // data from cpu going to sdram
	output reg [22:0] addr_out, 	         // translated address output

	input             freeze_key,
	input             mod_key,
	output reg        nmi,
	input             nmi_ack
);

reg  [6:0] bank_lo;
reg  [6:0] bank_hi;
reg [12:0] mask_lo;

reg [13:0] geo_bank;
reg  [6:0] IOE_bank;
reg  [6:0] IOF_bank;
reg        IOE_wr_ena;
reg        IOF_wr_ena;

reg        exrom_overide;
reg        game_overide;
assign     exrom = exrom_overide |  force_ultimax;
assign     game  = game_overide  & ~force_ultimax;

reg [6:0] lobanks[0:63];
reg [6:0] hibanks[0:63];

reg  [7:0] bank_cnt;
always @(posedge clk32) begin
	reg old_loading;
	old_loading <= cart_loading;

	if(~old_loading & cart_loading) bank_cnt <= 0;
	if(cart_bank_wr) begin
		bank_cnt <= bank_cnt + 1'd1;
		if(cart_bank_num<64) begin
			if(cart_bank_laddr <= 'h8000) begin
				lobanks[cart_bank_num[5:0]] <= cart_bank_raddr[19:13];
				if(cart_bank_size > 'h2000) hibanks[cart_bank_num[5:0]] <= cart_bank_raddr[19:13]+1'd1;
			end
			else hibanks[cart_bank_num[5:0]] <= cart_bank_raddr[19:13];
		end
	end
end

reg IOE_ena,IOF_ena;
reg IOE_rd,IOF_rd;

assign IO_rom = (IOE & IOE_ena & ~IOE_rd) | (IOF & IOF_ena & ~IOF_rd);
assign IO_rd  = IOE_rd | IOF_rd;

reg romL_we = 0;
reg romH_we = 0;

reg old_ioe, old_iof;
always @(posedge clk32) begin
	old_ioe <= IOE;
	old_iof <= IOF;
end

wire stb_ioe = (~old_ioe & IOE);
wire stb_iof = (~old_iof & IOF);

wire ioe_wr = stb_ioe & mem_write;
wire ioe_rd = stb_ioe & ~mem_write;

wire iof_wr = stb_iof & mem_write;
//wire iof_rd = stb_iof & ~mem_write;

reg  old_freeze = 0;
wire freeze_req = (~old_freeze & freeze_key);

reg  old_nmiack = 0;
wire freeze_ack = (nmi & ~old_nmiack & nmi_ack);
wire freeze_crt = freeze_ack & ~mod_key;

reg  cart_disable = 0;
reg  allow_bank;
reg  ram_bank;
reg  reu_map;
reg  clock_port;
reg  rom_kbb;
reg  force_ultimax;
reg  init_n = 1;
reg  allow_freeze = 0;
reg  saved_d6 = 0;

// 0018 - EXROM line status
// 0019 - GAME line status
always @(posedge clk32) begin
	reg [15:0] count;
	reg        count_ena;
	reg [15:0] old_id;

	old_freeze <= freeze_key;
	if(freeze_req & (allow_freeze | mod_key)) nmi <= 1;

	old_nmiack <= nmi_ack;
	if(freeze_ack) nmi <= 0;

	init_n <= 1;
	old_id <= cart_id;

	if(~reset_n || (old_id != cart_id)) begin
		cart_disable <= 0;
		bank_lo <= 0;
		bank_hi <= 0;
		IOE_ena <= 0;
		IOF_ena <= 0;
		IOE_wr_ena <= 0;
		IOF_wr_ena <= 0;
		romL_we <= 0;
		romH_we <= 0;
		init_n <= 0;
		allow_freeze <= 1;
		nmi <= 0;
		saved_d6 <= 0;
		mask_lo <= 13'h1FFF;
		exrom_overide <= 1;
		game_overide <= 1;
		rom_kbb <= 0;
		geo_bank <= 0;
	end
	else
	case(cart_id)

		// Generic 8k(exrom=0,game=1), 16k(exrom=0,game=0), ULTIMAX(exrom=1,game=0)
		0:	begin
				exrom_overide <= cart_exrom[0];
				game_overide <= cart_game[0];
				bank_lo <= lobanks[0];
				bank_hi <= hibanks[0];
			end

		// Action Replay v4+ - (32k 4x8k banks + 8K RAM)
		// controlled by DE00
		1:	begin
				if(nmi) allow_freeze <= 0;
				if(!init_n || freeze_crt) begin
					cart_disable  <= 0;
					exrom_overide <= 1;
					game_overide  <= 0;
					romL_we <= 0;
					bank_lo <= 0;
					bank_hi <= 0;
					IOF_bank <= 0;
					IOF_wr_ena <= 0;
					IOF_ena <= 1;
					if(~init_n) begin
						exrom_overide <= 0;
						game_overide  <= 1;
					end
				end
				else if(cart_disable) begin
					exrom_overide <= 1;
					game_overide <= 1;
					IOF_ena <= 0;
					IOF_wr_ena <= 0;
					romL_we <= 0;
					allow_freeze <= 1;
				end else begin
					if(ioe_wr) begin
						cart_disable <= data_in[2];
						bank_lo <= data_in[4:3];
						bank_hi <= data_in[4:3];
						IOF_bank <= data_in[4:3];

						if(data_in[6] | allow_freeze) begin
							allow_freeze <= 1;
							game_overide  <= ~data_in[0];
							exrom_overide <=  data_in[1];
							IOF_wr_ena <= data_in[5];
							romL_we <= data_in[5];
							if(data_in[5]) begin
								bank_lo <= 0;
								IOF_bank<= 0;
							end
						end
					end
				end
			end

		// Final Cart III - (64k 4x16k banks)
		// all banks @ $8000-$BFFF - switching by $DFFF
		3:	begin
				if(!init_n) begin
					game_overide <= 0;
					exrom_overide<= 0;
					cart_disable <= 0;
					bank_lo <= 0;
					bank_hi <= 1;
					IOE_ena <= 1;
					IOE_bank<= 0;
					IOF_ena <= 1;
					IOF_bank<= 0;
				end
				else if(!cart_disable) begin
					if(iof_wr && &addr_in[7:0]) begin
						bank_lo <= {data_in[1:0],1'd0};
						bank_hi <= {data_in[1:0],1'd1};
						IOE_bank<= {data_in[1:0],1'd0};
						IOF_bank<= {data_in[1:0],1'd0};
						exrom_overide <= data_in[4];
						game_overide  <= data_in[5];
						saved_d6 <= data_in[6];
						if(~freeze_key & saved_d6 & ~data_in[6]) nmi <= 1;
						if(data_in[6]) allow_freeze <= 1;
						cart_disable <= data_in[7];
					end
				end
				if(freeze_crt) begin
					cart_disable <= 0;
					game_overide <= 0;
					allow_freeze <= 0;
				end
			end

		// Simons Basic - (game=0, exrom=0, 2 banks by 8k)
		// Read to IOE switches 8k config
		// Write to IOE switches 16k config
		4: begin
				if(!init_n) begin
					exrom_overide <= 0;
					game_overide <= 0;
					bank_lo <= 0;
					bank_hi <= 1;
				end
				if(ioe_wr) game_overide <= 0;
				if(ioe_rd) game_overide <= 1;
			end
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

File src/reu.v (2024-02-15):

//
//	REU implementation.
// (C)2021 Alexey Melnikov
//
// modified for TN20k use (REU mapped above 4MB in dram and limit to 512k)  2024 Stefan Voss
//

module reu
(
	input             clk,
	input             reset,
	input       [1:0] cfg, //none, 512K, 2MB (512KB wrap), 16MB

	output reg        dma_req,

	input             dma_cycle,
	output reg [15:0] dma_addr,
	output reg  [7:0] dma_dout,
	input       [7:0] dma_din,
	output            dma_we,
	
	input             ram_cycle,
	output reg [24:0] ram_addr,
	output reg  [7:0] ram_dout,
	input       [7:0] ram_din,
	output reg        ram_we,
	
	input      [15:0] cpu_addr,
	input       [7:0] cpu_dout,
	output reg  [7:0] cpu_din,
	input             cpu_we,
	input             cpu_cs,

	output reg        irq
);

reg ff00_wr;
always @(posedge clk) begin
	reg old_we;
	
	old_we <= cpu_we;
	ff00_wr <= 0;
	if(~old_we && cpu_we && cpu_addr == 'hFF00) ff00_wr <= 1;
end

localparam STATE_IDLE     = 0;
localparam STATE_EVAL     = 1;
localparam STATE_PROC_C64 = 2;
localparam STATE_PROC_RAM = 3;

reg  [19:0] op;
reg   [2:0] stage;
wire [19:0] op_cur = op >> (stage*4);
wire        op_dev = op_cur[0];   // 0: C64, 1: RAM
wire        op_dat = op_cur[1];   // storage
wire  [1:0] op_act = op_cur[3:2]; // 0: read, 1: write, 2: verify, 3: end

reg dma_we_r;
assign dma_we = dma_we_r & dma_cycle;

always @(posedge clk) begin
	reg        old_cs;
	reg  [1:0] state;
	reg  [3:0] cnt;
	reg  [7:0] data[2];
	reg [15:0] addr_c64, addr_c64_r;
	reg [23:0] addr_ram, addr_ram_r;
	reg [15:0] length, length_r;
	reg  [7:0] cmd;
	reg  [7:0] intr;
	reg  [7:0] ctl;
	reg [23:0] addr_mask;
	reg  [7:0] status;
	reg        error;
	
	irq <= (|(status[6:5] & intr[6:5])) & intr[7];

	error = !op_act[0] && data[0] != data[1];
//	addr_mask = ((cfg == 1) ? 24'h7FFFF : (cfg == 2) ? 24'h1FFFFF : 24'hFFFFFF);
	addr_mask = 24'h7FFFF; // limit to 512k size

	old_cs <= cpu_cs;

	if(reset || !cfg) begin
		status     <= 0;
		cmd        <= 'h10;
		addr_c64   <= 0;
		addr_c64_r <= 0;
		addr_ram   <= 0;
		addr_ram_r <= 0;
		length     <= 0;
		length_r   <= 0;
		intr       <= 0;
		ctl        <= 0;
		dma_req    <= 0;
		dma_we_r   <= 0;
		ram_we     <= 0;
		cpu_din    <= 'hFF;
		state      <= STATE_IDLE;
	end
	else begin
		if(~dma_req & ~old_cs & cpu_cs) begin
			if(cpu_we) begin
				case(cpu_addr[4:0])
					 1:       cmd             <= cpu_dout;
					 2: begin addr_c64[7:0]   <= cpu_dout; addr_c64_r[7:0]   <= cpu_dout; end
					 3: begin addr_c64[15:8]  <= cpu_dout; addr_c64_r[15:8]  <= cpu_dout; end
					 4: begin addr_ram[7:0]   <= cpu_dout; addr_ram_r[7:0]   <= cpu_dout; end
					 5: begin addr_ram[15:8]  <= cpu_dout; addr_ram_r[15:8]  <= cpu_dout; end
					 6: begin addr_ram[23:16] <= cpu_dout; addr_ram_r[23:16] <= cpu_dout; end
					 7: begin length[7:0]     <= cpu_dout; length_r[7:0]     <= cpu_dout; end
					 8: begin length[15:8]    <= cpu_dout; length_r[15:8]    <= cpu_dout; end
					 9:       intr            <= cpu_dout;
					10:       ctl             <= cpu_dout;
				endcase
			end
			else begin
				case(cpu_addr[4:0])
					 0: begin cpu_din <= {irq, status[6:5], 1'b1, 4'b0000}; status <= 0; end
					 1: cpu_din <= cmd;
					 2: cpu_din <= addr_c64[7:0];
					 3: cpu_din <= addr_c64[15:8];
					 4: cpu_din <= addr_ram[7:0];
					 5: cpu_din <= addr_ram[15:8];
					 6: cpu_din <= addr_ram[23:16] | ~addr_mask[23:16];
					 7: cpu_din <= length[7:0];
					 8: cpu_din <= length[15:8];
					 9: cpu_din <= {intr[7:5],5'h1F};
					10: cpu_din <= {ctl[7:6],6'h3F};
				default: cpu_din <= 'hFF;
				endcase
			end
		end
	
		case(state)
			STATE_IDLE:
				if(cmd[7] & (cmd[4] | ff00_wr)) begin
					case(cmd[1:0])
						0: op <= 'b1100_1100_1100_0101_0000; // C64 --> RAM
						1: op <= 'b1100_1100_1100_0100_0001; // C64 <-- RAM
						2: op <= 'b1100_0110_0101_0000_0011; // C64 <-> RAM
						3: op <= 'b1100_1100_1000_0000_0011; // C64 =?= RAM
					endcase
					dma_req    <= 1;
					stage      <= 0;
					state      <= STATE_EVAL;
					addr_ram   <= addr_ram & addr_mask;
					addr_ram_r <= addr_ram_r & addr_mask;
				end

			STATE_EVAL:
				begin
					cnt <= 0;
					if(op_act[1]) begin
						if(~ctl[7]) addr_c64 <= addr_c64 + 1'd1;
						if(~ctl[6]) addr_ram <= (cfg == 2) ? {addr_ram[20:19], addr_ram[18:0] + 1'd1} : ((addr_ram + 1'd1) & addr_mask);
						stage <= 0;
						if(length == 1 || error) begin
							if(cmd[5]) begin
								addr_ram <= addr_ram_r;
								addr_c64 <= addr_c64_r;
								length   <= length_r;
							end
							status[6] <= 1;
							if(error) status[5] <= 1;
							cmd[4]    <= 1;
							cmd[7]    <= 0;
							dma_req   <= 0;
							state     <= STATE_IDLE;
						end
						else length  <= length - 1'd1;
					end
					else if(op_dev) begin
						if (~ram_cycle) begin
//							ram_addr  <= {1'b1, addr_ram};
							ram_addr[24:0]  <= {3'b001, addr_ram[21:0] }; // REU mapped above 4MB in dram
							ram_we    <= op_act[0];
							ram_dout  <= data[op_dat];
							state     <= STATE_PROC_RAM;
						end
					end
					else begin
						if(~dma_cycle) begin
							dma_addr  <= addr_c64;
							dma_we_r  <= op_act[0];
							dma_dout  <= data[op_dat];
							state     <= STATE_PROC_C64;
						end
					end
				end

			STATE_PROC_RAM:
				if(ram_cycle) begin
					cnt    <= cnt + 1'd1;
					if(&cnt[1:0]) begin
						data[op_dat] <= ram_din;
						ram_we       <= 0;
						stage        <= stage + 1'd1;
						state        <= STATE_EVAL;
					end
				end

			STATE_PROC_C64:
				if(dma_cycle) begin
					cnt <= cnt + 1'd1;
					if(&cnt[3:0]) begin
						dma_addr     <= 0; // make sure we won't read some device's data while idling.
						dma_we_r     <= 0;
						data[op_dat] <= dma_din;
						stage        <= stage + 1'd1;
						state        <= STATE_EVAL;
					end
				end
		endcase
	end
end

endmodule

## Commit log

2023-11-04 Dev c1541 sd (#10)
    support for emulated c1541 on raw sdcard added
    support for Joystick on Numkeypad added
    pinmaps for Keyboard and Joystick aligned with ST project (sorry for all who need to change their wiring now...)
    component updates 6526 CIA and VIC II from Mister
2023-11-28 minor fixes and gowin 1.9.9 upd
    [device.cfg]
2023-11-28 Dev spi bl616 interface (#16)
    [device.cfg]
2023-12-19 catch up with bl616 firmware (#17)
    [device.cfg]
2024-02-12 C1541 dos rom move to spi Flash (#32)
    [device.cfg]
2024-02-15 dram controller adjustment 8 bit width (#38)
    [device.cfg]
2024-02-23 pal ntsc mode switch (#39)
    [device.cfg]
2024-02-23 bugfix (#42)
    [device.cfg]
2024-02-25 43 tang primer 25k support (#44)
    [device.cfg]
2024-05-24 55 tape sound and userport uart option (#58)
    [device.cfg]
2024-06-20 69 loadable sid filter (#72)
2024-06-25 74 fix buggy release v130 (#75)
    [cartridge.v]
2024-06-25 add temporary sid filter curves
2024-07-10 Crt fix (#78)
    [device.cfg]
2024-09-11 UART HW pin Interface (#87)
2024-09-11 UART HW pin Interface
2024-10-04 enhanement (#92)
    [device.cfg]
2024-10-04 extra button fix
2024-10-19 freezer fix for action CRT cards (#95)
    [cartridge.v]
2024-11-01 Bugfix (#105)
    [device.cfg]
2024-11-07 tm60k fix c1541 and led (#112)
2025-01-15 LCD (#118)
    [MiSTery_DS2_Breakout-B_Cu.gbr, MiSTery_DS2_Breakout-B_Mask.gbr, MiSTery_DS2_Breakout-B_Paste.gbr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]
2025-02-05 MisteryShield20k_RPiPico (#120)
    [MiSTeryShield20kRPiPico-B_Cu.gbl, MiSTeryShield20kRPiPico-B_Mask.gbs, MiSTeryShield20kRPiPico-B_Paste.gbp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]
2025-02-24 readme board
2025-02-25 board readme and picture
2025-03-19 pizero pcba design (#130)
    [bom.csv, designators.csv, pizero_pmod.kicad_pcb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]
2025-03-29 Shieldnods2 (#133)
    [MiSTeryShield20kRPiPico-B_Cu.gbl, MiSTeryShield20kRPiPico-B_Mask.gbs, MiSTeryShield20kRPiPico-B_Paste.gbp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]
2025-05-03 keyboard improvement (#141)
    Auto shift press for Function Key F2, F4, F6, F8, Cursor UP / LEFT and INSERT
    Keyboard Key corrections HOME, INSERT, DELETE
    Cartridge support for Waterloo Structured BASIC and BMP-Data Turbo 2000
    Numpad Joystick moved to Core
    [cartridge.v]
2025-08-09 board update (#156)
    [MiSTeryShield20kRPiPico-B_Cu.gbl, MiSTeryShield20kRPiPico-B_Mask.gbs, MiSTeryShield20kRPiPico-B_Paste.gbp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]

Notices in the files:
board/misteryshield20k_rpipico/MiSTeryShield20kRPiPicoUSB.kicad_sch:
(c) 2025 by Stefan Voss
